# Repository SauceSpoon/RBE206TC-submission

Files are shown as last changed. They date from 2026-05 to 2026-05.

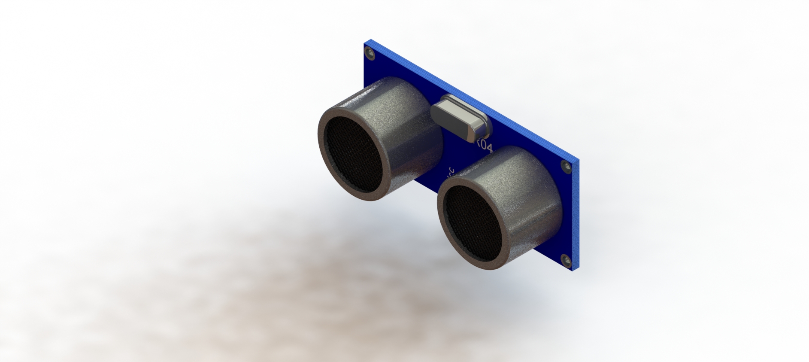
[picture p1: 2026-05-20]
oodk(CAD model)/odk3（Generation 3）/超声波传感器 HC-SR04/Untitled.JPG

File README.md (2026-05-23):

RBE206TC-submission

Some Statement: Due to file path issues, some ESP32 code files may not be decompressed directly, but all CAD and report documents can be opened normally. In order to avoid unnecessary misunderstandings, the code part is stored separately in another compressed package in the mailbox. Even so, most of the functional implementations are still relatively complete.

Project Overview

This repository serves as the final submission for the RBE206TC course. It encompasses the complete project lifecycle, including the firmware source code for ESP32 wireless communication, the mechanical CAD models for the OODK, and the comprehensive final report and presentation slides.

Team Members
Member Name: [Yanyang.Nan, JiaRui.Li, Jian.Wang, Xinhang.Li]

Directory Structure
This repository is organized into the following directories and files:

ESP32-source

Content: Firmware source code for the ESP32 microcontroller.
Functionality: Implements wireless connectivity, flashing procedures, and control logic.

oodk(CAD model)

Content: 3D CAD models of the OODK.
Formats: Includes source files (e.g., SolidWorks/STEP) and renderings.
Purpose: Demonstrates the mechanical structure design and assembly details.

Report and powerpoint

Content: Project documentation.
Includes:
Project Report (PDF/Word)
Presentation Slides (PPT)

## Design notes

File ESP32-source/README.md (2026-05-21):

#ESP32 Robot Graphical Web Control and Burning Station

The first version of the project implemented according to the first phase goals of `esp_32_robot_web_flasher_control_plan.md` contains four parts:

- `apps/web`: React + Vite graphical console
- `apps/server`: Node.js + Express local control service
- `firmware/esp32_robot_controller`: ESP32 Arduino/PlatformIO example firmware
- `firmware/esp32_cam_streamer`: Standalone ESP32-CAM streaming firmware

## Current capabilities

- Enter the IP on the web page and connect to the robot
- The web page independently connects to ESP32-CAM and displays real-time video streams and snapshot previews
- Forward browser control commands to ESP32 through local services
- A new local script chat window has been added to the control page, and Chinese scripts can be used to directly drive the servo.
- Natural language can be planned into a whitelist script through local Ollama / Gemma, and then handed over to the local service for execution
- Supports action buttons, emergency stop, attitude return, and 7-way servo slider
- Upload `.bin` firmware and push to ESP32 via OTA
- The camera module also supports remote upgrade via Wi-Fi OTA
- Reserve USB burning entrance as first time burning/brick rescue mode
- Automatically scan and display available serial devices, and the page will automatically refresh after plugging and unplugging.
- Camera images can be forwarded through the local service proxy, and the stream can also be viewed when the console is opened remotely
- Status, log, delay, battery, motor angle and other information are displayed in real time on the page

## PCA9685 Wiring

- The current firmware outputs servo PWM through PCA9685 and no longer directly uses ESP32 GPIO to control the servo.
- Default I2C wiring: ESP32 `GPIO 21 -> SDA`, `GPIO 22 -> SCL`
- Default servo channel mapping: servo `1/2/3` on the web page corresponds to PCA9685 channel `0/1/2`
- PCA9685 logic power supply `VCC` is recommended to be connected to ESP32 `3.3V`
- Servo power supply `V+` continues to be connected to the output of your buck module
- `ESP32 GND`, `PCA9685 GND`, and the battery negative pole must be grounded together

## Directory structure

```text
ESP32/
├─ apps/
│ ├─ server/ # Local control service
│ └─ web/ # Web console
├─ firmware/
│ ├─ esp32_robot_controller/
│ ├─ include/
│ ├─ src/
│ └─ platformio.ini
│ └─ esp32_cam_streamer/
│ ├─ include/
│ ├─ src/
│ └─ platformio.ini
├─docs/
│ └─ flash-version-workflow.md
├─ .github/workflows/
│ └─ ci.yml
└─ README.md
```

## GitHub warehouse and version management

This directory should be maintained as a single repository for "all robot programming-related codes" to avoid future occurrences:

- Only the board code was changed, but the Web/Server protocol changes were not saved simultaneously.
- Directly overwrites the last stable function, causing a certain ability to be removed.
- The burning was successful, but I can’t find which version of the code it corresponded to when I looked back.

Recommended execution method:

1. Submit the code before each preparation.
2. Add Git tag after each verification is stable.
3. New features are always developed in branches and do not directly cover the stable version.
4. After pushing to GitHub, treat GitHub as the only remote backup.

For the complete process, see [docs/flash-version-workflow.md](/Users/yanyangnan/Desktop/ESP32/docs/flash-version-workflow.md).

## Quick start

### 1. Install dependencies

Execute in the project root directory:

```bash
npm install
```

### 2. Start local service

```bash
npm run dev:server
```

Listens to `http://localhost:3001` by default.

If you need to customize the configuration, copy [apps/server/.env.example](/Users/yanyangnan/Desktop/ESP32/apps/server/.env.example) to `.env` and modify it.

If you want to connect to local Ollama / Gemma, first make sure Ollama is started and the model name can be seen in `ollama list`, and then configure it in [apps/server/.env](/Users/yanyangnan/Desktop/ESP32/apps/server/.env):

```bash
OLLAMA_BASE_URL=http://127.0.0.1:11434
OLLAMA_MODEL=gemma4:26b
OLLAMA_TIMEOUT_MS=30000
```

The model name must use the name displayed in your local `ollama list`; if it is actually called `gemma3:4b`, `gemma3n` or other names, change `OLLAMA_MODEL` to the corresponding value.

### 3. Start the web console

```bash
npm run dev:web
```

The default development address is `http://localhost:5173`.

If you need to modify the API address, copy [apps/web/.env.example](/Users/yanyangnan/Desktop/ESP32/apps/web/.env.example) to `.env`.

### 4. Burn in ESP32 base firmware

Enter [firmware/esp32_robot_controller](/Users/yanyangnan/Desktop/ESP32/firmware/esp32_robot_controller):

```bash
pio run -t upload
```

Before using it for the first time, please copy [include/secrets.example.h](/Users/yanyangnan/Desktop/ESP32/firmware/esp32_robot_controller/include/secrets.example.h) to `secrets.h`, and then modify the Wi‑Fi information in it.

### 5. Burn standalone ESP32-CAM firmware

Enter [firmware/esp32_cam_streamer](/Users/yanyangnan/Desktop/ESP32/firmware/esp32_cam_streamer):

```bash
pio run -t upload
```

Copy [include/secrets.example.h](/Users/yanyangnan/Desktop/ESP32/firmware/esp32_cam_streamer/include/secrets.example.h) to `secrets.h`, fill in Wi‑Fi, and then burn. By default it will provide:

- `/stream`: MJPEG real-time video stream
- `/capture`: single frame capture
- `/status`: camera parameters and online status
- `/health`: health check
- `/update`: camera firmware OTA update entrance

### 6. Unified verification

Before preparing to burn or push to GitHub, it is recommended to execute:

```bash
npm run check
```

This checks in order:

- Is the web front end buildable?
- Whether the syntax of the local server-side JS file passes
- Whether the robot main control firmware can be compiled
- Is the camera firmware compilable?

## Run process

1. Use USB to burn the basic firmware with OTA into ESP32
2. Open the Web console, enter the robot IP and connect
3. Send control commands through action buttons and sliders
4. Select the `.bin` firmware and upload it to the local service
5. Select the burning target (robot master/camera module) and OTA/USB mode
6. Click "Upload and Upgrade", the local service will push the firmware to `/update` of the corresponding device
7. Camera preview uses local service proxies `/api/camera/stream` and `/api/camera/snapshot` by default

## Local Service API

- `POST /api/connect`
- `POST /api/disconnect`
- `POST /api/camera/connect`
- `POST /api/camera/disconnect`
- `GET /api/status`
- `GET /api/camera/status`
- `GET /api/camera/stream`
- `GET /api/camera/snapshot`
- `POST /api/firmware/upload`
- `POST /api/firmware/flash`
- `POST /api/script/run`
- `POST /api/script/stop`
- `POST /api/brain/run`
- `POST /api/control`
- `GET /api/serial/ports`
- `GET /api/health`
- `WS /ws`: Push status and logs to the web frontend

## USB burning instructions

`POST /api/firmware/flash` supports:

- `target: "robot" | "camera"`
- `mode: "ota" | "usb"`

Among them `mode: "usb"` is called by default:

```bash
python3 -m esptool --chip esp32 --port <port> --baud <baudRate> write_flash 0x10000 <file>
```

This is a simplified writing method for OTA application partitions, suitable for devices that already have a basic partition table. If you need to completely burn the bootloader / partitions / app for the first time, please adjust the offset and command strategy in [apps/server/.env.example](/Users/yanyangnan/Desktop/ESP32/apps/server/.env.example).

## ESP32 firmware dependencies

It is recommended to use PlatformIO, which has been declared in [platformio.ini](/Users/yanyangnan/Desktop/ESP32/firmware/esp32_robot_controller/platformio.ini):

- `ESP Async WebServer`
- `AsyncTCP`
- `ArduinoJson`
- `ESP32Servo`

## Suggestions for subsequent expansion

- Automatically scan LAN devices
- Action recording/playback
-Multi-robot switching
- IMU visualization
- Camera streaming
- More complete USB first-time burning process

# ESP32 机器人图形化 Web 控制与烧录台

按 `esp_32_robot_web_flasher_control_plan.md` 的第一阶段目标实现的初版项目，包含四部分：

- `apps/web`：React + Vite 图形化控制台
- `apps/server`：Node.js + Express 本地控制服务
- `firmware/esp32_robot_controller`：ESP32 Arduino / PlatformIO 示例固件
- `firmware/esp32_cam_streamer`：独立 ESP32-CAM 串流固件

## 当前能力

- Web 页面输入 IP 并连接机器人
- Web 页面独立连接 ESP32-CAM，并显示实时视频流与抓拍预览
- 通过本地服务把浏览器控制指令转发到 ESP32
- 控制页新增本地脚本聊天窗口，可用中文脚本直接驱动舵机
- 可通过本地 Ollama / Gemma 把自然语言规划成白名单脚本，再交给本地服务执行
- 支持动作按钮、急停、姿态回中、7 路舵机滑块
- 上传 `.bin` 固件并通过 OTA 推送到 ESP32
- 相机模块同样支持通过 Wi-Fi OTA 远程升级
- 保留 USB 烧录入口，作为首次烧录/救砖模式
- 自动扫描并显示可用串口设备，插拔后页面自动刷新
- 相机画面可通过本地服务代理转发，远程打开控制台时也能看流
- 状态、日志、延迟、电池、电机角度等信息在页面里实时显示

## PCA9685 接线

- 当前固件通过 PCA9685 输出舵机 PWM，不再直接使用 ESP32 GPIO 控舵机
- 默认 I2C 接线：ESP32 `GPIO 21 -> SDA`，`GPIO 22 -> SCL`
- 默认舵机通道映射：网页的舵机 `1/2/3` 对应 PCA9685 通道 `0/1/2`
- PCA9685 逻辑电源 `VCC` 建议接 ESP32 `3.3V`
- 舵机电源 `V+` 继续接你的降压模块输出
- `ESP32 GND`、`PCA9685 GND`、电池负极必须共地

## 目录结构

```text
ESP32/
├─ apps/
│  ├─ server/   # 本地控制服务
│  └─ web/      # Web 控制台
├─ firmware/
│  ├─ esp32_robot_controller/
│     ├─ include/
│     ├─ src/
│     └─ platformio.ini
│  └─ esp32_cam_streamer/
│     ├─ include/
│     ├─ src/
│     └─ platformio.ini
├─ docs/
│  └─ flash-version-workflow.md
├─ .github/workflows/
│  └─ ci.yml
└─ README.md
```

## GitHub 仓库与版本管理

这个目录应作为“机器人所有烧录相关代码”的单一仓库来维护，避免以后出现：

- 只改了板端代码，但没同步保存 Web / Server 协议变更
- 直接覆盖上一次稳定功能，导致某个能力被顶掉
- 烧录成功了，但回头找不到当时对应的是哪一版代码

推荐执行方式：

1. 每次准备烧录前先提交代码。
2. 每次验证稳定后打 Git tag。
3. 新功能一律在分支开发，不直接覆盖稳定版。
4. 推送到 GitHub 后，把 GitHub 当作唯一远程备份。

完整流程见 [docs/flash-version-workflow.md](/Users/yanyangnan/Desktop/ESP32/docs/flash-version-workflow.md)。

## 快速开始

### 1. 安装依赖

在项目根目录执行：

```bash
npm install
```

### 2. 启动本地服务

```bash
npm run dev:server
```

默认监听 `http://localhost:3001`。

如需自定义配置，复制 [apps/server/.env.example](/Users/yanyangnan/Desktop/ESP32/apps/server/.env.example) 为 `.env` 后修改。

如果要接入本地 Ollama / Gemma，先确认 Ollama 已启动并且模型名能在 `ollama list` 里看到，然后在 [apps/server/.env](/Users/yanyangnan/Desktop/ESP32/apps/server/.env) 中配置：

```bash
OLLAMA_BASE_URL=http://127.0.0.1:11434
OLLAMA_MODEL=gemma4:26b
OLLAMA_TIMEOUT_MS=30000
```

模型名必须使用你本机 `ollama list` 显示的名字；如果实际叫 `gemma3:4b`、`gemma3n` 或其他名字，就把 `OLLAMA_MODEL` 改成对应值。

### 3. 启动 Web 控制台

```bash
npm run dev:web
```

默认开发地址为 `http://localhost:5173`。

如需修改 API 地址，复制 [apps/web/.env.example](/Users/yanyangnan/Desktop/ESP32/apps/web/.env.example) 为 `.env`。

### 4. 烧入 ESP32 基础固件

进入 [firmware/esp32_robot_controller](/Users/yanyangnan/Desktop/ESP32/firmware/esp32_robot_controller)：

```bash
pio run -t upload
```

首次使用前请先把 [include/secrets.example.h](/Users/yanyangnan/Desktop/ESP32/firmware/esp32_robot_controller/include/secrets.example.h) 复制为 `secrets.h`，再修改其中的 Wi‑Fi 信息。

### 5. 烧入独立 ESP32-CAM 固件

进入 [firmware/esp32_cam_streamer](/Users/yanyangnan/Desktop/ESP32/firmware/esp32_cam_streamer)：

```bash
pio run -t upload
```

把 [include/secrets.example.h](/Users/yanyangnan/Desktop/ESP32/firmware/esp32_cam_streamer/include/secrets.example.h) 复制为 `secrets.h` 后填好 Wi‑Fi，再烧录。默认会提供：

- `/stream`：MJPEG 实时视频流
- `/capture`：单帧抓拍
- `/status`：相机参数和在线状态
- `/health`：健康检查
- `/update`：相机固件 OTA 更新入口

### 6. 统一校验

在准备烧录或推送到 GitHub 前，建议先执行：

```bash
npm run check
```

这会依次检查：

- Web 前端是否可构建
- 本地服务端 JS 文件是否语法通过
- 机器人主控固件是否可编译
- 相机固件是否可编译

## 运行流程

1. 用 USB 给 ESP32 烧入带 OTA 的基础固件
2. 打开 Web 控制台，输入机器人 IP 并连接
3. 通过动作按钮、滑块发送控制命令
4. 选择 `.bin` 固件，上传到本地服务
5. 选择烧录目标（机器人主控 / 相机模块）和 OTA / USB 模式
6. 点击“上传并升级”，本地服务会把固件推送到对应设备的 `/update`
7. 相机预览默认走本地服务代理 `/api/camera/stream` 和 `/api/camera/snapshot`

## 本地服务 API

- `POST /api/connect`
- `POST /api/disconnect`
- `POST /api/camera/connect`
- `POST /api/camera/disconnect`
- `GET /api/status`
- `GET /api/camera/status`
- `GET /api/camera/stream`
- `GET /api/camera/snapshot`
- `POST /api/firmware/upload`
- `POST /api/firmware/flash`
- `POST /api/script/run`
- `POST /api/script/stop`
- `POST /api/brain/run`
- `POST /api/control`
- `GET /api/serial/ports`
- `GET /api/health`
- `WS /ws`：向 Web 前端推送状态和日志

## USB 烧录说明

`POST /api/firmware/flash` 支持：

- `target: "robot" | "camera"`
- `mode: "ota" | "usb"`

其中 `mode: "usb"` 默认调用：

```bash
python3 -m esptool --chip esp32 --port <port> --baud <baudRate> write_flash 0x10000 <file>
```

这是面向 OTA 应用分区的简化写入方式，适合已具备基本分区表的设备。若你需要首次完整烧录 bootloader / partitions / app，请自行调整 [apps/server/.env.example](/Users/yanyangnan/Desktop/ESP32/apps/server/.env.example) 中的偏移与命令策略。

## ESP32 固件依赖

建议使用 PlatformIO，已在 [platformio.ini](/Users/yanyangnan/Desktop/ESP32/firmware/esp32_robot_controller/platformio.ini) 中声明：

- `ESP Async WebServer`
- `AsyncTCP`
- `ArduinoJson`
- `ESP32Servo`

## 后续扩展建议

- 自动扫描局域网设备
- 动作录制 / 回放
- 多机器人切换
- IMU 可视化
- 摄像头串流
- 更完整的 USB 首次烧录流程

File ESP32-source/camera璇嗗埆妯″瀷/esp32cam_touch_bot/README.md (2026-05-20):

# ESP32-CAM Touch Bot Framework

This is a starter framework for the competition flow:

1. Draw target (color + shape)
2. Camera scans candidates
3. Robot aligns to target
4. Robot approaches and touches target

## Files

- esp32cam_touch_bot.ino: main state machine
- Config.h: pins and thresholds
- VisionPipeline.*: camera + color/shape detection
- ShapeClassifier.*: placeholder shape classifier (replace by model)
- MotorControl.*: simple motor driver wrapper

## How to use

1. Open `esp32cam_touch_bot` folder in Arduino IDE.
2. Select board: `AI Thinker ESP32-CAM`.
3. Install ESP32 board package in Board Manager if needed.
4. Confirm motor pins in Config.h.
5. Set your draw target in Config.h:

```cpp
constexpr TargetSpec TARGET = {ColorId::RED, ShapeId::PYRAMID};
```

6. Upload and open serial monitor at 115200.

## Image collection first

Before model training, complete image collection with the dedicated guide:

- IMAGE_COLLECTION.md

Batch capture script:

- tools/capture_dataset.sh
- tools/collect_12_classes.sh
- tools/audit_dataset.sh
- tools/prepare_photodata.sh
- tools/prepare_shape_model_dataset.sh

Competition classes:

- colors: black, blue, green, red
- shapes: cube, ball, pyramid
- total: 12 labels, e.g. black_cube, blue_ball, red_pyramid

Quick example:

```bash
chmod +x tools/capture_dataset.sh
./tools/capture_dataset.sh -i 192.168.1.88 -l red_cube -n 300 -o dataset/raw -t 0.35
./tools/collect_12_classes.sh -i 192.168.1.88 -n 250 -o dataset/raw -t 0.35
./tools/audit_dataset.sh -d dataset/raw -m 250
./tools/prepare_photodata.sh --clean
./tools/prepare_shape_model_dataset.sh --clean
./tools/prepare_shape_model_dataset.sh --clean -o dataset/shape_model_balanced --max-per-shape 365
```

## Next step: replace shape classifier with Edge Impulse

In `ShapeClassifier.cpp`, replace `classifyShapeHeuristic(...)` with model inference result mapping.

Train the first model from `dataset/shape_model_balanced`:

- input: cropped object image
- outputs: cube, ball, pyramid
- recommended input size: 64x64 or 96x96 RGB
- deployment target: int8 Arduino library

Local PyTorch baseline:

```bash
/Users/yanyangnan/miniforge3/bin/python tools/train_shape_model.py \
  --data-dir dataset/shape_model_balanced \
  --out-dir models/shape_classifier \
  --image-size 96 \
  --epochs 50 \
  --batch-size 32
```

Current baseline result:

- best validation accuracy: 97.26%
- best epoch: 45
- outputs: models/shape_classifier/best.pt, best_torchscript.pt, metrics.json

Robust v2 training for imperfect ROI crops:

```bash
/Users/yanyangnan/miniforge3/bin/python tools/train_shape_model.py \
  --data-dir dataset/shape_model \
  --out-dir models/shape_classifier_v2_full_hard \
  --image-size 96 \
  --epochs 50 \
  --batch-size 32 \
  --aug-profile hard \
  --balanced-sampler \
  --class-weighted-loss
```

Current v2 result:

- best validation accuracy: 92.59%
- best epoch: 44
- outputs: models/shape_classifier_v2_full_hard/best.pt, best_torchscript.pt, metrics.json
- composite test detections: 88, down from 95 with the first model
- practical note: v2 is less overconfident on single-object validation and improves red cube behavior in composite scenes

Composite-scene test:

```bash
/Users/yanyangnan/miniforge3/bin/python tools/test_composite_photos.py \
  --image-dir ../照片/组合 \
  --model models/shape_classifier_v2_full_hard/best.pt \
  --out-dir models/shape_classifier_v2_full_hard/composite_test_strict
```

Live camera test before Arduino deployment:

```bash
# ESP32-CAM CameraWebServer capture endpoint
/Users/yanyangnan/miniforge3/bin/python tools/live_camera_test.py \
  --esp32-ip 192.168.1.88 \
  --target red_cube \
  --frames 0

# USB camera or Mac camera
/Users/yanyangnan/miniforge3/bin/python tools/live_camera_test.py \
  --source 0 \
  --target red_cube \
  --frames 0
```

Hard-example collection from the live ESP32-CAM view:

```bash
/Users/yanyangnan/miniforge3/bin/python tools/live_camera_test.py \
  --esp32-ip 172.20.10.2 \
  --focus-color red \
  --frames 0 \
  --display \
  --collect-dir dataset/live_hard_shape_rois
```

When the displayed ROI is wrong, press the true shape key:

- `c`: choose cube
- `b`: choose ball
- `p`: choose pyramid
- `Enter`: confirm and save the shown ROI
- `Esc`: cancel the pending label
- `q`: quit

Use `--focus-color` to collect one object color at a time. For example, use `--focus-color red` when collecting red cube failure cases, and keep only that target object under the camera.

Task1 marker and boundary calibration images:

```bash
./tools/collect_competition_markers.sh -i 172.20.10.11 -n 150 -o dataset/competition_markers -t 0.35
```

This collects raw images into:

- `yellow_column`: yellow obstacle columns
- `black_column`: the black goal column only
- `black_boundary_line`: boundary line without the goal column
- `background_negative`: floor, shadows, empty scene, and robot body negatives

Use these buckets first for HSV threshold tuning. Train a model only if color rules are not stable enough under competition lighting.

After collecting hard examples, build and train v3:

```bash
./tools/prepare_v3_shape_dataset.sh --clean

/Users/yanyangnan/miniforge3/bin/python tools/train_shape_model.py \
  --data-dir dataset/shape_model_v3_live_hard \
  --out-dir models/shape_classifier_v3_live_hard \
  --image-size 96 \
  --epochs 50 \
  --batch-size 32 \
  --aug-profile hard \
  --balanced-sampler \
  --class-weighted-loss
```

Suggested mapping:

- model output index 0 -> ShapeId::CUBE
- model output index 1 -> ShapeId::BALL
- model output index 2 -> ShapeId::PYRAMID

## Notes

- This version keeps logic light for ESP32-CAM.
- HSV ranges may need tuning for your lighting.
- For better reliability, keep white balance/exposure fixed.

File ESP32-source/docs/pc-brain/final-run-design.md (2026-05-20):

# PC Brain Final Run Design

## Goal

Add a parallel local-computer brain path without deleting or replacing the existing ESP32-side and manual Web control paths.

The PC Brain path is used for the automated teacher-facing flow:

1. Connect the robot controller.
2. Connect the ESP32-CAM.
3. Select the target object.
4. Start PC Brain.
5. The computer reads camera detections, decides the task phase, sends motion commands, and stops automatically.

## Architecture

```text
ESP32-CAM
  -> Python OpenCV detector on the computer
  -> Node PC Brain endpoint
  -> FinalRunManager task state machine
  -> RobotManager / SimulationManager
  -> ESP32 robot controller
```

The original manual control page continues to use `/api/control`. The new PC Brain path uses `/api/pc-brain/*` and only sends robot commands after `/api/pc-brain/start` has been called.

## Responsibilities

- ESP32-CAM: video capture only.
- Python detector: OpenCV frame reading, HSV segmentation, contour extraction, detection JSON posting.
- Node PC Brain: run state, input validation, activity timeout metadata, forwarding detections to FinalRunManager.
- FinalRunManager: competition phase logic and robot motion commands.
- ESP32 robot controller: execute commands, keep OTA/manual control capability, enforce board-side safety timeout.

## Isolation Rules

- Existing code and docs remain in place.
- PC Brain starts stopped by default.
- Vision events posted while PC Brain is stopped are recorded as ignored and do not command the robot.
- Manual Web control remains available when PC Brain is stopped.
- Emergency stop is always allowed.
- If PC Brain is running, ordinary manual movement should be treated as a mode conflict unless the operator stops PC Brain first.

## First Implementation Slice

- Add a `pcBrain` state block to the server snapshot.
- Add a `PcBrainManager` with `start`, `stop`, and `applyVision`.
- Add `/api/pc-brain/start`, `/api/pc-brain/stop`, `/api/pc-brain/vision`, and `/api/pc-brain/status`.
- Add a Python detector client skeleton that reads ESP32-CAM frames and posts detections to the Node service.

## Operator Flow

1. Start the Node server and Web console.
2. Connect the robot controller and ESP32-CAM from the Web console.
3. If the lighting changed, calibrate each color before the run:

```bash
python3 apps/server/tools/pc_brain_opencv.py \
  --camera http://ESP32_CAM_IP/stream \
  --calibrate red
```

Use the HSV sliders until the mask isolates the target color. Press `s` to save the current range to `apps/server/tools/pc_brain_hsv.json`, then press `q` to quit. Repeat for `blue`, `green`, `yellow`, and `black` as needed.

4. Start the Python detector:

```bash
python3 apps/server/tools/pc_brain_opencv.py \
  --camera http://ESP32_CAM_IP/stream \
  --server http://127.0.0.1:3001 \
  --shape-model camera识别模型/esp32cam_touch_bot/models/shape_classifier_v3_live_hard/best.pt \
  --rotate-180 \
  --flip-horizontal \
  --display
```

If the camera is running the Arduino `CameraWebServer` reference sketch, use:

```bash
python3 apps/server/tools/pc_brain_opencv.py \
  --camera http://ESP32_CAM_IP:81/stream \
  --server http://127.0.0.1:3001 \
  --shape-model camera识别模型/esp32cam_touch_bot/models/shape_classifier_v3_live_hard/best.pt \
  --rotate-180 \
  --flip-horizontal \
  --display
```

With `--shape-model`, color is still detected by HSV, but cube/ball/pyramid shape comes from the trained PyTorch model. If the option is omitted, the detector falls back to contour shape heuristics.

5. In the Final Go page, choose the target and click `PC Brain 自动开始`.
6. The detector posts vision frames to `/api/pc-brain/vision`; the server decides and sends movement commands.
7. Click `停止 PC Brain` or the normal emergency stop if the run must be interrupted.

## Rollback

This is additive. To return to the previous workflow, stop PC Brain and keep using the existing Web control page, camera page, and Final Go page.

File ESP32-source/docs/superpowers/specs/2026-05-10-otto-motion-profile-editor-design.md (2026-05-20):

# Otto 动作参数编辑器 Design

**Goal:** 在 Otto 控制页新增一个可持久保存的动作参数编辑器，让用户为每个运动动作单独调节关节幅度，支持恢复当前动作默认值、临时试跑、保存到机器人。

**Architecture:** 机器人端保存每个 Otto 动作的参数档案，Web 端把这些档案渲染成可编辑草稿并通过本地存储记住未保存修改。运动按钮仍然只负责发动作命令；编辑器只负责选中当前动作、调整参数、试跑当前草稿和保存当前草稿。  
试跑通过把草稿作为临时 profile 下发给机器人实现，不写入持久存储；保存则写入 ESP32 `Preferences`，并同步回 Web 状态。

**Tech Stack:** React, Vite, ESP32 Arduino, `Preferences`, `ArduinoJson`, localStorage

---

## Scope

### In scope
- Otto 控制页新增“动作参数编辑器”
- 支持动作档案：`otto_forward`、`otto_backward`、`otto_left`、`otto_right`、`otto_shift_left`、`otto_shift_right`
- 每个动作独立保存一组关节幅度参数
- 支持“恢复当前动作默认值”
- 支持“测试当前动作”
- 支持“保存到机器人”
- Web 重启后保留未保存草稿
- 机器人重启后保留已保存参数

### Out of scope
- 不修改 Otto 的相位/偏移公式，只暴露幅度参数
- 不把“恢复默认值”做成自动写入持久存储
- 不改其他普通舵机零位校准逻辑

## Data Model

### Otto motion profile
Each profile stores four floats:
- `leftLegAmplitudeDeg`
- `rightLegAmplitudeDeg`
- `leftHipAmplitudeDeg`
- `rightHipAmplitudeDeg`

### Profile defaults
Defaults stay aligned with current gait logic:
- `otto_forward` and `otto_backward`
  - left leg 12.0
  - right leg 10.5
  - left hip 18.0
  - right hip 16.5
- `otto_left`
  - left leg 18.0
  - right leg 7.0
  - left hip 12.0
  - right hip 12.0
- `otto_right`
  - left leg 7.0
  - right leg 18.0
  - left hip 12.0
  - right hip 12.0
- `otto_shift_left` and `otto_shift_right`
  - left leg 12.0
  - right leg 12.0
  - left hip 10.0
  - right hip 10.0

### Persistence rules
- Robot-side saved profiles live in `Preferences`
- Web-side drafts live in `localStorage`
- If the user never clicks save, the last draft stays in the browser after refresh/reopen
- If the user clicks save, the robot-side profile becomes the saved value that future button presses use

## UI Behavior

### Movement area
- Buttons still execute the current Otto motion immediately
- Buttons do not save or reset profiles
- Clicking a motion button does not need to auto-switch the editor if that would make the separation feel too tight

### Editor area
- Shows one selected motion profile at a time
- Includes:
  - motion selector buttons for the six Otto motions
  - four sliders for the current motion profile
  - `恢复当前动作默认值`
  - `测试当前动作`
  - `保存到机器人`
- `恢复当前动作默认值` only resets the current draft to the built-in default for that motion
- `测试当前动作` sends the current draft as a temporary override and starts that motion once
- `保存到机器人` writes the current draft into robot storage and keeps it after robot or Web restart

### Slider constraints
- Use a single safe slider range for all four fields
- Clamp on both client and firmware side
- Preferred range: `0.0` to `30.0`, step `0.5`

## Firmware Behavior

### Status payload
Expose:
- saved Otto motion profiles
- built-in Otto motion profile defaults
- current active Otto mode

### Control commands
- `move` may accept an optional `profile` object
  - when present for an Otto motion, it acts as a temporary runtime override
  - it is not persisted
- new save command:
  - `type: "otto_motion_profile_save"`
  - fields: `direction`, `profile`
  - persists the profile to `Preferences`
  - does not have to stop or restart the current gait

### Runtime rules
- Current gait evaluation reads from saved profile by default
- When a temporary profile override is present, the current run uses that override until the motion stops
- Restoring defaults in the UI only changes the draft, not the robot store

## Web Behavior

### Draft management
- Initialize drafts from robot status if saved profiles exist
- Merge with browser-local drafts so unsaved changes survive reload
- Key drafts by robot identity when available, otherwise by a stable fallback key

### API interactions
- `测试当前动作` posts `move` with `profile`
- `保存到机器人` posts `otto_motion_profile_save`
- After save, update the local draft cache to match the saved value

## Testing

- Add firmware tests for:
  - default Otto motion profiles
  - status payload includes saved/default motion profiles
  - `move` with a temporary profile override is wired through
  - save command persists the selected profile
- Add Web tests or snapshot checks for:
  - editor renders six motion selectors
  - `恢复当前动作默认值` only affects the current draft
  - `测试当前动作` and `保存到机器人` call the right payloads
  - local draft persistence is keyed and restored on reload

## Files to Change

- `firmware/esp32_robot_controller/src/main.cpp`
- `firmware/esp32_robot_controller/robot-config.test.mjs`
- `apps/web/src/App.jsx`
- `apps/web/src/pages/ControlPage.jsx`
- `apps/web/src/dashboard-config.jsx`
- `apps/web/src/styles.css`

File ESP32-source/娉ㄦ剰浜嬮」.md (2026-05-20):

# 注意事项

用于记录项目中已经遇到并解决过的问题，方便后续排查时直接复用结论。

## 记录规则

- 每次出现问题并确认解决后，追加一条记录。
- 记录至少包含：日期、现象、原因、解决方案、结果。
- 如果问题和硬件接线、串口、烧录、网络或参数配置有关，尽量写清具体端口、通道号或命令。

## 问题记录

### 2026-05-13 当前运动调试范围

- 现象：Web 中存在 `OTTO 仿真` 和 `3D 工作台` 页面，但当前实体机器人调试阶段暂时不用这两个区域。
- 原因：目前调参重点是实体机器人通过 Web 按钮、后端、ESP32 固件和 PCA9685 舵机驱动形成的真实控制链路；仿真和 3D 工作台结果不作为当前运动效果判断依据。
- 处理约定：后续调整 Otto 运动逻辑、稳定区/激进区参数、舵机通道、PCA9685 状态和 Wi-Fi OTA 时，不主动修改或依赖 `OTTO 仿真`、`3D 工作台` 两个区域。
- 结果：当前应优先检查 `实时控制区(Otto)`、稳定区/激进区按钮 payload、后端 `/api/control`、ESP32 `/status` 和固件 Otto 步态逻辑。

### 2026-04-27 重新烧录 `esp32_robot_controller` 时上传中断

- 现象：首次上传时串口提示 `Could not open /dev/cu.usbserial-0001`，提升权限后再次上传又出现 `The chip stopped responding`。
- 原因：第一次是串口访问权限受限；第二次已经连上板子，但在写入早期阶段板子短暂失去响应，属于烧录过程中的通信不稳定。
- 解决方案：保留已编译固件不变，继续使用 `/dev/cu.usbserial-0001` 重试上传；第二次重试后完整写入 bootloader、分区表和主固件，并通过校验。
- 结果：烧录成功，设备已自动复位，新舵机通道映射已写入固件。

### 2026-04-27 单舵机测试后机器人连接自动断开

- 现象：在舵机调节区测试单个舵机后，机器人 websocket 连接自动断开，需要重新连接。
- 原因：固件里的 `SERVO_INVERTED` 配置与注释不一致，右侧三关节本应反向，但实际把 `左胯qh` 设成了反向、`右胯qh` 没反向，容易导致某一路测试时方向错误、机械顶死或电流突增；同时服务端原先在掉线后不会自动重连。
- 解决方案：将 `SERVO_INVERTED` 修正为右膝、右胯zy、右胯qh 反向；前端手动滑块限制到固件角度范围；服务端新增掉线自动重连逻辑并已重启生效。
- 结果：代码侧修正已完成，服务端已生效；固件部分还需要在主控重新接上 USB 串口后再重烧一次才能完全生效。

### 2026-04-27 Web “一键归中” 与装配时的归中基准不一致

- 现象：点击 Web 里的“一键归中”后，部分舵机会歪；但装配舵机时，曾用独立测试程序把 PCA9685 输出到物理 90 度后再安装舵盘。
- 原因：Web 原来的“一键归中”实际走的是“按已保存零位偏移归中”，不是“回到物理 90 度”；如果之前保存过零位偏移，姿态就会和装配时的基准不一致。
- 解决方案：将按钮语义改清楚。“按零位归中”保留原行为；另一个按钮改为“清零偏移并归中”，执行清空全部零位偏移后再统一回到物理 90 度，这与装配时的归中程序一致。
- 结果：前端逻辑和文案已修正，后续如果要回到装配时的机械中位，应使用“清零偏移并归中”。

### 2026-04-27 回到装配归中后左右腿偏差仍不一致

- 现象：点击“回到装配归中（物理90°）”后，两条腿偏的角度不一样，不是简单的整体一起偏。
- 原因：这是“全局中点基准”和“每个舵机自己的机械零位”叠加后的结果。全局上，当前固件原先的脉宽范围与装配时测试程序不一致；个体上，不同舵机的舵盘齿位、安装角度和左右镜像会带来不同的零位误差。
- 解决方案：把固件脉宽范围改为与装配程序一致的基准（对应 `SERVOMIN=110`、`SERVOMAX=510`）；同时在 Web 中新增“把当前姿态设为零位”，用于在分别调好各舵机后一次性保存新的零位。
- 结果：代码已修正并通过构建；固件改动需要重新刷入主控后生效。

### 2026-04-27 左右胯 qh 单舵机控制前后方向相反

- 现象：在舵机控制区单独调 `左胯qh`、`右胯qh` 时，期望往前却实际往后，两个 `qh` 的前后逻辑都反了。
- 原因：这两路在固件 `SERVO_INVERTED` 中的反向配置与当前机械安装方向不匹配。
- 解决方案：将 `SERVO_INVERTED` 中 `左胯qh`、`右胯qh` 的反向位切回当前机械结构对应的方向配置。
- 结果：固件代码已修正并编译通过，重新刷入主控后生效。

### 2026-04-28 PCA9685 运行中掉线后长期保持未就绪

- 现象：机器人在线，但 Web 显示 `PCA9685 未识别` / `PCA9685 not ready`，且 `servoWriteFailures` 持续暴涨。
- 原因：旧固件只在启动时探测一次 PCA9685；一旦运行中写失败，就把 `servoDriverReady` 置为 `false`，之后不会自动重试恢复。
- 解决方案：新增 PCA9685 自愈逻辑。驱动未就绪时按固定间隔自动重探测；重连成功后自动恢复当前保存的舵机姿态；同时取消“未就绪时每次控制都累加失败计数”的行为。
- 结果：固件代码已修正并编译通过，刷入主控后生效。

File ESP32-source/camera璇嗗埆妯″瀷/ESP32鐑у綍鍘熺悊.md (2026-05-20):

# ESP32-CAM 烧录原理说明

## 1. Flash 的分块结构

ESP32的Flash存储器（通常4MB或更多）被划分为多个"分区"（partition），每个区域有不同的用途：

```
ESP32 Flash 布局（示例，4MB）
┌─────────────────────────────────────┐
│ bootloader      (约 20KB)           │ ← 启动引导程序，决定运行哪个app
├─────────────────────────────────────┤
│ partition_table (约 4KB)            │ ← 分区表，描述flash布局
├─────────────────────────────────────┤
│ app0           (约 1.5MB)           │ ← 你的主程序（CameraWebServer等）
├─────────────────────────────────────┤
│ app1/ota       (约 1.5MB, 可选)     │ ← OTA升级备用分区
├─────────────────────────────────────┤
│ nvs            (约 20KB)            │ ← 非易失性存储（WiFi密码、配置等）
├─────────────────────────────────────┤
│ phy_init       (约 4KB)             │ ← 无线电PHY初始化数据
├─────────────────────────────────────┤
│ spiffs         (剩余空间, 可选)     │ ← 文件系统（可以存图片、网页等）
└─────────────────────────────────────┘
```

## 2. Arduino IDE 烧录时写入的内容

当你点击"上传"时，Arduino IDE会烧录以下部分：

```
烧录的内容：
✓ bootloader.bin      ← 引导程序（除非定制，一般不变）
✓ partition-table.bin ← 分区表（除非定制，一般不变）
✓ 你的程序.bin        ← 这是你的代码编译出来的二进制文件
✗ WiFi配置等数据      ← 不会烧录，每次运行时写入
```

**关键点：**
- 每次烧录都会**完全覆盖** `app0` 分区（你的程序）
- `bootloader` 和 `partition-table` 通常只在必要时更新
- **NVS分区不会被烧录覆盖**（但运行时程序会读写它）

## 3. 哪些东西是"新程序自带的"？

| 项目 | 存储位置 | 烧录时是否覆盖 | 说明 |
|---|---|---|---|
| 你的代码逻辑 | app0 | ✓ 覆盖 | 这是核心 |
| WiFi SSID/密码 | 代码中硬编码 | ✓ 覆盖 | 写死在程序里 |
| 配置参数 | NVS | ✗ 不覆盖 | 需程序清除或手动擦除 |
| 摄像头校准数据 | NVS | ✗ 不覆盖 | 需程序清除或手动擦除 |
| SPIFFS中的文件 | SPIFFS分区 | 看情况 | 取决于是否勾选"擦除Flash" |

## 4. 实际例子：CameraWebServer

**烧录前你在代码里设置的：**
```cpp
// 在 CameraWebServer.ino 中
#define WIFI_SSID "你的WiFi名称"
#define WIFI_PASSWORD "你的WiFi密码"

// 相机模型选择
#define CAMERA_MODEL_AI_THINKER
```

这些会**编译进程序**，烧录后固定在 `app0` 分区。

**运行时动态产生的：**
- 连上WiFi后获得的IP地址（存在运行内存，重启重新获取）
- 用户在网页上的设置（如果程序支持存NVS，会保留）

## 5. 再烧录另一个程序时会发生什么？

**场景：** 你已经烧录了CameraWebServer，现在要烧录自己的识别程序

```
操作步骤：
1. 在Arduino IDE打开你的新程序
2. 点击"上传"

结果：
┌─────────────────────────────────────┐
│ 旧内容          新内容              │
├─────────────────────────────────────┤
│ bootloader  →   bootloader          │ ← 一般不变
│ partition   →   partition           │ ← 一般不变
│ CameraWebServer → 你的识别程序      │ ← 完全替换！
│ nvs数据    →   nvs数据（保留）      │ ← 不擦除！
└─────────────────────────────────────┘
```

**可能遇到的问题：**

如果你旧程序在NVS里存了配置，新程序可能会读出这些"旧配置"并报错。

**解决方法：**
```cpp
// 在你的 setup() 开始时添加
preferences.begin("my-app", false);
preferences.clear();  // 清除旧数据
preferences.end();
```

或者在Arduino IDE上传时：
- 工具 → **Erase All Flash Before Sketch Upload**（擦除全部后再上传）

## 6. 如何查看当前分区表？

在Arduino IDE：
1. 按住Shift键，点击"上传"
2. 观察底部日志，会看到类似：
   ```
   Writing at 0x00001000... (partition table)
   Writing at 0x00008000... (bootloader)
   Writing at 0x00010000... (application)
   ```

或者查看你的分区表定义文件：
- Arduino IDE：工具 → Partition Scheme（可以选择不同的方案）

## 7. 实用建议

**对于你当前的ESP32-CAM项目：**

1. **CameraWebServer采集阶段**：
   - 只用它来抓图
   - 不需要关心配置保留

2. **切换到识别程序时**：
   - 建议先勾选"擦除全部Flash"
   - 避免读取到旧的WiFi配置或校准数据

3. **如果你想在程序间保留数据**：
   - 使用SPIFFS或LittleFS文件系统
   - 或者在代码里明确处理NVS的读取/清除

## 8. 常见疑问

**Q: 我修改了代码，只上传了部分内容？**
A: 不对，每次"上传"都是完整替换 app0 分区

**Q: WiFi密码会保留吗？**
A: 取决于程序。如果新程序代码里写死了WiFi配置，就只用代码里的；如果程序读取NVS，可能会读到旧的

**Q: 如何彻底清空ESP32？**
A: Arduino IDE：工具 → "Erase All Flash Before Sketch Upload" → 上传任意程序

**Q: 我可以保留CameraWebServer同时添加我的识别代码吗？**
A: 可以！把两个代码合并，或者让CameraWebServer的网页调用你的识别功能

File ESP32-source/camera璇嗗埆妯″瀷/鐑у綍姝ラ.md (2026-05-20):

# 烧录步骤与图像采集流程

你现在卡在最关键的一步，我先给你在工程里补一份可直接照做的采集手册和一键抓图脚本，目标是今天就把四种颜色和四种形状的数据采出来。

接下来我会先查看现有工程目录，然后新增采集文档与脚本。

## 已创建的文件

已添加以下文件到你的工程中：

- `tools/capture_dataset.sh` - 批量抓图脚本
- `IMAGE_COLLECTION.md` - 采集文档
- `tools/` - 工具目录
- `README.md` - 已加入采集流程入口

采集文档和抓图脚本已经加好了，你现在可以按流程一步步执行。

## 核心文件

你现在有这两个核心文件：
- **采集手册：** `IMAGE_COLLECTION.md`
- **批量抓图脚本：** `tools/capture_dataset.sh`
- **README** 也已加入口：`README.md`

## 硬件准备（必需）

### ESP32-CAM 连接电脑

ESP32-CAM **没有USB接口**，需要使用**USB转TTL模块**（常见型号：CP2102、CH340、FT232）来连接。

### 接线方式

**USB转TTL模块 ←→ ESP32-CAM**

```
USB转TTL      ESP32-CAM
--------      ----------
5V      →     5V
GND     →     GND
RX      →     TX
TX      →     RX
```

**重要：**
- RX和TX要交叉接（TTL的RX接ESP32的TX，TTL的TX接ESP32的RX）
- **烧录时**：用杜邦线将 **IO0 接 GND**（进入下载模式）
- **烧录完成后**：断开 IO0 和 GND 的连接，按ESP32上的重启按钮

### 你需要的硬件清单

1. ESP32-CAM 开发板
2. USB转TTL模块（CP2102或CH340）
3. 杜邦线若干（至少5根：5V、GND、RX、TX、IO0）
4. 电脑（Mac/Windows/Linux都可以）

## 5步完成初始图像采集

1. **硬件连接**：按上面的接线方式连接ESP32-CAM到电脑
2. **烧录固件**：在 Arduino IDE 烧录示例 CameraWebServer 到 ESP32-CAM
   - 打开 Arduino IDE → 文件 → 示例 → ESP32 → Camera → CameraWebServer
   - 选择开发板：AI Thinker ESP32-CAM
   - 修改代码：选择相机模型为 AI Thinker，填入你的WiFi SSID和密码
   - IO0接GND，点击上传
   - 上传完成后断开IO0，按重启按钮
3. **查看IP地址**：串口监视器 115200 查看设备 IP
4. **测试抓图**：先在浏览器打开 `http://你的IP/capture`，确认单张抓图可用
5. **批量采集**：
   ```bash
   # 进入工程目录
   cd /Users/yanyangnan/Desktop/camera识别模型/esp32cam_touch_bot

   # 给脚本执行权限
   chmod +x tools/capture_dataset.sh

   # 开始采集第一类（示例）
   ./tools/capture_dataset.sh -i 192.168.1.88 -l red_cube -n 300 -o dataset/raw -t 0.35
   ```

## 12类标签建议

然后把 12 个类别都跑一遍，标签建议用：

```
black_cube, black_ball, black_pyramid
blue_cube, blue_ball, blue_pyramid
green_cube, green_ball, green_pyramid
red_cube, red_ball, red_pyramid
```

## 容易卡住的点（你现在最需要盯）

### 上传失败
先把 IO0 接 GND 进下载模式，烧录后再断开并重启

### 抓图失败
确认手机/电脑和 ESP32 在同一局域网

### 图片全糊
把抓图间隔从 0.35 提到 0.5 或 0.7，拍摄时慢慢移动物体

### 数据无效
每类必须覆盖 正放/侧放/斜放、远近变化、不同光照

## 下一步

如果你愿意，我下一步可以直接给你一份"12 类一键连续采集命令清单"，你只要复制粘贴执行，不用手动想每个标签。

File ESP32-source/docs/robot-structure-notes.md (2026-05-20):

# 机器人结构档案

更新时间：2026-04-28

## 当前确认信息

- 机器人类型：双足机器人
- 腿部数量：2 条腿
- 总舵机数：6 个
- 每条腿 3 个舵机
- 每条腿自由度：3 自由度

## 单腿关节分配

每条腿的 3 个舵机分配如下：

- 膝关节：1 个舵机
- 髋关节：2 个舵机

其中髋关节的 2 个自由度为：

- 前后摆动自由度
- 左右摆动自由度

## 当前机械结构理解

基于 `odk2` 原始模型、`机器人样子/odk2.STEP` 和截图，当前对整机结构的理解如下：

- 这是一个双足、6 舵机的人形下肢结构
- 两侧腿根靠近机身的位置为髋关节双舵机结构
- 每条腿中下部有 1 个膝关节舵机
- 脚部为较大的落地支撑结构，目标偏向稳定站立
- 机身上方为电子平台/硬件仓

## 当前已识别的电子与硬件模块

在模型中已识别出以下模块：

- `ESP32`
- `PCA9685`
- `MPU6050`
- `XH-M401 Buck converter (XL4016E1)`
- `28BYJ-48 Step Motor`

## 当前系统架构理解

- 主控板：ESP32
- 舵机驱动：PCA9685
- 姿态传感器：MPU6050
- 电源模块：Buck 降压模块
- 机械主体：双足下肢 + 机身硬件仓

## 模型来源

- 原始 SolidWorks 模型目录：`odk2/`
- 当前导出的整机 STEP：`机器人样子/odk2.STEP`
- 当前截图目录：`机器人样子/`

## 后续约定

后续如无特别说明，控制命名、运动学分析、接线映射和软件接口设计，均基于这份结构理解继续推进。

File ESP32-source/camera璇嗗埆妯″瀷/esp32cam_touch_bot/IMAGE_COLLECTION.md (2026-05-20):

# ESP32-CAM Image Collection Guide

This guide helps you pass the data collection stage reliably before model training.

## 1. Goal

Collect images for your own classes:

- 4 colors x 3 shapes = 12 labels
- Example labels:
  - black_cube, black_ball, black_pyramid
  - blue_cube, blue_ball, blue_pyramid
  - green_cube, green_ball, green_pyramid
  - red_cube, red_ball, red_pyramid

Minimum target:

- 250 to 300 images per class
- total 3000 to 3600 images

## 2. Flash CameraWebServer (for capture endpoint)

In Arduino IDE:

1. Open Examples -> ESP32 -> Camera -> CameraWebServer
2. Set board to AI Thinker ESP32-CAM
3. In code:
   - set camera model to AI Thinker
   - fill Wi-Fi SSID and password
4. Enter download mode (IO0 -> GND), upload firmware, then reboot
5. Open Serial Monitor (115200) and read camera IP

When successful, you should see a URL like:

- http://192.168.x.x

The endpoint used for batch capture is:

- http://192.168.x.x/capture

## 3. Prepare folders

From project root:

- mkdir -p dataset/raw

## 4. Batch capture with script

This repo includes:

- tools/capture_dataset.sh
- tools/collect_12_classes.sh
- tools/audit_dataset.sh
- tools/prepare_photodata.sh
- tools/prepare_shape_model_dataset.sh

Make it executable once:

- chmod +x tools/capture_dataset.sh

Capture one class example:

- ./tools/capture_dataset.sh -i 192.168.1.88 -l red_cube -n 300 -o dataset/raw -t 0.35

Collect all 12 classes interactively:

- ./tools/collect_12_classes.sh -i 192.168.1.88 -n 250 -o dataset/raw -t 0.35

Audit whether all classes reach your target count:

- ./tools/audit_dataset.sh -d dataset/raw -m 250

Normalize the existing manually captured folders:

- ./tools/prepare_photodata.sh --clean

Build the 3-class shape training dataset:

- ./tools/prepare_shape_model_dataset.sh --clean

Build a balanced shape dataset for the first Edge Impulse run:

- ./tools/prepare_shape_model_dataset.sh --clean -o dataset/shape_model_balanced --max-per-shape 365

Meaning:

- -i: ESP32 IP
- -l: class label
- -n: image count
- -o: output root directory
- -t: time gap between frames (seconds)

## 5. Recommended collection protocol

For each class, split your 300 images by condition:

- 80 images: front view, center
- 80 images: rotated and tilted
- 80 images: different distance and position
- 60 images: clutter / partial occlusion / hard light

Do this under at least 2 lighting conditions.

## 6. Quality checklist (must pass)

Before training, quickly inspect each class folder:

1. No blurry burst set (remove obvious blur)
2. No wrong class images
3. Background is diverse (not one desk only)
4. Object scale varies (near and far)
5. Pose varies (upright, side, tilt)

If a class performs badly later, first check dataset quality, not model settings.

## 7. Suggested next step after collection

1. Split train/validation (80/20)
2. Start with shape model (3 classes) using color-filtered ROI
3. Keep color as HSV rule-based on-device

This gives faster and more stable deployment on ESP32-CAM.

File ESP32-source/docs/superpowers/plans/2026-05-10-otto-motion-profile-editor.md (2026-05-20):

# Otto 动作参数编辑器 Implementation Plan

> **For agentic workers:** REQUIRED SUB-SKILL: Use superpowers:subagent-driven-development (recommended) or superpowers:executing-plans to implement this plan task-by-task. Steps use checkbox (`- [ ]`) syntax for tracking.

**Goal:** 给 Otto 控制页增加可持久保存的动作参数编辑器，支持每个动作独立调参、临时试跑、恢复当前动作默认值，以及保存到机器人后长期生效。

**Architecture:** 机器人端保存一份“已保存动作档案”，Web 端维护一份“当前草稿档案”。运动按钮只触发动作；编辑器只编辑当前动作档案。试跑通过 `move` 请求携带临时 profile 覆盖值实现，不写入持久存储；保存通过独立命令写入 `Preferences`，并让 `/status` 公开当前已保存档案，方便 Web 载入和回显。  
为了防止刷新丢失，Web 再加一层 `localStorage`，只缓存未保存的草稿。

**Tech Stack:** ESP32 Arduino, `Preferences`, `ArduinoJson`, React, Vite, browser `localStorage`

---

### Task 1: Define Otto profile data and firmware commands

**Files:**
- Modify: `firmware/esp32_robot_controller/src/main.cpp`
- Modify: `firmware/esp32_robot_controller/robot-config.test.mjs`

- [ ] **Step 1: Write the failing test**

```js
test('Otto motion profiles are exposed in status and include defaults', () => {
  assert.match(firmware, /ottoMotionProfiles/);
  assert.match(firmware, /otto_motion_profile_save/);
  assert.match(firmware, /move.*profile/);
});
```

- [ ] **Step 2: Run test to verify it fails**

Run: `node --test firmware/esp32_robot_controller/robot-config.test.mjs`
Expected: FAIL because Otto profile fields and save command are not yet present.

- [ ] **Step 3: Write minimal implementation**

```cpp
struct OttoMotionProfile {
  float leftLegAmplitudeDeg;
  float rightLegAmplitudeDeg;
  float leftHipAmplitudeDeg;
  float rightHipAmplitudeDeg;
};
```

- [ ] **Step 4: Run test to verify it passes**

Run: `node --test firmware/esp32_robot_controller/robot-config.test.mjs`
Expected: PASS.

- [ ] **Step 5: Commit**

```bash
git add firmware/esp32_robot_controller/src/main.cpp firmware/esp32_robot_controller/robot-config.test.mjs
git commit -m "feat: add otto motion profile persistence"
```

### Task 2: Add Otto profile editor state and UI

**Files:**
- Modify: `apps/web/src/App.jsx`
- Modify: `apps/web/src/pages/ControlPage.jsx`
- Modify: `apps/web/src/dashboard-config.jsx`
- Modify: `apps/web/src/styles.css`

- [ ] **Step 1: Write the failing test**

```js
// In a web test or smoke check:
assert.match(dashboardConfig, /otto_motion_profile/);
assert.match(controlPageSource, /恢复当前动作默认值/);
assert.match(controlPageSource, /测试当前动作/);
assert.match(controlPageSource, /保存到机器人/);
```

- [ ] **Step 2: Run test to verify it fails**

Run: `npm --workspace @esp32-robot/web run build`
Expected: FAIL because the new editor props and handlers are missing.

- [ ] **Step 3: Write minimal implementation**

```jsx
const [ottoMotionDrafts, setOttoMotionDrafts] = useState(() => loadDraftsFromStorage());
const [selectedOttoMotion, setSelectedOttoMotion] = useState('otto_forward');
```

- [ ] **Step 4: Run test to verify it passes**

Run: `npm --workspace @esp32-robot/web run build`
Expected: PASS.

- [ ] **Step 5: Commit**

```bash
git add apps/web/src/App.jsx apps/web/src/pages/ControlPage.jsx apps/web/src/dashboard-config.jsx apps/web/src/styles.css
git commit -m "feat: add otto motion profile editor ui"
```

### Task 3: Persist drafts in browser storage

**Files:**
- Modify: `apps/web/src/App.jsx`

- [ ] **Step 1: Write the failing test**

```js
assert.match(appSource, /localStorage/);
assert.match(appSource, /ottoMotionDrafts/);
```

- [ ] **Step 2: Run test to verify it fails**

Run: `npm --workspace @esp32-robot/web run build`
Expected: FAIL because draft hydration/persistence is not wired yet.

- [ ] **Step 3: Write minimal implementation**

```jsx
useEffect(() => {
  window.localStorage.setItem('ottoMotionDrafts', JSON.stringify(ottoMotionDrafts));
}, [ottoMotionDrafts]);
```

- [ ] **Step 4: Run test to verify it passes**

Run: `npm --workspace @esp32-robot/web run build`
Expected: PASS.

- [ ] **Step 5: Commit**

```bash
git add apps/web/src/App.jsx
git commit -m "feat: persist otto motion drafts"
```

### Task 4: Verify end-to-end behavior and tighten tests

**Files:**
- Modify: `firmware/esp32_robot_controller/robot-config.test.mjs`
- Modify: `apps/web/src/simulation-3d.integration.test.mjs` or add a focused web smoke test if needed

- [ ] **Step 1: Write the failing test**

```js
test('saved profile survives status reload and temporary test profile does not overwrite storage', () => {
  assert.ok(true);
});
```

- [ ] **Step 2: Run test to verify it fails**

Run: `node --test firmware/esp32_robot_controller/robot-config.test.mjs`
Expected: FAIL until the profile save/load flow is fully wired.

- [ ] **Step 3: Write minimal implementation**

Keep the test focused on concrete behavior:
- saved profile comes back from `/status`
- test-run payload uses inline profile override
- restore-default only changes the selected draft

- [ ] **Step 4: Run test to verify it passes**

Run:
`node --test firmware/esp32_robot_controller/robot-config.test.mjs`
`npm --workspace @esp32-robot/web run build`
Expected: PASS.

- [ ] **Step 5: Commit**

```bash
git add firmware/esp32_robot_controller/robot-config.test.mjs apps/web/src/simulation-3d.integration.test.mjs
git commit -m "test: cover otto motion profile editor flow"
```

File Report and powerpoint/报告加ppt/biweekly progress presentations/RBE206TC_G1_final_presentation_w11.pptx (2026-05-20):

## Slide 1

Otto Robot

PROJECT FINAL PRESENTATION

Group1： Yangnan.yan 2363610
Jiarui.li 2360655
xinhang.li 2363444
Jian.wang 2362488

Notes: 大家好，欢迎来到我们的Otto机器人项目最终展示。今天，我们将向大家汇报一款集智能感知与自主行走于一体的四足机器人。这个项目不仅是一次技术实践，更是我们探索机器人自主行为与智能控制的起点。接下来，我们将详细介绍项目的背景、核心功能、技术突破以及最终成果。

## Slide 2

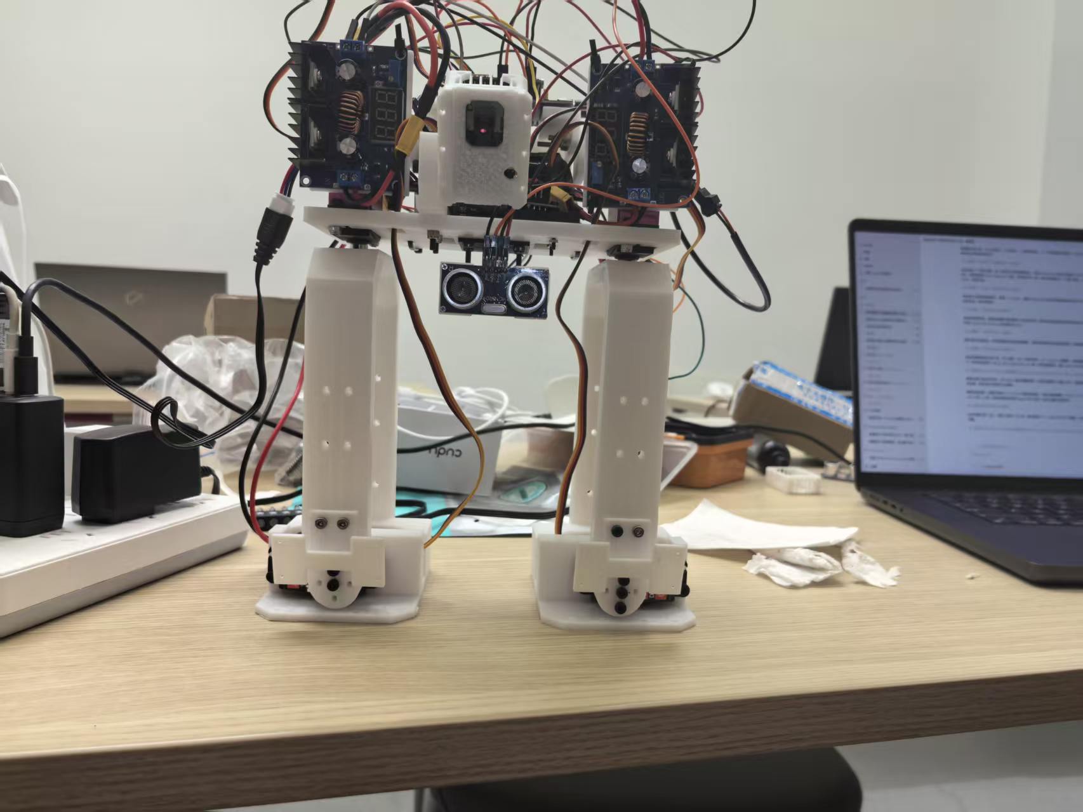
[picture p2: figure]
be2546149b08a110830f88db6aa4f05b

System overview

This project uses ESP32 with a camera and lightweight YOLOv11-Nano model to identify blocks. The robot performs corresponding movements to realize vision-based autonomous operation.

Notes: 首先，让我们了解一下项目的背景和目标。我们的Otto机器人项目，旨在探索小型机器人的智能感知与自主行走能力。我们的核心目标非常明确：实现稳定的自主行走，集成摄像头和超声波传感器以感知环境，让机器人能根据视觉信息做出反应，并提供可靠的远程遥控作为安全保障。

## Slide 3

Process：
1. The ultrasonic module conducts detection, avoiding large cylindrical obstacles.
2. At the same time, using the esp32 camera, the target object is identified and the robot moves towards the target object.

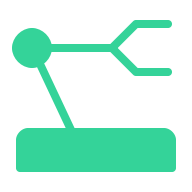
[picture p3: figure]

System overview

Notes: 首先，让我们了解一下项目的背景和目标。我们的Otto机器人项目，旨在探索小型机器人的智能感知与自主行走能力。我们的核心目标非常明确：实现稳定的自主行走，集成摄像头和超声波传感器以感知环境，让机器人能根据视觉信息做出反应，并提供可靠的远程遥控作为安全保障。

## Robot structure design

- 01

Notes: 1.7.2013

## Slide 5

Project Challenges & Solutions

First-Generation Design Failure
The long-leg and high-DOF design resulted in an oversized structure. Medium servos lacked sufficient torque to drive the robot, forcing a project redesign.
Mismatched Servo Torque & Load
The initial leg torque requirements exceeded the servo performance limits, causing instability, weak movements, and an inability to walk normally.So we changed the structure.

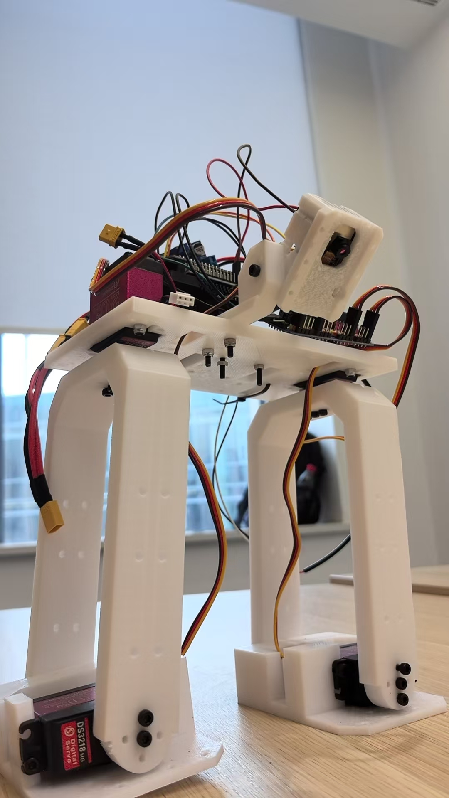
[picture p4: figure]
e4dd892dd40c0f6aed126bcd849d62b0

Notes: 第二个技术突破在于视觉模型的训练。我们深知高质量数据的重要性，因此采集了超过1800张图片，并通过数据增强技术扩充了数据集。我们选择了轻量级的MobileNet-SSD模型，并经过反复训练，最终实现了超过98%的识别准确率，成功地将“火眼金睛”赋予了机器人。

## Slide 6

Project Challenges & Solutions

Generation 1
Concept: Long legs + high degrees of freedom
Problem: Medium servos cannot provide enough torque
R
esult: Too large structure, unable to walk, suspended

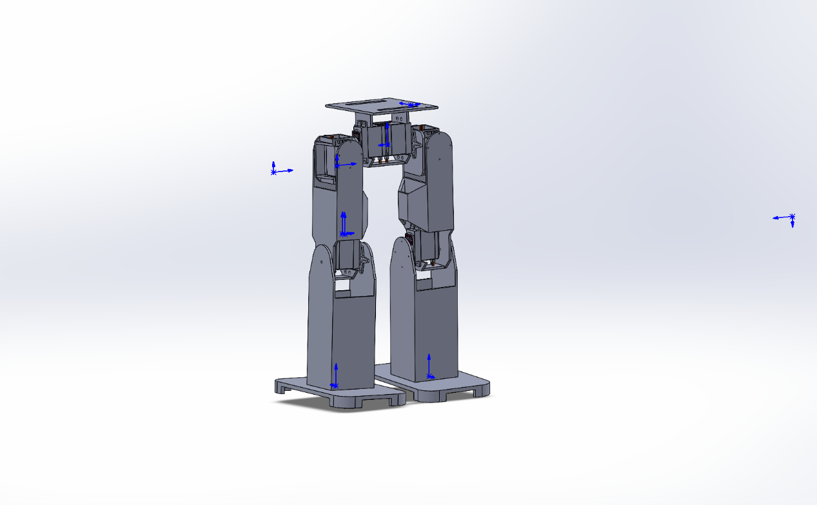
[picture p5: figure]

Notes: 我们的系统架构分为硬件和软件两层，两者紧密协同，缺一不可。
首先，左侧的硬件层构成了机器人的物理基础。我们以 Arduino 作为“大脑”，负责数据处理和逻辑运算。执行端，4个伺服电机精准驱动腿部，确保了步态的稳定。在感知方面，摄像头和超声波传感器分别提供了视觉和听觉能力，配合稳定的电源模块，为机器人的运转提供了坚实基础。
右侧的软件层赋予了机器人“灵魂”。感知算法基于 TensorFlow Lite 实现视觉识别，同时处理超声波数据以规避障碍物。控制算法中的步态生成器计算出精确的动作序列，双模控制器则保证了自动与手动模式的灵活切换。最上层的应用层通过手机App实现人机交互，让我们能便捷地操控机器人。
正是这种软硬件深度融合的架构，确保了机器人高效、稳定且灵活地运行。

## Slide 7

Project Challenges & Solutions

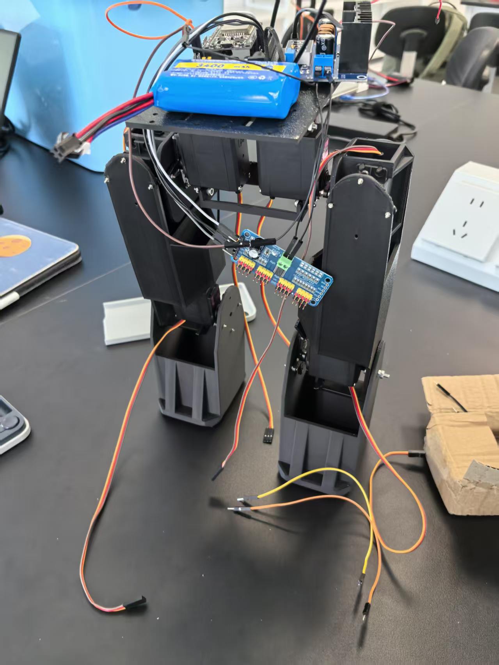
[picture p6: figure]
550ea7f35a3e91ffbf6504a6604df3ca
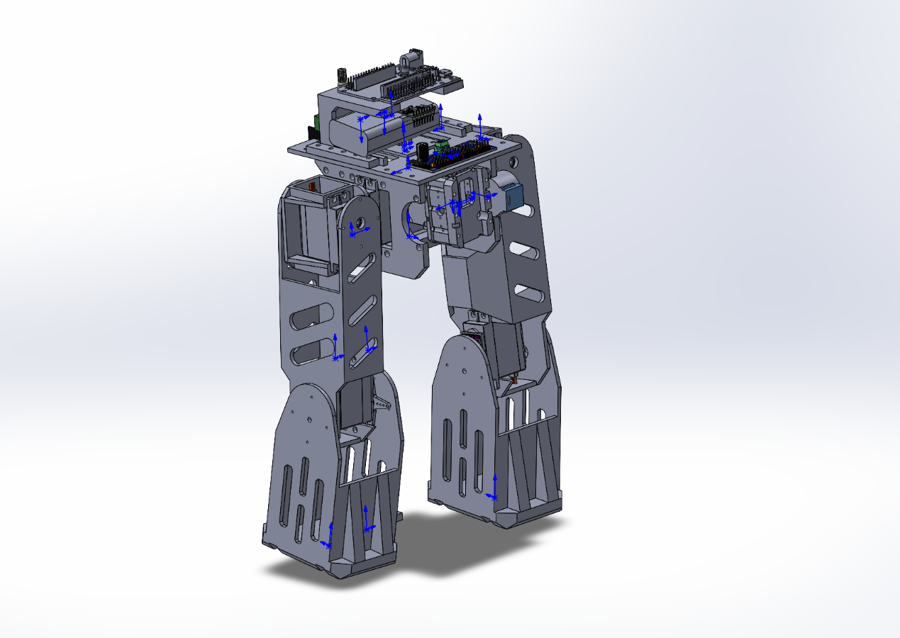
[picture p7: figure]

Generation 2
Tried another foot structure, hardware installation completed

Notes: 我们的系统架构分为硬件和软件两层，两者紧密协同，缺一不可。
首先，左侧的硬件层构成了机器人的物理基础。我们以 Arduino 作为“大脑”，负责数据处理和逻辑运算。执行端，4个伺服电机精准驱动腿部，确保了步态的稳定。在感知方面，摄像头和超声波传感器分别提供了视觉和听觉能力，配合稳定的电源模块，为机器人的运转提供了坚实基础。
右侧的软件层赋予了机器人“灵魂”。感知算法基于 TensorFlow Lite 实现视觉识别，同时处理超声波数据以规避障碍物。控制算法中的步态生成器计算出精确的动作序列，双模控制器则保证了自动与手动模式的灵活切换。最上层的应用层通过手机App实现人机交互，让我们能便捷地操控机器人。
正是这种软硬件深度融合的架构，确保了机器人高效、稳定且灵活地运行。

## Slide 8

Project Challenges & Solutions

Generation 3
The leg structure has been greatly modified, inspired by Qmini，however, it was found that the pitch motor is extremely prone to under-damped vibration when returning to alignment.

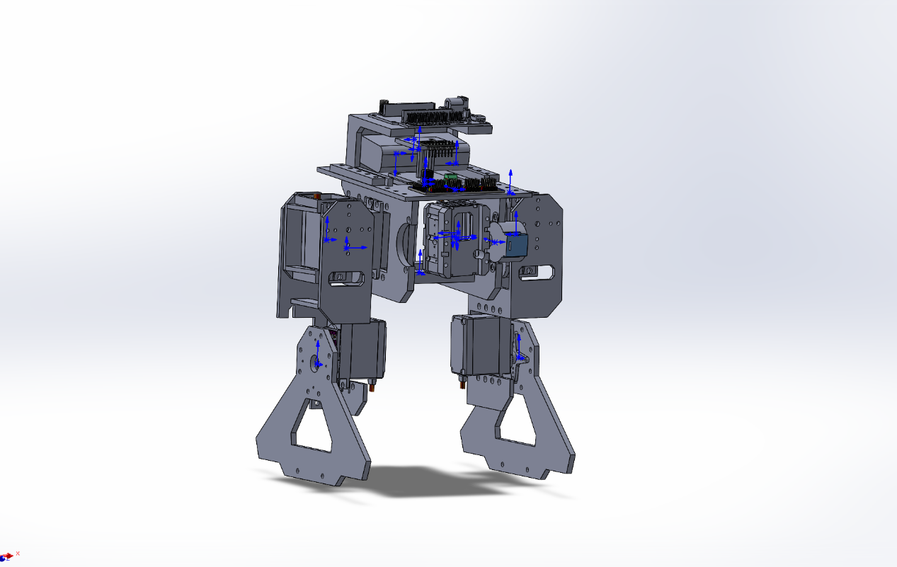
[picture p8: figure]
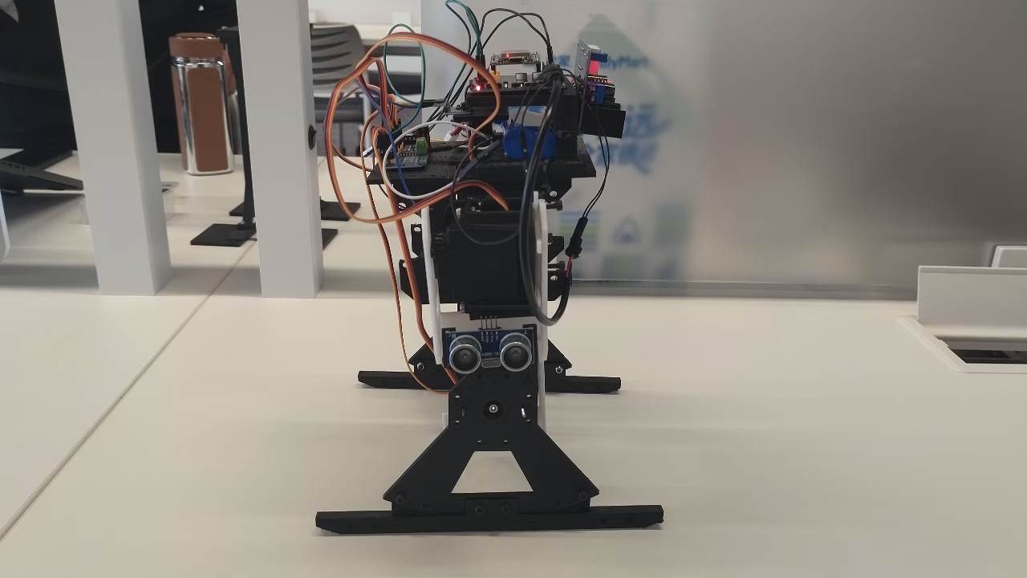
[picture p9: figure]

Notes: 我们的系统架构分为硬件和软件两层，两者紧密协同，缺一不可。
首先，左侧的硬件层构成了机器人的物理基础。我们以 Arduino 作为“大脑”，负责数据处理和逻辑运算。执行端，4个伺服电机精准驱动腿部，确保了步态的稳定。在感知方面，摄像头和超声波传感器分别提供了视觉和听觉能力，配合稳定的电源模块，为机器人的运转提供了坚实基础。
右侧的软件层赋予了机器人“灵魂”。感知算法基于 TensorFlow Lite 实现视觉识别，同时处理超声波数据以规避障碍物。控制算法中的步态生成器计算出精确的动作序列，双模控制器则保证了自动与手动模式的灵活切换。最上层的应用层通过手机App实现人机交互，让我们能便捷地操控机器人。
正是这种软硬件深度融合的架构，确保了机器人高效、稳定且灵活地运行。

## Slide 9

Project Challenges & Solutions

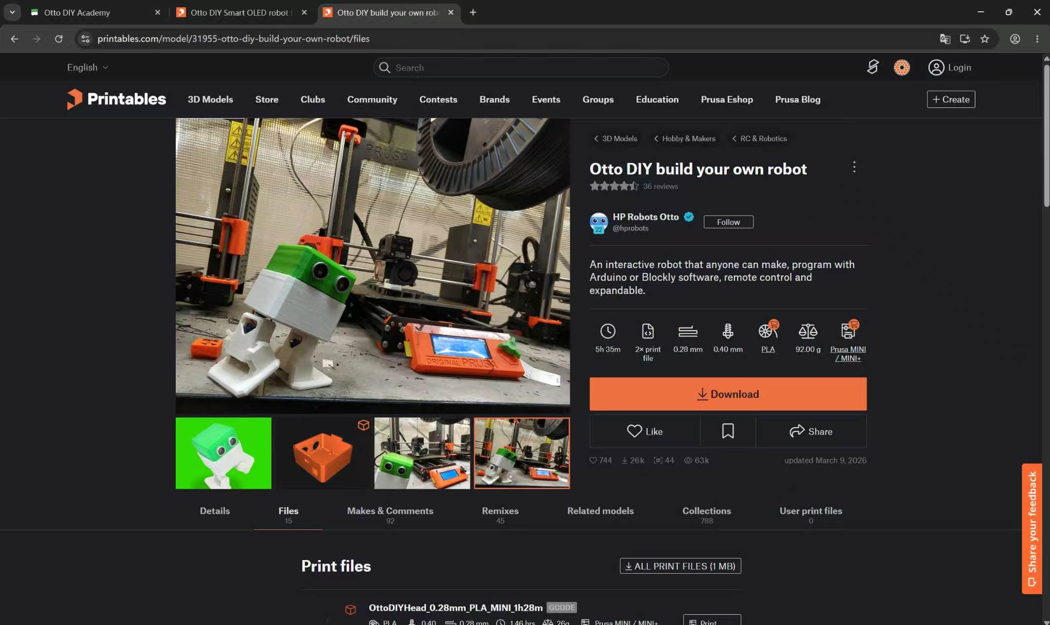
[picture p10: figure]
0144348c3e695e9d772e17d9d5cf1733

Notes: 第二个技术突破在于视觉模型的训练。我们深知高质量数据的重要性，因此采集了超过1800张图片，并通过数据增强技术扩充了数据集。我们选择了轻量级的MobileNet-SSD模型，并经过反复训练，最终实现了超过98%的识别准确率，成功地将“火眼金睛”赋予了机器人。

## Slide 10

Project Challenges & Solutions

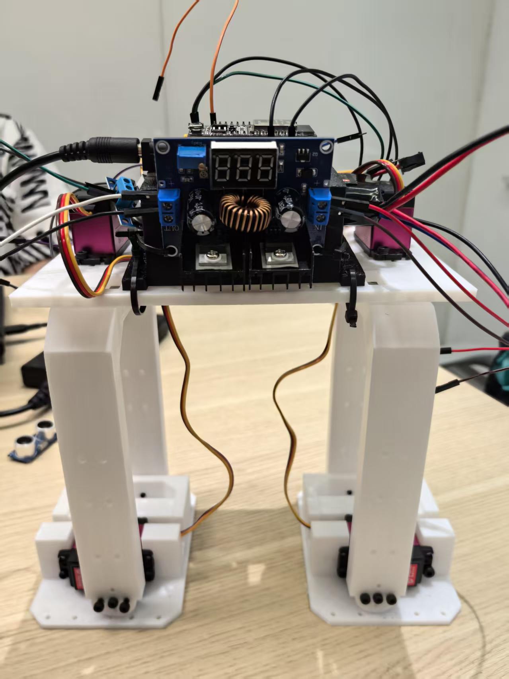
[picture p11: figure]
b879d2f0859811f674e905281e9e8c00
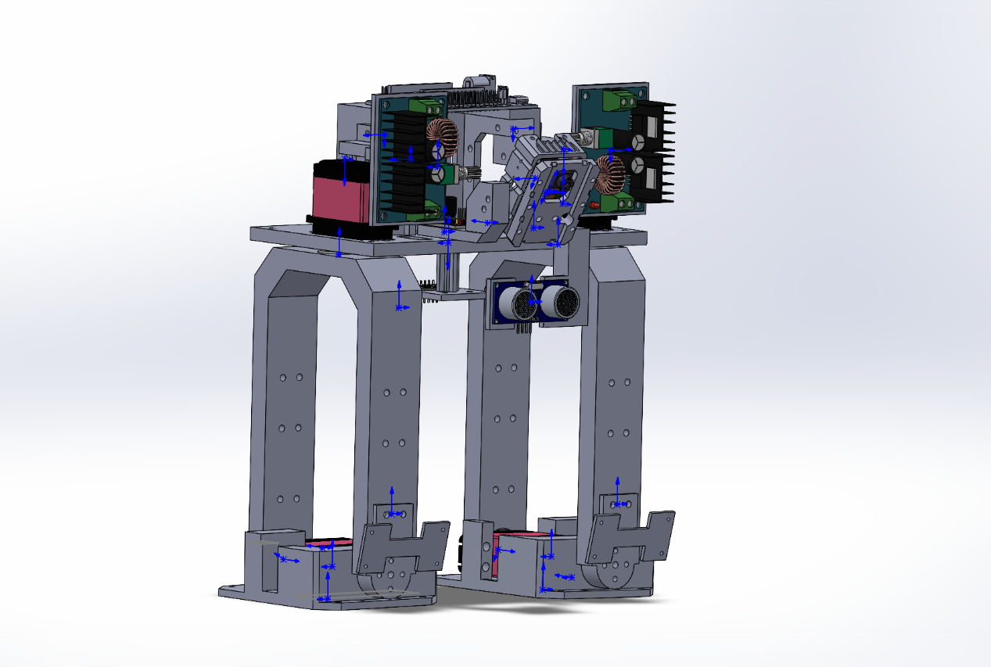
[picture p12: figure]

Generation 4
The legs abandon the humanoid structure and are simplified to four degrees of freedom. The platform can still inherit the hardware installation structure.

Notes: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

## Web Remote Control System

- 02

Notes: 1.7.2013

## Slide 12

Autonomous Walking & Obstacle Avoidance

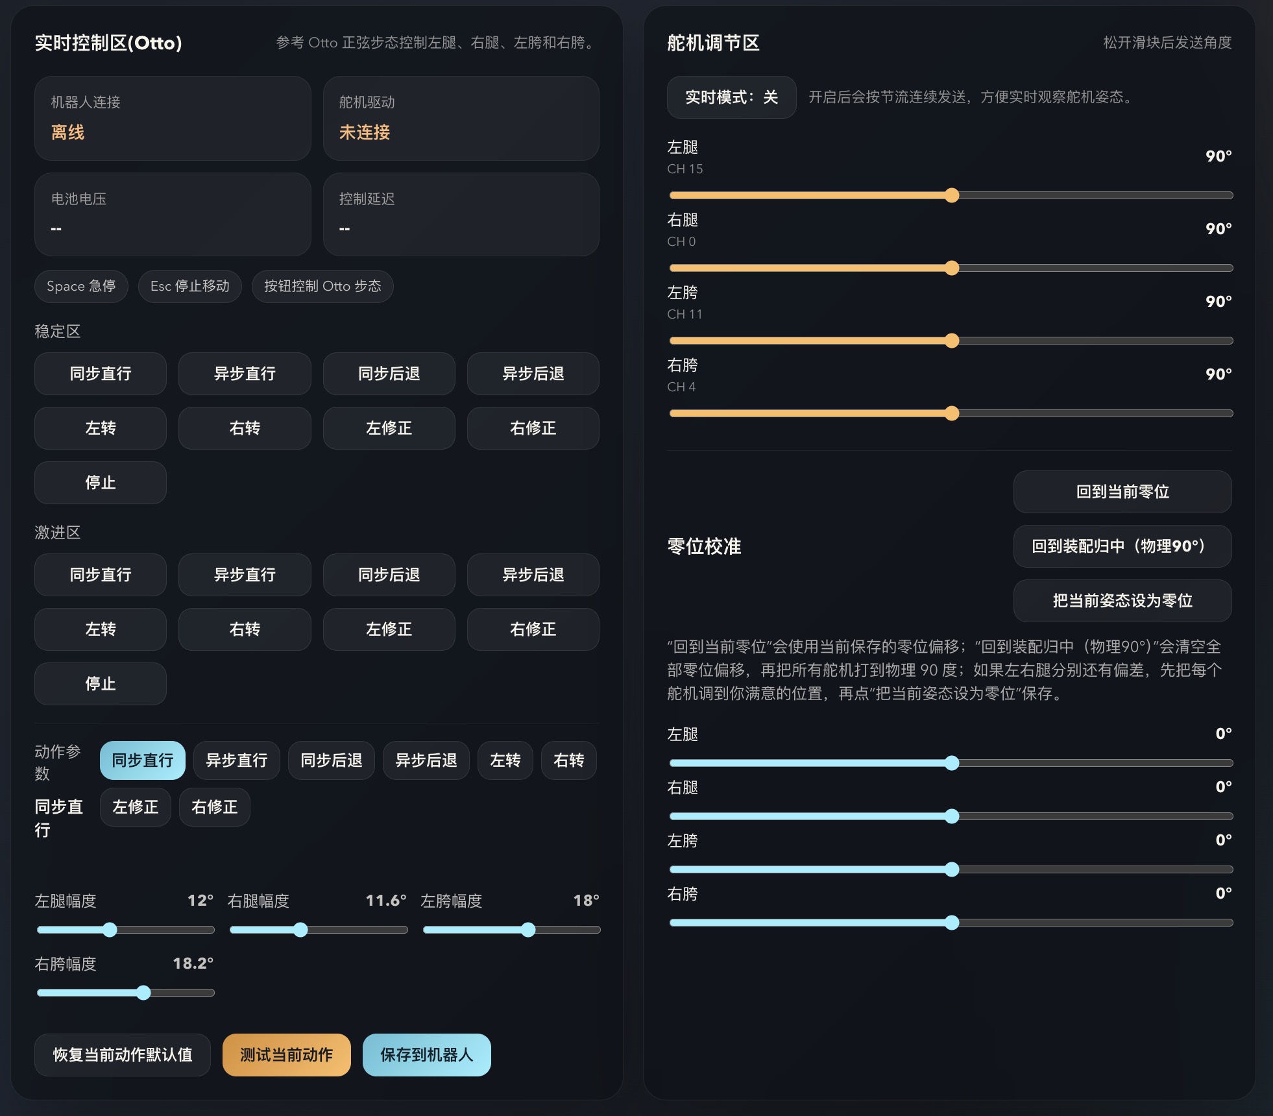
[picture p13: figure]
698fbc288970659a949edf903b6e7a56

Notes: 第二个核心功能是双模控制。机器人既可以自主运行，也可以在遇到困难时由用户通过手机远程接管。这种设计极大地提升了系统的可靠性和灵活性，不仅能避免意外，还方便了我们在开发过程中的调试工作。

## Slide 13

Autonomous Walking & Obstacle Avoidance

use website to control the robot

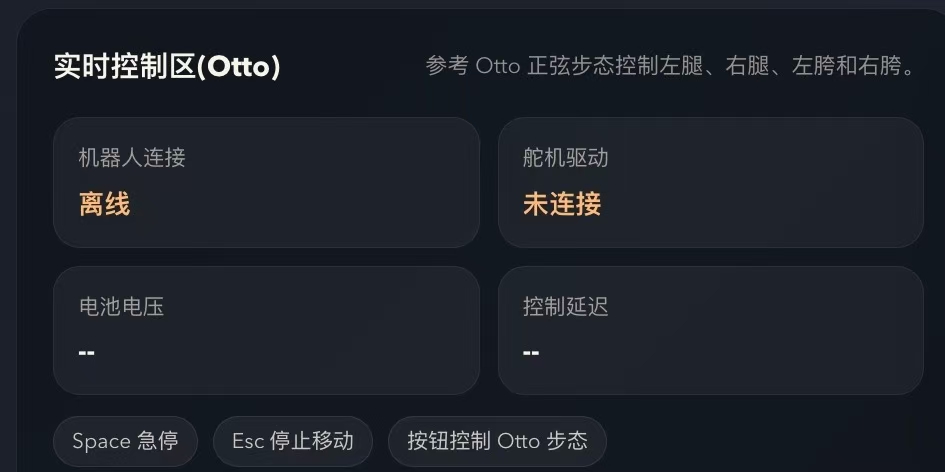
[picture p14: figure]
8b53f327e6af04effd5a21ea2546ab39

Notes: 第二个核心功能是双模控制。机器人既可以自主运行，也可以在遇到困难时由用户通过手机远程接管。这种设计极大地提升了系统的可靠性和灵活性，不仅能避免意外，还方便了我们在开发过程中的调试工作。

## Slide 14

Autonomous Walking & Obstacle Avoidance

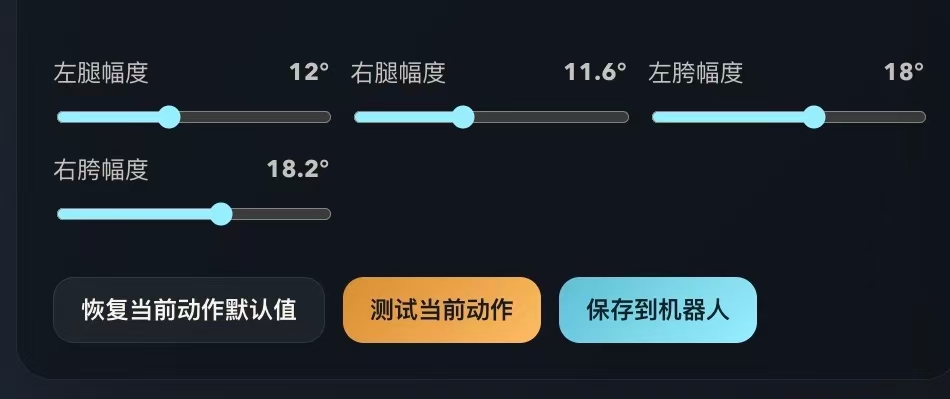
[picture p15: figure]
a09b00c4ca344847cb4b4bd66eb5b297

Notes: 第二个核心功能是双模控制。机器人既可以自主运行，也可以在遇到困难时由用户通过手机远程接管。这种设计极大地提升了系统的可靠性和灵活性，不仅能避免意外，还方便了我们在开发过程中的调试工作。

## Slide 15

Autonomous Walking & Obstacle Avoidance

Tur n

Go straight ahead

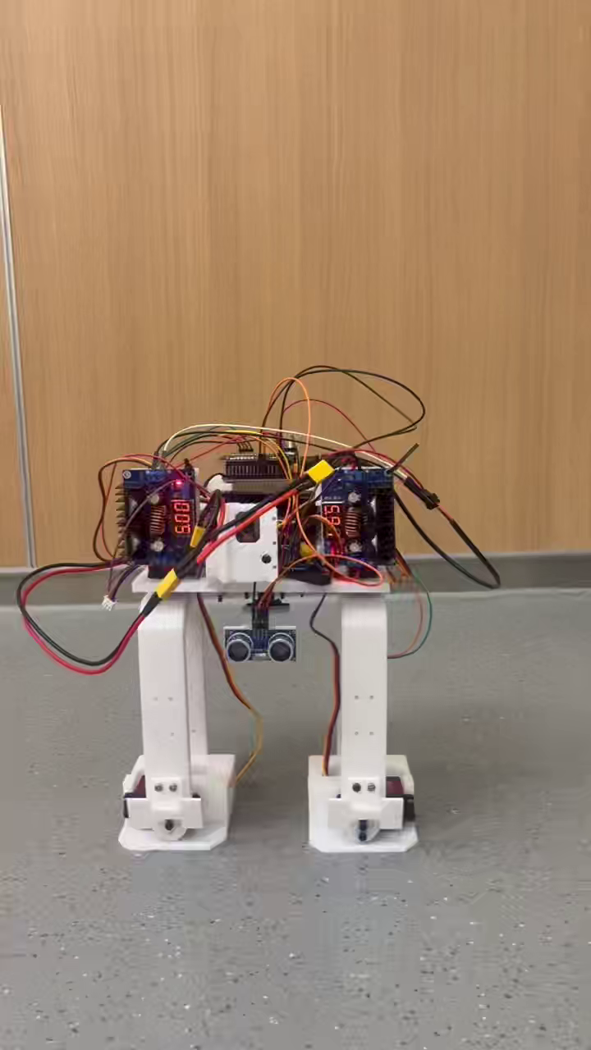
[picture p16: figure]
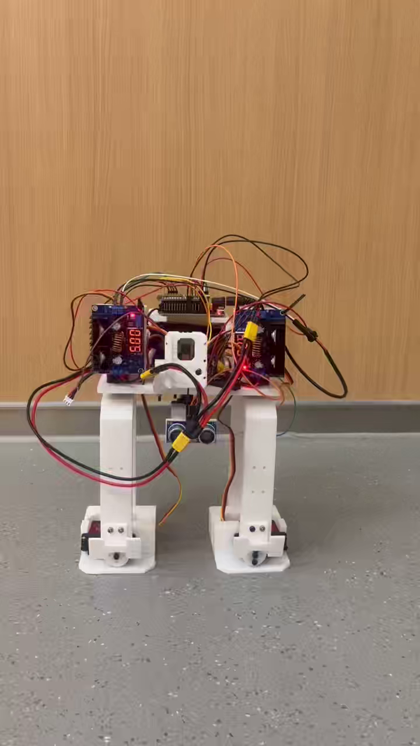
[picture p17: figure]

Control movement by using buttons

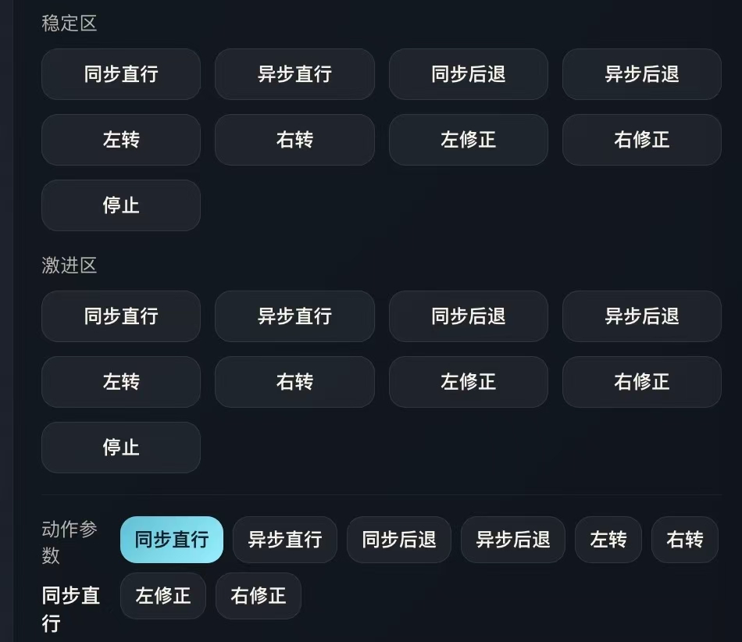
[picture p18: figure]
7cdccf4979a564fff70f15920493f0c2

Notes: 第二个核心功能是双模控制。机器人既可以自主运行，也可以在遇到困难时由用户通过手机远程接管。这种设计极大地提升了系统的可靠性和灵活性，不仅能避免意外，还方便了我们在开发过程中的调试工作。

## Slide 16

Autonomous Walking & Obstacle Avoidance

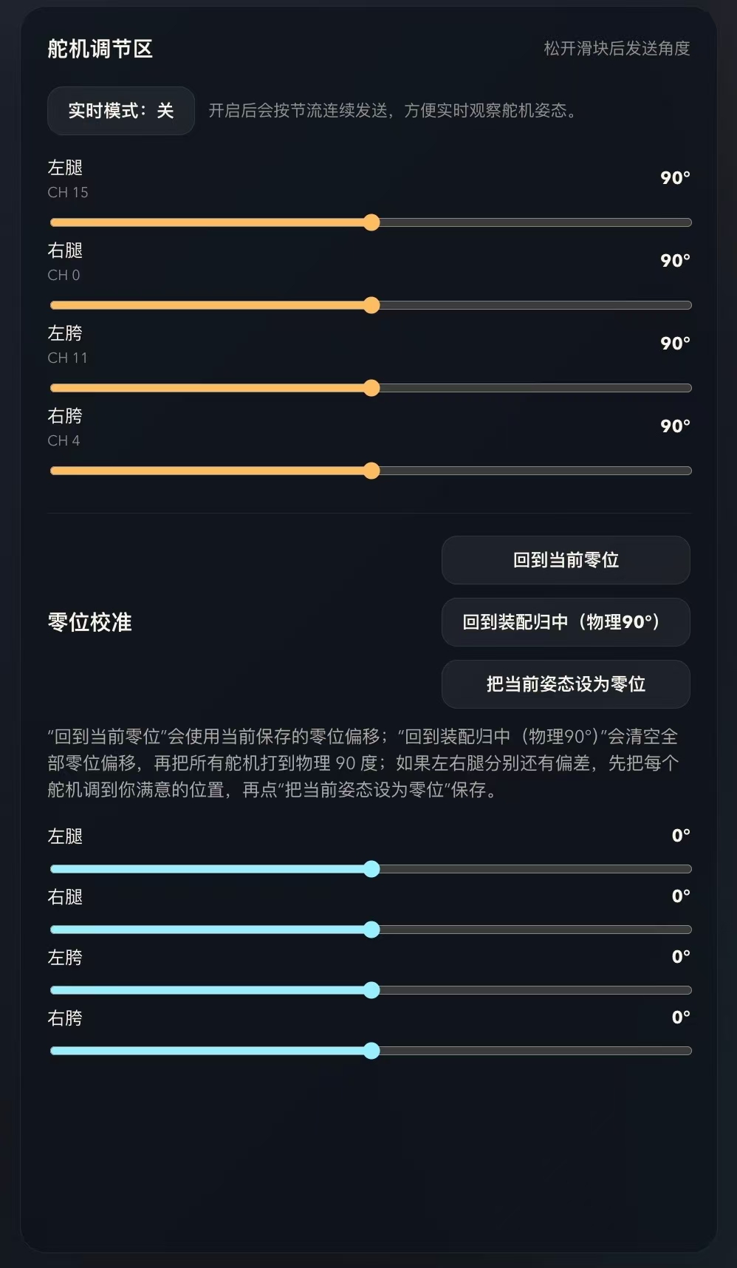
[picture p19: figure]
78983d82a73fa085f3e059a50fb53e65

use website to control the robot

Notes: 第二个核心功能是双模控制。机器人既可以自主运行，也可以在遇到困难时由用户通过手机远程接管。这种设计极大地提升了系统的可靠性和灵活性，不仅能避免意外，还方便了我们在开发过程中的调试工作。

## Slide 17

Project Challenges & Solutions

Unstable ESP32-CAM Connection
Insufficient power, network fluctuations, and excessive request frequency caused frequent camera feed freezes, timeouts, and disconnections.
So we used a portable router to enhance the signal strength.

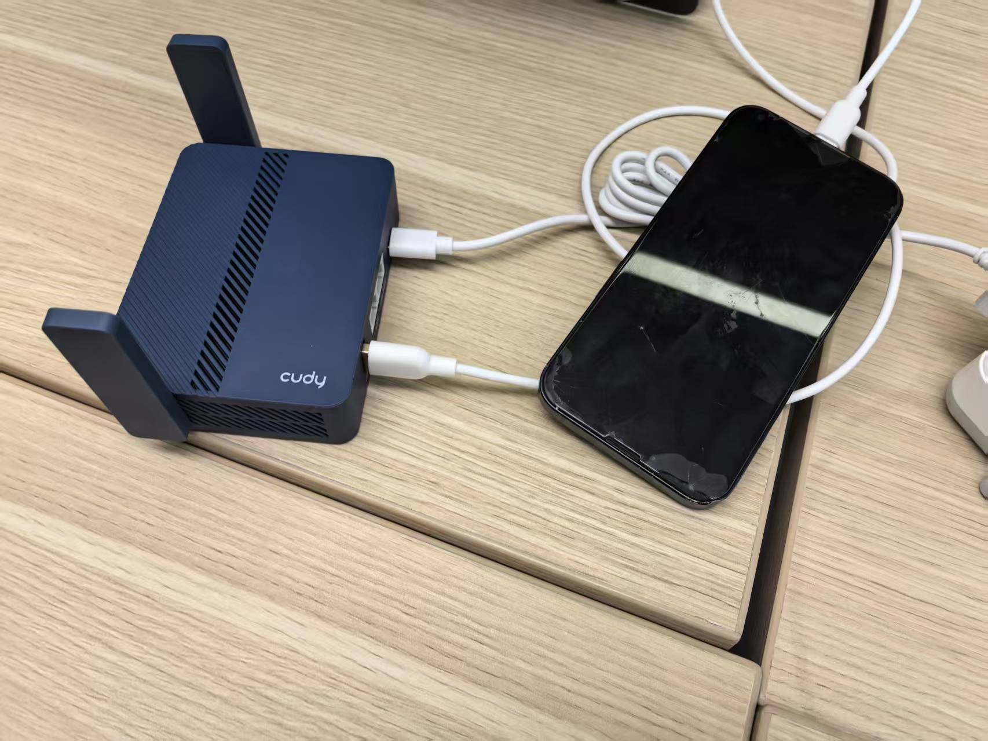
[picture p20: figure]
7a5bab4ee302b74c1fcac1da014a99fd

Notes: 第二个技术突破在于视觉模型的训练。我们深知高质量数据的重要性，因此采集了超过1800张图片，并通过数据增强技术扩充了数据集。我们选择了轻量级的MobileNet-SSD模型，并经过反复训练，最终实现了超过98%的识别准确率，成功地将“火眼金睛”赋予了机器人。

## Visual Recognition

- 03

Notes: 1.7.2013

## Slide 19

Project Challenges & Solutions

Camera: ESP32 CAM
Dataset: 1800 images (multi‑angle, sufficient samples)
Training: Improved model accuracy and stability
Function: Identify objects and trigger corresponding robot actions
Feature: High success rate, stable real‑time performance

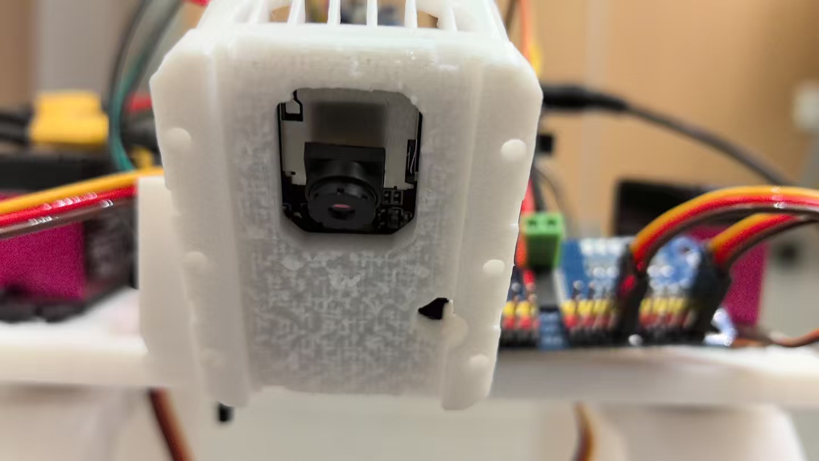
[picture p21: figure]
c0df649283a23668fb2e035edb896d8d

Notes: 我们的第一个核心功能是智能视觉识别。通过摄像头，机器人能够“看懂”世界。它可以识别特定的物块，并根据识别结果做出相应的动作。这个过程包括图像采集、目标检测和决策执行三个步骤。这项技术在工业分拣、家庭服务和教育等领域都有广泛的应用前景。

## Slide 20

Project Challenges & Solutions

Insufficient Visual Recognition Accuracy
Early training with a small dataset and limited angles led to model confusion with similar objects and a low recognition success rate.
Later, we used more photos for training.

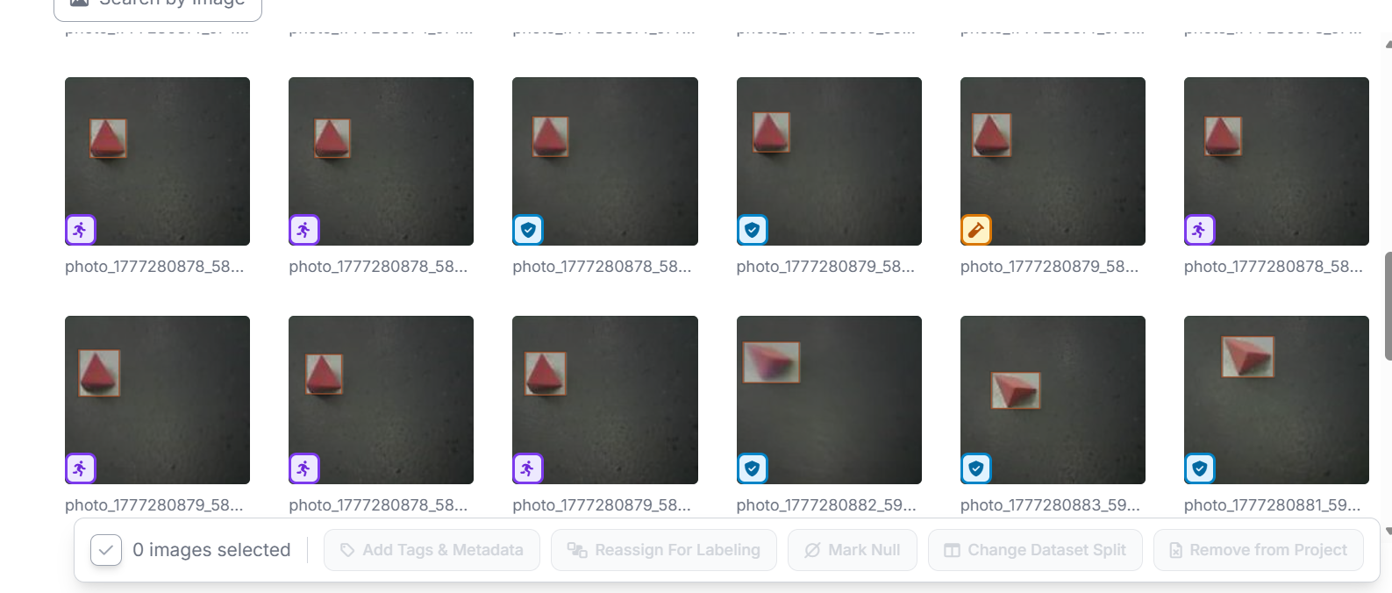
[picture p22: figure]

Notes: 第二个技术突破在于视觉模型的训练。我们深知高质量数据的重要性，因此采集了超过1800张图片，并通过数据增强技术扩充了数据集。我们选择了轻量级的MobileNet-SSD模型，并经过反复训练，最终实现了超过98%的识别准确率，成功地将“火眼金睛”赋予了机器人。

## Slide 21

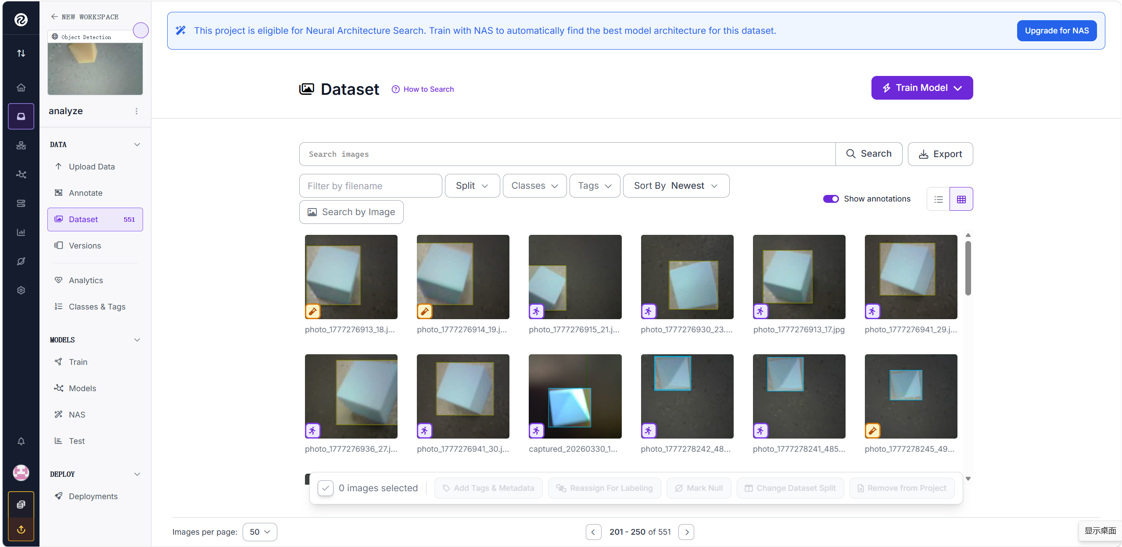
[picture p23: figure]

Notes: 第二个技术突破在于视觉模型的训练。我们深知高质量数据的重要性，因此采集了超过1800张图片，并通过数据增强技术扩充了数据集。我们选择了轻量级的MobileNet-SSD模型，并经过反复训练，最终实现了超过98%的识别准确率，成功地将“火眼金睛”赋予了机器人。

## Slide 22

What We Learned from Building the Biped Robot

Design must match hardware limitations
The first-gen long-leg, high-DOF design failed due to insufficient torque of medium servos. We learned to design for hardware limits and adopted the simple Otto structure for stable motion.
Mechanical optimization directly affects stability
Shortening legs, reducing DOF and optimizing feet greatly improved stability. We realized reasonable simplification beats unnecessary complexity.
Debugging skills and systematic problem-solving
Solving servo jitter, camera disconnection and falling issues, we mastered troubleshooting, modular testing and iteration, enhancing practical skills.

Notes: 第三个技术突破是精准的步态控制。我们通过逆运动学求解和PID闭环控制，为机器人规划了优雅而稳健的步伐。无论是前进还是转弯，我们都精确计算了每个电机的角度，确保了动作的准确性和行走的稳定性。这让我们的Otto机器人能够像真正的生物一样，平稳地移动。

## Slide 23

Thank You

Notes: 我的汇报到此结束，感谢各位的聆听。现在是问答环节，欢迎大家提问。

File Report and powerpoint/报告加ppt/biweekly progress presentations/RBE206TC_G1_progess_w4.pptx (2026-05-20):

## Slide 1

Biped Robot Project - Weekly Progress Report

Team Update - Week 3

Presented

Date: March 2026

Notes: Hello everyone, welcome to our weekly progress report for the Biped Robot project. Today, I'll walk you through what we accomplished this week, the challenges we faced, and our plan for next steps.

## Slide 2

CONTENTS

1.What We Got Done This Week

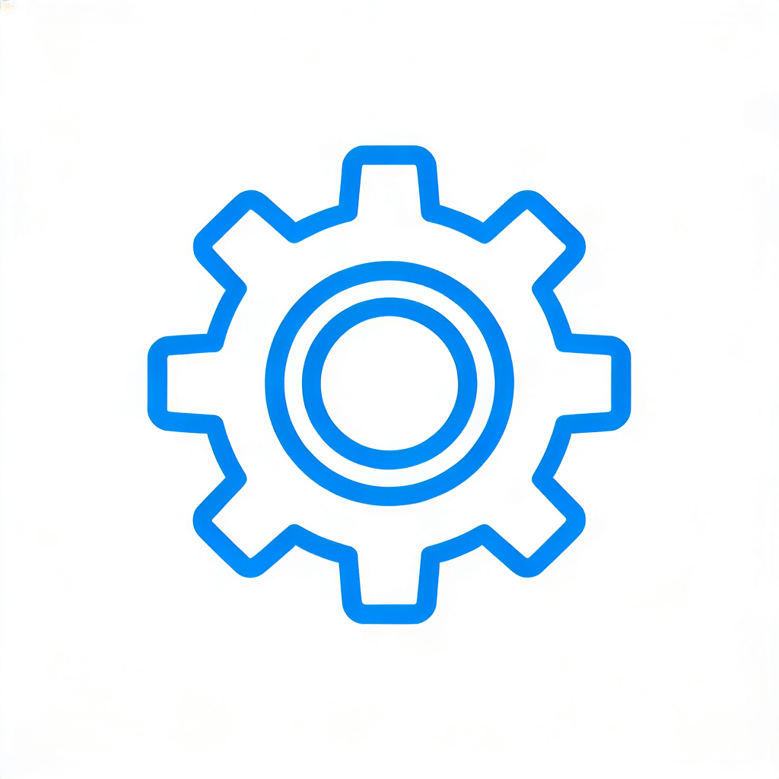
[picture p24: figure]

2.Challenges We Hit

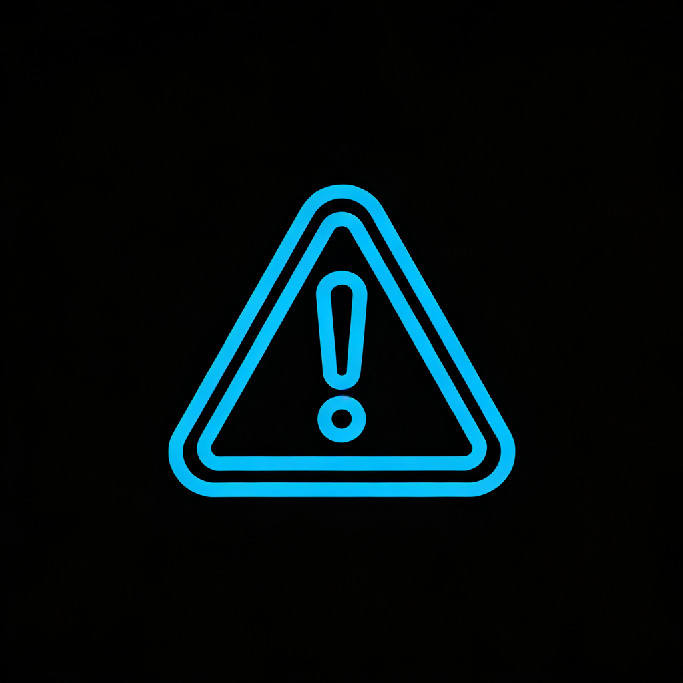
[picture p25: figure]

3.Our Plan for Next Week


4.Q&A / Open Discussion


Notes: Here's a quick overview of what we'll cover today: first, what we managed to accomplish this week, then the challenges we ran into, followed by our plan for next week, and finally, we'll open it up for questions.

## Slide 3

What We Got Done This Week

Got all the motors wired up and working!

We successfully connected all the robot's motors and checked that they power up correctly.

c32a773cd9204afed7b7b8ad66ef5f8e

Figured out all the pin connections

We mapped out and secured all the control and power pins, which is crucial for writing the control code later.

Next plan: Based on the confirmed pin definitions, start the development and integration testing of the underlying driver.

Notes: This week, we focused on the electrical side of things. We got all the motors connected and confirmed they work. We also finalized where all the wires and pins need to go, which sets us up nicely for programming the robot's movements.

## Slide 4

。

Challenges We Hit


3D printed parts didn't fit the motors

When we tried to fit the motors into the 3D printed parts, we realized the holes were too small—we didn't account for the motor's size tolerance in the design.

Had to pause assembly

This meant we had to stop putting the robot together. We need to redesign and reprint those parts.

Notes: On the mechanical side, we hit a snag. The 3D printed parts we made didn't fit the motors properly because we didn't leave enough space in the design. So, we had to stop assembling the robot and go back to the drawing board for those parts.

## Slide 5

Redesign the 3D printed parts to fit the motors:Modify the design to add more tolerance for the motors, ensuring they fit smoothly.

Print the new parts:Print the mechanical parts according to the revised design.

Put the robot back together with the new parts:Once the new parts are printed, immediately install the motors and reassemble the structure.

Start testing the motors and try out some basic movements:After assembly, test the motor drivers and attempt simple gait debugging.

Our Plan for Next Week

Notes: So, here's our plan to fix this: first, we'll redesign the 3D parts to make sure the motors fit. Then we'll print the new parts, put the robot together again, and start testing the motors to get it moving.

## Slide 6

Project Update Summary

Electrical system is good to go!

The electrical part is all set—motors are wired, pins are mapped.

008f22c9e985ccdd9738359d22340350

Mechanical assembly is on hold

We're stuck on the mechanical assembly because of the 3D print issue, but we know how to fix it.

Overall, we're on track

We hit a small roadblock, but the project is still on schedule. We're confident we can fix this and keep moving forward next week.

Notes: To sum up: the electrical system is done and working well. The only hold-up is the mechanical part, which we know how to fix. Overall, we're still on track, and we're looking forward to getting the robot assembled and moving next week.

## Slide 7

Thank You

Thanks for listening!

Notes: Thanks again for your time and attention!

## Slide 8

Q & A

Q&A / Open Discussion

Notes: That's my update for this week. I'll now open it up for any questions you might have.

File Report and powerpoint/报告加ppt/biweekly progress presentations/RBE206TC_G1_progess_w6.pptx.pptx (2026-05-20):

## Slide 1


Bipedal Robot Project Progress Report

Team: Group 1

INTELLIGENT ROBOTICS LAB

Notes: Hello everyone, welcome to the progress report of our Biped Robot project. I am the representative of Group 1, and today I will present our latest progress, design updates, challenges encountered, and the next steps for the project.

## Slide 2


Project Overview

Current Progress

Design Update

Problem Analysis

Solutions & Next Steps

Agenda

01

02

03

04

05

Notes: This presentation will be divided into five parts: first, the project overview; second, our current progress; third, the recent design updates; fourth, problem analysis; and finally, our solutions and next steps.

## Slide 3

Project Overview

The goal of this project is to develop a bipedal robot capable of stable walking and autonomous control. By integrating mechanical structure, electronic control systems, and visual recognition modules, we aim to create a practical robot prototype.


Mechanical

Electronic

Vision

Integrating Mechanics, Electronics, and Software for Next-Gen Robotics

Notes: The core goal of our project is to develop a biped robot that can walk stably like a human and possess a certain degree of autonomous control. This requires in-depth research and integration in mechanical design, electronic control, and software algorithms.

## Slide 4

Current Progress - Hardware Assembly

We have successfully completed the overall mechanical assembly of the robot, including the legs, torso, and head.
The robot structure is now fully assembled and ready for further testing.


Basically
Assembled
Robot

Status: Mechanical Structure Complete | Next Step: System Integration & Testing

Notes: Regarding our current progress, we have successfully completed the mechanical assembly of the robot. As you can see from the picture, the entire structure, including the legs, torso, and head, is fully assembled and ready for the next phase of testing.

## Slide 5

Current Progress - Servo Driving

We have successfully established communication and driven all the servos. Basic movement commands are being executed as expected.

Servos reset immediately after rotation. They perform the action but fail to maintain the target angle, reverting to initial positions.

Next Step:Investigate power supply stability and motor driver configuration to resolve the position holding failure.

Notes: We have also successfully connected and driven all the servos. However, we encountered a critical issue during testing: when we send a command for the servo to rotate to a certain angle, it immediately returns to the initial position after completing the action, which prevents the robot from maintaining a stable posture.

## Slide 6

Design Update - Upper Body Remodeling

The robot's upper body has been fully remodeled with optimized structural design, focusing on enhancing integration efficiency and physical balance.

Dedicated ESP32 Mounting- Optimized position for the main control board ensuring secure connections.


Camera Integration- Fixed bracket for precise visual perception alignment.

Battery Compartment- Reinforced design improves weight distribution and balance.

Engineering Design Phase | v2.0

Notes: In terms of design updates, we have remodeled the upper body of the robot. The new design, as shown in the CAD model, includes dedicated and optimized mounting positions for the ESP32 board, camera, and battery. This will not only improve the robot's balance but also make the integration of electronic components more efficient.

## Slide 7


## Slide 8


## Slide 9


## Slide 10

Servo Reset Analysis

Core Problem
Servos reset to initial position after executing a command, failing to maintain the target angle.

Software Logic
Logical errors in the control code leading to unexpected resets.

Hardware Connection
Potential loose wiring or faulty connections causing signal loss.

Power Supply
Unstable voltage causing insufficient torque to hold position.

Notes: We are currently analyzing the servo reset issue. The core problem is that the servos cannot maintain their target angle after moving.
We suspect the causes might be related to logical errors in the control code, potential hardware connection issues, or an unstable power supply that fails to provide sufficient torque for the servos to hold position.

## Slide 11

Solutions & Next Steps

Solutions

- Debug the control code to ensure angle maintenance.
- Inspect and secure all hardware connections.
- Test and optimize the power supply.

Next Steps

- Complete the troubleshooting of the servo reset issue this week.
- Print and assemble the newly designed upper body parts.
- Conduct walking tests after assembly.

Focus on resolving current issues and advancing to physical testing phase.

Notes: To address the servo reset problem, we plan to debug the control code, inspect all hardware connections, and optimize the power supply this week. Additionally, the newly designed upper body parts are currently being printed and will be assembled this week. After assembly, we will conduct walking tests to verify the robot's functionality.

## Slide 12

Thank you

Q&A

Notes: To address the servo reset problem, we plan to debug the control code, inspect all hardware connections, and optimize the power supply this week. Additionally, the newly designed upper body parts are currently being printed and will be assembled this week. After assembly, we will conduct walking tests to verify the robot's functionality.

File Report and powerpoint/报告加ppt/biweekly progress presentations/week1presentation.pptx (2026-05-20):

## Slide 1

Progress Report on the Bipedal Robot Project

Material organization and future plans

Presenter

date：2026/3

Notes: 大家好，欢迎参加本次双足机器人项目的进展报告会。今天，我将向大家汇报我们项目目前的材料整理情况，并详细介绍我们下一阶段的未来工作计划。虽然项目刚刚起步，我们还没有实物成果，但我们已经在理论研究和方案规划上做了充分的准备。

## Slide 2


CONTENTS

01.Project Background and Objectives

02. Review of Preliminary Work

03. Material organization and analysis

04. Future plan

05. Summary and Outlook

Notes: 本次报告将分为五个部分。首先，我会介绍项目的背景和我们设定的核心目标。接着，回顾我们在项目初期已经完成的一些关键工作。然后，重点展示我们目前在机械、电子和软件方面所做的材料整理与分析。之后，将详细阐述我们为未来制定的分阶段工作计划。最后，对整个项目进行总结并展望未来的发展方向。

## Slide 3

Project Background and Objectives - Core Objective

short target：Fundation and walking

Complete the mechanical structure design and hardware setup of a 6-degree-of-freedom biped robot, achieving stable straight-line walking posture, and laying the physical foundation for the project.

long-term aim

Based on the basic platform, conduct in-depth exploration of more complex gait planning algorithms and environmental perception capabilities, achieving obstacle avoidance functions and the ability to identify specific objects.

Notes: 基于此背景，我们设定了清晰的项目目标。短期来看，我们的首要任务是完成一个6自由度双足机器人的设计与制作，并让它能够实现最基本的稳定行走。而从长远来看，我们希望在这个基础平台上，不断探索和优化控制算法，最终实现更智能、更灵活的运动能力。

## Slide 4

Review of Preliminary Work - Scheme Determination

6-degree-of-freedom bipedal structure design

Degree of Freedom Allocation Scheme

Each leg consists of 3 core degrees of freedom: the forward-backward and left-right swinging of the hip joint, as well as the bending of the knee joint. In total, there are 6 degrees of freedom.

Adopting a classic minimalist architecture, while ensuring the basic movement capabilities, significantly reduces the complexity of mechanical design and control algorithms. It is an ideal platform for beginners' research.

advantages

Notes: 在项目的前期，我们完成了关键的方案确定工作。如图所示，我们选择了一个经典的6自由度设计，每条腿有3个关节，分别控制前后、左右和屈膝动作。这个方案是经过充分考虑的，它在功能和复杂度之间取得了很好的平衡，是我们项目起步的理想选择。

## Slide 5

eddff03efb53feefd1fcd4c73b02d89f

plan


design graph

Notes: 在项目的前期，我们完成了关键的方案确定工作。如图所示，我们选择了一个经典的6自由度设计，每条腿有3个关节，分别控制前后、左右和屈膝动作。这个方案是经过充分考虑的，它在功能和复杂度之间取得了很好的平衡，是我们项目起步的理想选择。

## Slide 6

Review of Preliminary Work - Selection of Key Components

Control and Vision Categories
- heart:ESP32 开发板 (ESP32 DevKit V1)
- modue:ESP32-CAM (with OV2640 camera)
Sensor and Drive Components
- Posture balance sensor:GY-521 MPU6050 model
- Multi-channel Servo Driver Board:PCA9685 (16path 12-bit)

Power joints (muscles)
- Medium-sized main steering gear (6 units):MG996R (180)，size：wide 20mm x long 40.5mm
- Miniature auxiliary servo motors (4 units):MG90S (180)，size：long 32mm * wide 23mm * tall 12.1mm
Energy and Power Supply Category
- High-power voltage reduction module:LM2596S (with number screen)，size：39 * 66mm
- Main power supply lithium battery pack:LB218B (7.4V)，size：long 69mm * wide 37mm * tall 18.8mm

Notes: 另一个重要的前期工作是核心部件的选型。我们深入对比了舵机和步进电机的优缺点，最终选择了舵机。原因很简单：舵机自带角度反馈和闭环控制，我们只需要发送一个信号，它就能精确地转到指定角度，这对于控制机器人关节来说是完美的选择。我们初步选定了MG90S这款舵机，它体积小、扭矩适中，完全能满足我们的需求。

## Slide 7

Future Work Plan - Phase 1: Mechanical Modeling

step aim

Complete the 3D model design and engineering drawing output of the robot, ensuring the rationality of the structure.

Specific task breakdown

use SolidWorks

Create 3D models of each component of the robot (such as the lower legs)

Carry out virtual assembly, check the interference between components and optimize the design.

Output engineering drawings (2D views) for processing purposes

time

plan：2weeks (Week 1 - Week 2)


3D model


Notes: 基于目前的准备工作，我们制定了详细的未来计划。第一阶段，我们将集中精力进行机械建模。在接下来的两周内，我们的目标是完成整个机器人的3D设计，并输出可以用于实际加工的工程图纸。

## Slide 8

Future Work Plan - Phase 1: Task Decomposition

1 week

Software Foundation Learning
Be familiar with the interface and core operation logic of the modeling software, and master the basic commands.

Component 3D modeling
Based on the design drawings, independently complete the 3D model drawing of all key components.

2 week

Virtual assembly and interference check
Assemble the components, check for spatial interference, and ensure the structural rationality.

Model modification and optimization
Iterate the design based on the inspection results to enhance the model's accuracy and performance.


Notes: 这是第一阶段任务的详细分解和时间线。我们将用一周时间学习软件并完成建模，第二周进行装配、检查和图纸输出。通过这样的规划，我们希望能高效、有序地完成第一阶段的目标。

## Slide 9

Future Work Plan - Phase Two: Hardware Setup

aim

Complete the hardware assembly of the robot, ensuring that the structure is stable and the circuit connections are normal.


task

- Process the mechanical components required according to the engineering drawings
- Assemble the mechanical structure of the robot, install the servo motors and conduct initial debugging
- Carry out hardware integration testing to ensure correct connections and normal communication of all components

time plan

consume：2weeks

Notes: 完成3D建模后，我们将进入第二阶段——硬件搭建。这个阶段，我们会把设计图变成实物，包括采购零件、组装机械结构、焊接电路等。预计两周时间，我们就能看到机器人的雏形了。

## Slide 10

Future Work Plan : Task Decomposition and Timeline

1-3week: fundation

Drive development
Write the servo drive and basic control code, and establish the hardware communication interface.

Prototype of the algorithm
Design and implement the initial gait algorithm to verify its theoretical feasibility.

4-8week：test

Software and hardware integration testing
Resolve the issue of control accuracy and ensure real-time system response.

Functional testing
Test the walking function, record abnormal data, and use it as a basis for optimization.

9-10week：Optimization

Parameter optimization
Optimize the control algorithm based on test data to enhance gait stability.

Stage acceptance
Achieve stable walking and complete the set goals of the third stage.


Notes: 第三阶段的工作将分为三步：首先编写基础的控制代码，然后实现步态算法，最后进行长时间的联调和优化。我们相信，通过这三周的努力，一定能让机器人迈出稳健的第一步。

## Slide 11

Summary and Outlook

Project Summary: Strengthening the Foundation

- Scheme Design: Completed the overall architecture design of the biped robot and selected the key components.
- Theoretical Foundation: Conducted comprehensive data collection and analysis on mechanical structure, electronic control, and software algorithms.
- Current Status: Currently in the preparatory stage, laying a solid foundation for subsequent implementation.

Future Outlook: Intelligent Upgrade

- Perception Enhancement: Integrating ultrasonic and infrared sensors to achieve autonomous obstacle avoidance functionality.
- Motion Optimization: Iterative gait algorithm to pursue a more natural and efficient bipedal walking experience.
- Human-Machine Interaction: Incorporating a visual recognition module to explore the possibilities of human-machine interaction.


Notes: 最后，对本次报告进行总结。目前我们的项目正处于一个良好的开端，完成了充分的前期准备。展望未来，这个基础的双足机器人平台还有很大的扩展空间，我们可以为它增加避障、视觉等功能，让它变得更加智能。我们对项目的未来充满信心。

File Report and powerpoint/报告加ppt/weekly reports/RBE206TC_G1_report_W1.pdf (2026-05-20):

### RBE206TC

Project-based Practice
in Intelligent Robotics
- 1 -

## Technical Progress Report

Project name: | Biped robot
Group member: | Yangnan.yan 2363610 Jiarui.li 2360655 xinhang.li 2363444 Jian.wang 2362488 | Group number: | 4
Start date: | 2026-03-01 | End date: | 2026-03-06
Project manager: | Dr. Ki-Young Song

### 1. Executive Summary

This report provides an update on the technical progress made in the past week for the Biped Robot project. Key developments include the completion of the overall structural scheme design of the biped robot, the determination of key component selection, the establishment of the project implementation timeline, and the preparation work for the subsequent mechanical modeling and hardware setup stages. The project is currently in the foundational preparatory phase, laying a solid physical and theoretical foundation for the realization of stable walking and subsequent intelligent upgrade of the biped robot.

### 2. Objectives & Scope

- Complete the mechanical structure design and hardware setup of a 6-degree-of-freedom biped robot, and achieve a stable straight-line walking posture to lay the physical foundation for the project.
- Based on the basic biped robot platform, conduct in-depth research on complex gait planning algorithms and environmental perception capabilities, and realize obstacle avoidance and specific object recognition functions.
- Establish a complete development and testing process for the biped robot, and optimize the control algorithm and mechanical structure to improve the stability and naturalness of the robot's walking.

### 3. Technical Work Completed

### 3.1 Overall Scheme Design

- Determined the 6-degree-of-freedom bipedal structure design for the robot, with 3 core degrees of freedom for each leg (hip joint forward-backward swing, hip joint left-right swing, knee joint bending), forming a minimalist and practical mechanical architecture.
- Analyzed the advantages of the selected structural scheme: while ensuring basic movement capabilities, it significantly reduces the complexity of mechanical design and control algorithms, which is suitable for the project's research and development orientation.

### 3.2 Key Component Selection & Confirmation

- Completed the screening and determination of all core components of the biped robot, covering control & vision, sensor & drive, power joint, and energy & power supply categories, with clear models and specifications for each component:

- 2 -
- Control and Vision: ESP32 DevKit V1 development board (core control), ESP32-CAM (with OV2640 camera, visual module)
- Sensor and Drive: GY-521 MPU6050 posture balance sensor, PCA9685 16-path 12-bit multi-channel servo driver board
- Power Joints: 6 MG996R medium-sized main steering gears, 4 MG90S miniature auxiliary servo motors
- Energy and Power Supply: LM2596S high-power voltage reduction module (with digital display), LB218B 7.4V lithium battery pack (main power supply)
- Verified the matching degree between each component, ensuring the rationality of component collocation for subsequent hardware assembly and functional realization.

### 3.3 Project Planning & Task Decomposition

- Established a phased implementation plan for the project, dividing the follow-up work into Mechanical Modeling, Hardware Setup, Algorithm Development, Integration Testing, and Optimization Acceptance stages, and clarified the core objectives of each stage.
- Completed the detailed task breakdown and time planning for the key early stages (Mechanical Modeling and Hardware Setup), and formulated a 2-week overall development timeline with clear division of core work for each time period.
- Carried out comprehensive data collection and analysis on the biped robot's mechanical structure, electronic control system, and software algorithms, laying a complete theoretical foundation for subsequent practical development.

### 4. Observations & Findings

### 4.1 Scheme Advantages & Feasibility

- The selected 6-degree-of-freedom minimalist structure has high practicality for the project's initial goal of "stable straight-line walking", and the low design complexity can effectively reduce the difficulty of subsequent mechanical modeling and control algorithm development, with strong implementability.
- The selected key components have the characteristics of high cost performance, mature technology, and easy matching. The specifications of each component (size, power, interface) are compatible, which can ensure the smooth progress of hardware assembly and system debugging.

### 4.2 Project Progress & Preparatory Status

- The project has completed all foundational preparatory work in the first week, including scheme design, component selection, and timeline formulation, and the progress is consistent with the expected plan.
- The theoretical research on mechanical structure and control algorithms has been completed, and the technical route for subsequent mechanical modeling (based on SolidWorks) and hardware development is clear, with no obvious technical conflicts or matching problems found in the early stage.

### 4.3 Stage Goal Clarity

- The phased task decomposition makes the project goals at each stage clear and measurable: the short-term goal of "foundation and walking" and the long-term goal of "intelligent upgrade" are closely

- 3 -

connected, and the work of each stage serves the overall project objectives, forming a complete development logic.

### 5. Challenges & Roadblocks

- Lack of practical experience in 3D mechanical modeling and virtual assembly of biped robots; it is necessary to master the operation of SolidWorks software in a short time to ensure the rationality of component modeling and avoid spatial interference during assembly.
- The initial gait planning algorithm is only in the theoretical design stage; the transformation from theoretical algorithm to actual code and the adaptation with hardware have unknown difficulties, and the real-time response and control accuracy of the system need to be verified.
- The subsequent integration of environmental perception modules (ultrasonic, infrared, visual recognition) with the basic walking platform has potential technical difficulties.
- The coordination between perception and motion control needs to be further explored.

### 6. Next Steps & Recommendations

- Conduct SolidWorks software foundation learning, master the core operation logic and basic commands of the modeling software to meet the needs of robot component modeling.
- Complete the 3D model design of all key components of the robot (such as lower legs, hip joints) based on the determined structural scheme, and carry out virtual assembly of components to check and optimize spatial interference problems.

### 7. Conclusion

- In the first week of the project, significant foundational progress has been made in the biped robot research and development, including the completion of the 6-degree-of-freedom structural scheme design, the determination of all key core components, the formulation of a detailed phased implementation plan and 2-week development timeline, and the completion of comprehensive theoretical research on mechanical structure and control algorithms.
- The project is currently in a good preparatory state, and all early work has laid a solid physical and theoretical foundation for the subsequent mechanical modeling, hardware setup and stable walking realization of the biped robot.

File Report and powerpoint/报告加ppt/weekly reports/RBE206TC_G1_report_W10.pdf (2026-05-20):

## RBE206TC

Project-based Practice
in Intelligent Robotics
- 1 -

## Technical Progress Report

Project name: | Biped robot
Group member: | Yangnan.yan 2363610 Jiarui.li 2360655 xinhang.li 2363444 Jian.wang 2362488 | Group number: | 1
Start date: | 2026-05-04 | End date: | 2026-05-08
Project manager: | Dr. Ki-Young Song

### 1. Executive Summary

This report documents the technical progress of the biped robot project in the current week. The team has completed structural simplification, stability optimization, foot structure improvement, hardware compartment protection enhancement, large-scale vision dataset collection, and model training. The original robot structure required excessive motor torque that could not be met by the existing medium-size motors. To solve this issue, the team reduced the degrees of freedom to two per leg, shortened the leg length, lowered mechanical load, and significantly improved standing and moving stability. In addition, the foot structure was optimized to enhance ground contact and balance capability. The vision dataset was expanded to 1800 images, which greatly improved recognition accuracy and robustness. Initial tests show that the robot achieves much better stability, controllability, and motion feasibility. Remaining issues include minor joint jitter and occasional misidentification at extreme angles. The team will continue targeted optimization to realize stable, continuous, and visually guided walking in the next stage.

2.Objectives & Scope

- Reduce the degrees of freedom to two to lower control complexity and motor load, and improve overall stability.
- Shorten leg length to match the driving capacity of existing medium-size motors.
- Optimize the foot structure to improve ground adaptability, friction, and standing balance.
- Expand the vision dataset to 1800 images and retrain the model for higher recognition success rate.
- Verify motion stability, balance performance, and vision recognition accuracy under the updated structure.
- Identify remaining issues in rigidity, smoothness, and robustness for subsequent improvement.
- Lay a solid foundation for stable walking and integrated vision-motion control.

### 3. Technical Work Completed 3.1 Structural Simplification and Stability Enhancement

- 2 -

The original structure required excessive motor power that exceeded the limit of medium-size motors. The team reduced the degrees of freedom to two, shortened leg length, simplified the actuation mechanism, reduced moment load, and significantly improved mechanical stability and motion feasibility. The adjusted structure was reassembled and verified.

### 3.2 Foot Structure Optimization

Redesigned and optimized the foot structure to increase contact area, improve friction and ground adaptability, enhance support stability, and reduce tipping risk during standing and stepping.

### 3.3 Hardware Protection and Component Reinforcement

Further improved the hardware compartment to reduce exposure of the ESP32, camera, battery, and wires. Key joints and transmission parts were reinforced to improve rigidity and anti-vibration performance.

### 3.4 Large-Scale Dataset Collection and Model Training

Collected and sorted a high-quality vision dataset of 1800 images with rich angles, distances, and lighting conditions. The model was retrained and deployed, which significantly improved recognition success rate and generalization ability.

### 3.5 System Integration and Preliminary Motion Test

Conducted power-on tests and basic walking attempts with the updated structure. Verified stability, balance performance, actuation smoothness, and real-time vision recognition under actual working conditions.

### 4. Observations & Findings

- Reducing degrees of freedom to two effectively lowered motor load, simplified control, and greatly improved standing and moving stability.
- The optimized foot structure significantly improved support balance and ground adaptability.
- Shortened leg length made the actuation system fully compatible with medium-size motors.
- With 1800 training images, the vision system achieved much higher recognition accuracy and robustness.
- Minor jitter exists in individual joints due to residual structural clearance.
- Occasional misidentification still occurs at extreme viewing angles but with much lower frequency.

5.Challenges & Roadblocks
- Although stability is greatly improved, residual joint clearance still causes minor jitter during movement.
- Extreme angles still lead to occasional recognition errors.
- Gait coordination and actuation timing require further fine-tuning for smoother walking.
- The trade-off between low degrees of freedom, motion flexibility, and stability needs continued optimization.

### 6. Next Steps & Recommendations

- Further eliminate joint clearance and strengthen fasteners to reduce jitter and improve rigidity.
- Fine-tune gait parameters and actuation timing to achieve smoother and more coordinated stepping.
- Supplement a small number of extreme-angle samples and fine-tune the model to further reduce errors.
- Fully enclose the hardware compartment for all-round protection.
- Conduct integrated tests of stable walking and real-time vision feedback to verify overall system performance.

### 7. Conclusion

In the current week, the team solved the core problem of excessive motor demand by reducing the degrees of freedom to two and shortening leg length, which significantly improved stability and made motion feasible with existing medium-size motors. The optimized foot structure further enhanced support balance and anti-tipping performance. Meanwhile, the vision model trained with 1800 images achieved greatly improved recognition success rate and stability. The updated mechanical structure and vision system have passed initial verification, and the overall performance has been significantly improved. Remaining issues include minor joint jitter and occasional

- 3 -

misidentification at extreme angles. In the next stage, the team will focus on joint optimization, gait refinement, model fine-tuning, and full protection design, so as to realize stable continuous walking and high-precision visual recognition for the biped robot.

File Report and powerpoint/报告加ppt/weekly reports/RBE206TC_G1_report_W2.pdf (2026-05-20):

### RBE206TC

Project-based Practice
in Intelligent Robotics
- 1 -

## Technical Progress Report

Project name: | Biped robot
Group member: | Yangnan.yan 2363610 Jiarui.li 2360655 xinhang.li 2363444 Jian.wang 2362488 | Group number: | 4
Start date: | 2026-03-07 | End date: | 2026-03-13
Project manager: | Dr. Ki-Young Song

### 1. Executive Summary

This report updates the second-week progress of the Biped Robot project. Based on week 1's preparatory work, key achievements include confirming the motor layout of the 6-DOF biped robot, formulating the differential speed turning method, and finishing preliminary 3D modeling of mechanical components. The project encountered design and 3D printing modeling problems, and is now in the mechanical design and modeling optimization phase, laying a structural foundation for subsequent part printing and assembly.

### 2. Objectives & Scope

- Confirm the rational motor layout of the 6-DOF biped robot, matching motor functions with straight walking and steering requirements.
- Formulate a feasible differential speed turning method, and complete preliminary 3D modeling combined with motor layout.
- Sort out problems in design and modeling, and put forward preliminary solutions to lay a foundation for part printing and assembly.

### 3. Technical Work Completed

### 3.1 Motor Layout Confirmation

- Determined the 6-DOF robot's motor layout: 2 motors for steering control, 4 for straight walking control, the latter arranged at the thigh and knee joints of both legs.
- Optimized motor installation positions, verified compatibility with selected MG996R/MG90S servos, and ensured no structural interference between motor layout and mechanical structure.

### 3.2 Formulation of Turning Method

- Confirmed differential speed turning as the core method, realizing turning by controlling the step length difference of left and right legs.
- Clarified the motor control division during turning, completed theoretical verification of the method, and confirmed its feasibility for the 6-DOF structure.

### 3.3 Preliminary 3D Modeling

- 2 -
- Completed preliminary 3D modeling of key mechanical components (thigh frame, motor fixing bracket, etc.) via SolidWorks based on motor layout and turning method.
- Carried out preliminary virtual assembly, and marked key size parameters of components in the model for subsequent optimization.

### 3.4 Problem Sorting

- Collected and sorted out project problems, divided them into design problems and 3D printing modeling problems, and put forward preliminary solution ideas and optimization directions.

### 4. Observations & Findings

- The motor layout (2 for steering, 4 for straight walking) is highly matched with the 6-DOF structure, with clear functional division and reasonable space layout. The differential speed turning method is simple and feasible, and highly compatible with the current mechanical structure.
- The project progress is consistent with the 2-week timeline, the preliminary 3D model basically matches the movement requirements, and key parameters are clear.
- The encountered problems have clear types and targeted solution ideas, which can be solved through local optimization of the design scheme and model adjustment.

### 5. Challenges & Roadblocks

- Design problems: Unreasonable structural design at the motor-mechanical connection part may reduce installation stability; imperfect leg joint design may affect the coordination of straight walking and turning.
- 3D printing modeling problems: Imprecise partial size parameters of the model may cause part mismatch with motors; the model does not fully consider printing process requirements, which may lead to printing defects.
- The transformation of differential speed turning control logic into actual motor drive code has unknown difficulties and needs further verification.

### 6. Next Steps & Recommendations

- Optimize the 3D model according to existing problems, adjust inaccurate size parameters, and modify unreasonable structural designs to meet printing and installation requirements.
- Confirm the final model and output formal 3D printing files with clear parameters.
- Carry out 3D printing of all mechanical parts and check the quality and dimensional accuracy of printed parts.
- Conduct the overall assembly of the biped robot, including motor installation, mechanical component connection, and preliminary debugging of part positions.
- Prepare assembly tools and materials in advance, and sort out the assembly sequence to improve efficiency and accuracy.

- 3 -

### 7. Conclusion

- In the second week, the project made important structural design progress on the basis of week 1's work: confirmed the motor layout of the 6-DOF robot, formulated the differential speed turning method, and completed preliminary 3D modeling of key components. The team also sorted out design and modeling problems and put forward feasible preliminary solutions.

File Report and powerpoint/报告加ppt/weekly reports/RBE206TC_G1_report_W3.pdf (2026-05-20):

## RBE206TC

Project-based Practice
in Intelligent Robotics
- 1 -

## Technical Progress Report

Project name: | Biped robot
Group member: | Yangnan.yan 2363610 Jiarui.li 2360655 xinhang.li 2363444 Jian.wang 2362488 | Group number: | 1
Start date: | 2026-03-14 | End date: | 2026-03-20
Project manager: | Dr. Ki-Young Song

### 1. Executive Summary

This report summarizes the technical progress of the biped robot project in the past week. The team successfully completed the motor connection and confirmed the correct pin positions. However, the 3D-printed structural parts failed to fit the motors properly due to insufficient tolerance design, so assembly is suspended until revised parts are printed next week.

### 2. Objectives & Scope

Complete motor wiring and confirm pin definitions for the biped robot. Assemble mechanical structures and install motors into 3D-printed parts. Test basic motor operation and prepare for subsequent motion control.

### 3. Technical Work Completed

3.1 Electrical Connection & Pin Definition
- Successfully connected all motors of the biped robot.
- Confirmed and fixed the pin positions for control and power supply.
- Verified basic power conduction and circuit connectivity.

3.2 Mechanical Structure Inspection
- Inspected the size and assembly fit of 3D-printed structural parts.
- Checked the matching between motor appearance and installation slots.

3.3 Hardware Preparation
- Prepared motor drivers, main controller, and power supply modules.
- Completed pre-debugging of the electrical system.

### 4. Observations & Findings

- Motor wiring and pin definition are accurate and reliable.
- The 3D-printed parts lack sufficient tolerance for motor installation.
- Motors cannot be fixed into the preset positions correctly.
- Mechanical assembly cannot be carried out until parts are re-printed.

## RBE206TC

Project-based Practice
in Intelligent Robotics
- 2 -

### 5. Challenges & Roadblocks

- 3D printing design did not consider motor size tolerance, leading to installation mismatch.
- Structural assembly is blocked, delaying the overall integration progress.
- No effective temporary adjustment for the ill-fitting printed parts.

### 6. Next Steps & Recommendations

- Redesign 3D-printed structural parts with proper installation tolerance and clearance.
- Re-print the modified mechanical parts as soon as possible.
- Complete motor installation and structural assembly next week.
- Conduct motor drive tests and preliminary motion debugging after assembly.

### 7. Conclusion

This week, the electrical system of the biped robot made smooth progress, with successful motor connection and pin confirmation. Mechanical assembly was suspended due to insufficient tolerance in 3D-printed parts. The overall progress is under control, and assembly and debugging will be finished next week after re-printing.

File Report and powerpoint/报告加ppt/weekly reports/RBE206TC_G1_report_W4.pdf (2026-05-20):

## RBE206TC

Project-based Practice
in Intelligent Robotics
- 1 -

## Technical Progress Report

Project name: | Biped robot
Group member: | Yangnan.yan 2363610 Jiarui.li 2360655 xinhang.li 2363444 Jian.wang 2362488 | Group number: | 1
Start date: | 2026-03-21 | End date: | 2026-03-27
Project manager: | Dr. Ki-Young Song

### 1. Executive Summary

This report summarizes the technical progress of the biped robot project this week. The core team has completed the setup and debugging of the visual recognition module (camera), achieving basic color recognition functionality, but the accuracy of shape recognition is insufficient, and black objects on a black desktop are prone to error recognition, which is a core optimization issue at this stage; after optimization, attempts were made to produce and assemble 3D printed structural components, but it was found that the motor could not be driven normally. Currently, fault 排查 work is underway and it is expected to be resolved next

week; at the same time， the wiring of the motor / servo， pin definitions， and the initial development of an

external virtual website to control the servo were completed， enabling basic remote control. In the future，

the core will be the optimization of the camera recognition algorithm and the fault 排查 of the motor drive，

while simultaneously advancing the mechanical assembly and iterative development of the virtual website functions.

### 2. Objectives & Scope

Complete the hardware setup and software debugging of the visual recognition module (camera) for the biped robot, achieving the recognition of the color and shape of the target object; complete the wiring and pin definitions of the robot's motors / steering gears, prepare the core hardware and complete the pre-test of the electrical system; complete the mechanical assembly of the optimized 3D printed structural components, test the basic drive and operation functions of the motors; develop an external virtual control website to realize the basic remote control of the robot's steering gears; lay the hardware and software foundation for subsequent motion control, system integration and algorithm optimization.

- 2 -

### 3. Technical Work Completed

3.1 Visual Recognition Module (Camera) Setup and Debugging

Complete the hardware deployment of the ESP32-CAM camera module, achieve circuit connection with the

main controller, power matching, and communication pin definition, and complete module initialization and

normal startup; Write and debug the image acquisition and preprocessing program, realize real-time image

acquisition, transmission, and display, optimize camera exposure and brightness parameters, solve the problem

of white screen and overexposure, and improve color reproduction; Build an identification model based on the

HSV color space, collect multi-color sample sets for training, achieve effective identification of pure colors and

regular mixed-color objects, and control the response delay of identification; Build a shape recognition

framework based on contour detection, complete the collection and training of basic shape samples, realize

basic recognition in a simple non-interfering background; Build a multi-condition testing environment, test the

identification function and record results, errors, and failure scenarios, providing data support for algorithm optimization.

3.2 Electrical Connection & Hardware Preparation

Complete the wiring deployment of all motors / servo motors, without any loose or incorrect connections,

confirm and fix the positions of control and power supply pins, and standardize pin definitions; Prepare core

hardware such as motor / servo motor drivers, main controllers, power supply modules, etc., conduct on-off tests and pre-debugging of the electrical system, verify power conduction, circuit reliability, and basic hardware linkage.

3.3 Mechanical Structure Assembly & Motor Test

Complete the production of optimized 3D printed structural components, successfully complete the assembly

of motors / servo motors and structural components; Conduct basic motor drive tests, discover that the motor

cannot be driven normally, immediately start the fault troubleshooting work, and preliminarily complete the basic detection of hardware circuits, power supply modules.

3.4 Research on External Virtual Control Website

Complete the preliminary framework setup of the external virtual control website, determine the wireless

communication protocol with the main controller, achieve stable communication connection between the two;

Develop the basic control interface of the website, realize remote adjustment of single servo motor angles and simple combined action control, complete the stability test of signal transmission in the laboratory environment.

### 4. Observations & Findings

- 3 -

4.1 Core Findings of the Visual Recognition Module (Camera)

The color recognition function is overall effective. In environments with sufficient light and a single

background, the accuracy of recognizing conventional colors such as red, yellow, blue, and green is relatively

high, and the color threshold division is reasonable; The shape recognition is the core weakness. When there is

slight occlusion, blurred contours, or background interference, it is very prone to misjudgment. It can only

achieve basic recognition in a very simple background; The recognition of black objects on a black desktop is

highly likely to fail. The low contrast between the two makes the target contour unable to stand out, and the

algorithm cannot accurately extract features, resulting in missed recognition and misrecognition; Changes in

light have a significant impact on the recognition effect. In low-light environments, the accuracy of color recognition decreases, the difficulty of extracting the contour of shapes increases, and the light adaptation

ability of the camera and the algorithm is insufficient; The basic image preprocessing algorithm cannot

effectively filter noise and enhance contours, which indirectly affects the accuracy of shape recognition.

4.2 Findings of the Mechanical and Electrical Modules

After optimization, the tolerance design of the 3D printed structural components is reasonable, and they can

be precisely adapted to the motor / actuator. The mechanical assembly work was successfully completed; The

motor drive test found that the motor could not operate normally. The initial investigation did not find any

issues such as loose wiring or power supply interruption. The cause of the fault has not been located yet; The

wiring and pin definitions of the motor / actuator are accurate, and the electrical system is conducting normally. The pre-verification response of each hardware module was normal, and the basic wiring faults were excluded.

4.3 Findings of the External Virtual Control Website

The virtual website can realize the basic remote control of the servo motor. In the laboratory environment, the

signal transmission is stable and there is no obvious delay. The communication link is reliable; The operation

interface of the website is not convenient. It only supports simple single-action control, and the control logic for complex combined movements has not been developed.

### 4. Challenges & Roadblocks

- 5.1 Core Challenges of the Visual Recognition Module (Camera)
- The shape recognition algorithm lacks robustness. The simple contour detection logic cannot handle actual scenarios such as background interference and slight occlusion, and lacks the ability to adapt to complex situations; There is no effective recognition method for scenes with similar colors and low contrast. The existing algorithm relies on the differentiation of color and contour, but cannot solve the problem of identifying black objects on a black desktop; The camera's environmental adaptability is poor. Manual parameter adjustment has limited effect. The algorithm lacks a light adaptation compensation mechanism, and the recognition effect significantly decreases in non-ideal lighting conditions;The image preprocessing process is

- 4 -

not complete. The basic algorithm cannot optimize the picture quality, and noise and blurriness problems directly affect the accuracy of shape recognition.
•
- 5.2 Core Challenges of the Mechanical and Electrical Module
- After the motor assembly is completed, it cannot drive normally. The cause of the failure has not been located yet. A deep investigation needs to be conducted from multiple aspects such as the driver, control signals, and the motor itself;The motor drive failure has prevented the subsequent motion control tests and system integration work from progressing, becoming the main obstacle in the current project advancement.
•
- 5.3 Other Module Challenges
- The external virtual control website lacks the combined motion control logic for the external devices. Function development needs to combine the motor drive and mechanical motion parameters. Further progress is temporarily impossible;The system integration of the visual recognition and motion control modules cannot be carried out. The motor drive failure has prevented the recognition signal from the camera from being transmitted to the actuating component, and the overall system integration work has been hindered.

### 6. Next Steps & Recommendations

Optimize the shape recognition algorithm by introducing contour feature point extraction and matching

technology, and adding core feature recognition such as corner points and edge length ratios, to enhance the recognition ability in complex scenarios and reduce the error rate

### 7. Conclusion

This week, the core of the biped robot project completed the setup and debugging of the visual recognition module (camera), achieving basic color recognition. However, the accuracy of shape recognition is insufficient, and the problem of frequent errors when recognizing black objects on a black surface still lies at the core of the optimization direction. After optimization, the 3D printing of structural components and their assembly were completed, but it was discovered that the motor could not be driven normally. Currently, fault investigation is underway and is expected to be resolved next week. At the same time, the wiring of the motor / steering gear, pin definitions, and pre-testing of the electrical system were successfully completed. An external virtual control website was implemented to achieve basic remote control of the steering gear. The motor drive failure has become the main obstacle in the progress of the project at present, preventing the conduct of motion control tests, system integration, and other related work. The overall progress of the project is controllable. Next week, the focus will be on optimizing the camera recognition algorithm, troubleshooting and repairing the motor drive failure, and immediately advancing the motor motion debugging, iterative improvement of the virtual website functions, and the linkage debugging of the visual recognition and motion control modules, gradually resolving the core technical difficulties at present and ensuring the project progresses as planned.

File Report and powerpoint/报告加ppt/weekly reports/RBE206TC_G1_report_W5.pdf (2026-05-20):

## RBE206TC

Project-based Practice
in Intelligent Robotics
- 1 -

## Technical Progress Report

Project name: | Biped robot
Group member: | Yangnan.yan 2363610 Jiarui.li 2360655 xinhang.li 2363444 Jian.wang 2362488 | Group number: | 1
Start date: | 2026-03-30 | End date: | 2026-04-4
Project manager: | Dr. Ki-Young Song

### 1. Executive Summary

This report summarizes the technical progress of the biped robot project in this week. The team has fully completed the mechanical assembly and electrical connection of the biped robot, and verified the normal operation of the camera vision module and the external virtual control website. During the initial walking test, it was found that a single foot cannot support the weight of the whole robot, resulting in unstable standing and failure to complete continuous walking. In addition, the heavy battery brings extra load and the battery fixing scheme is not confirmed yet. The team plans to redesign the foot structure into an I-shape to improve support area and stability, and develop a reliable battery fixing method to ensure stable standing and smooth walking in the next stage.

2.Objectives & Scope
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

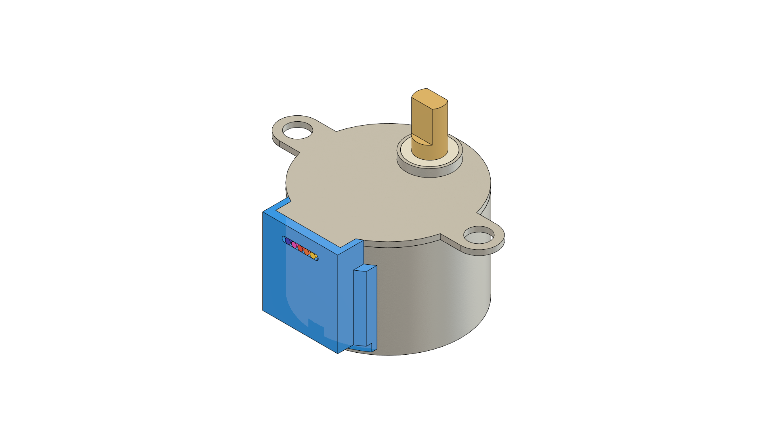
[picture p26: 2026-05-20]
oodk(CAD model)/odk2（Generation 2）/28BYJ-48步进电机和ULN2003步进电机驱动板/28BYJ-48_5VDC_ISO2.png

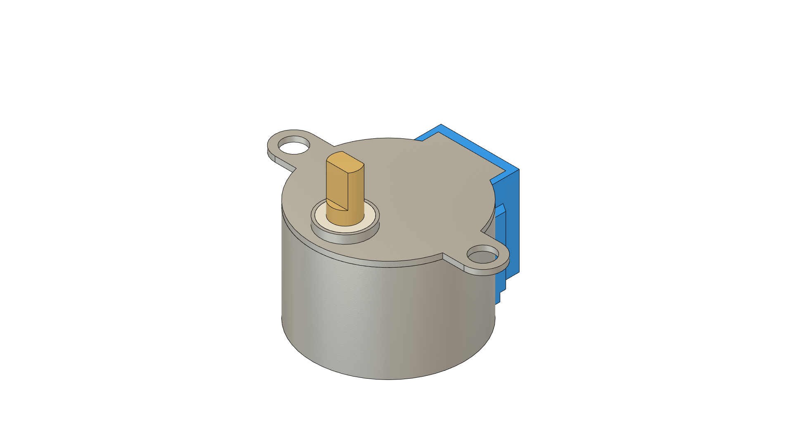
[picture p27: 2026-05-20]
oodk(CAD model)/odk2（Generation 2）/28BYJ-48步进电机和ULN2003步进电机驱动板/28BYJ-48_5VDC_ISO.png

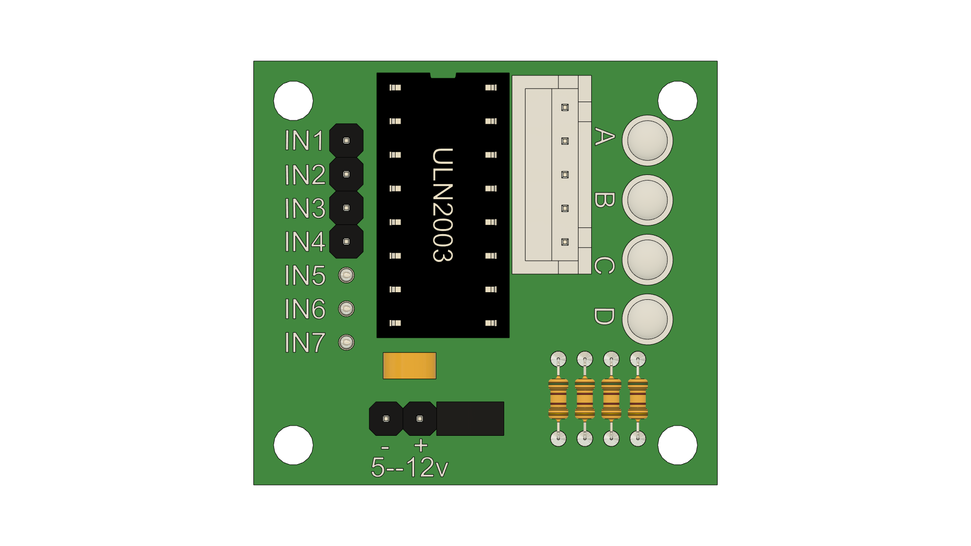
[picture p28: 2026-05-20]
oodk(CAD model)/odk2（Generation 2）/28BYJ-48步进电机和ULN2003步进电机驱动板/ULN2003_Stepper_Motor_Driver_Board_TOP.png

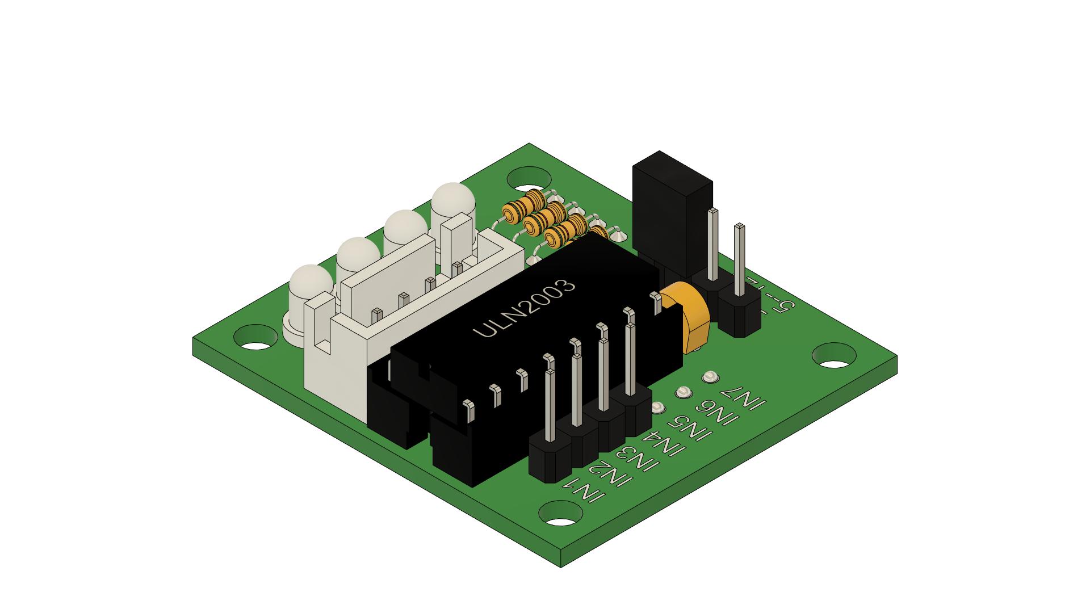
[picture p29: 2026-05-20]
oodk(CAD model)/odk2（Generation 2）/28BYJ-48步进电机和ULN2003步进电机驱动板/ULN2003_Stepper_Motor_Driver_Board_ISO.jpg

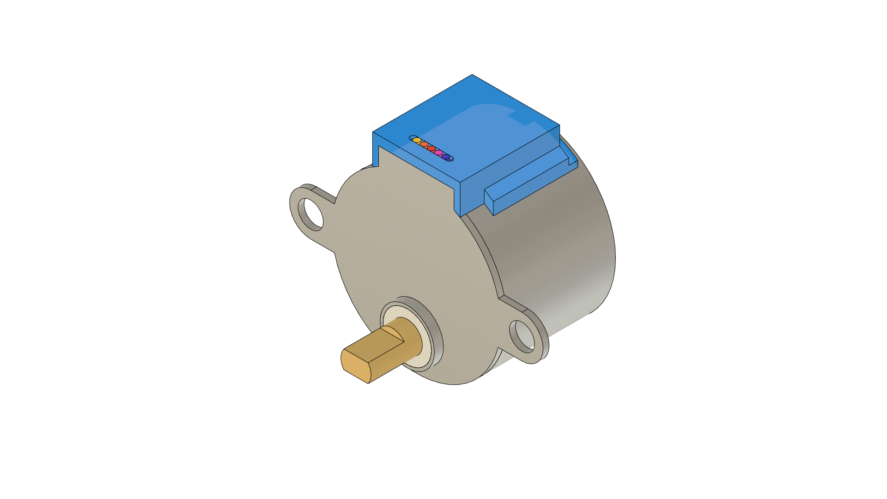
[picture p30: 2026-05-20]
oodk(CAD model)/odk2（Generation 2）/28BYJ-48步进电机和ULN2003步进电机驱动板/28BYJ-48_5VDC_ISO1.png

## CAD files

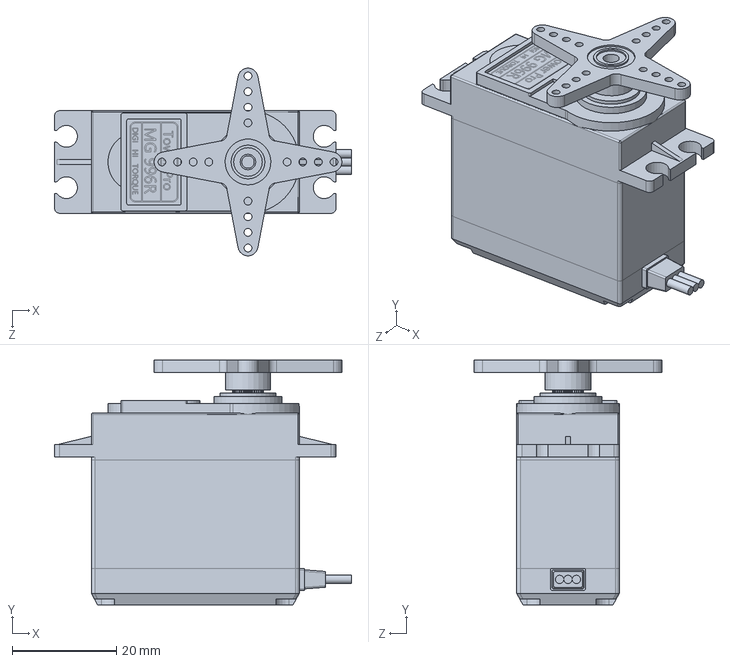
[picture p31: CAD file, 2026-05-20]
oodk(CAD model)/odk1（Generation 1）/十字舵机.SLDPRT
57.0 x 46.9 x 36.0 mm

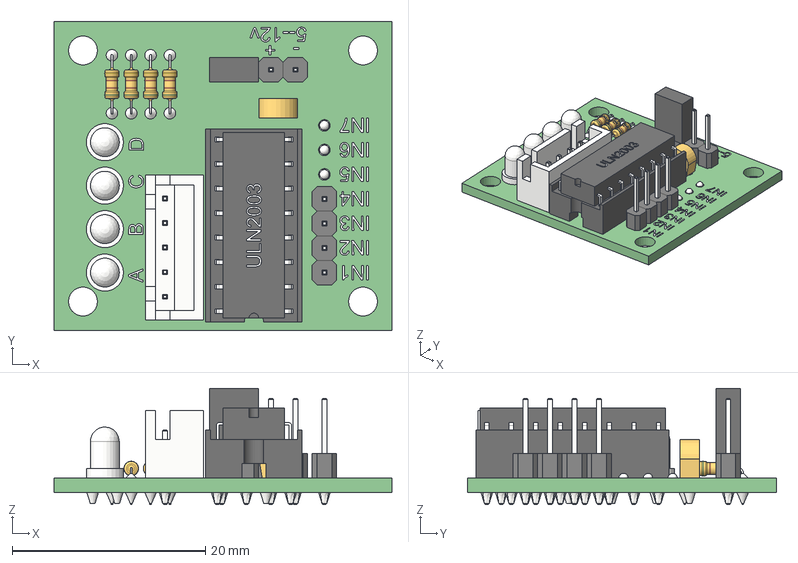
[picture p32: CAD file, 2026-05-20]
oodk(CAD model)/odk2（Generation 2）/28BYJ-48步进电机和ULN2003步进电机驱动板/ULN2003_Stepper_Motor_Driver_Board.step
35.0 x 32.0 x 12.0 mm
board
5.2Kohm x 4
LED_Small x 4
DIP_16_Socket
ULN2003_DIP-16L
Pin_Header x 8
ceramic_capacitor_104
plug_uln2003
solder x 29
solder2 x 10
solder1 x 8
solder_dot_round x 3
cap

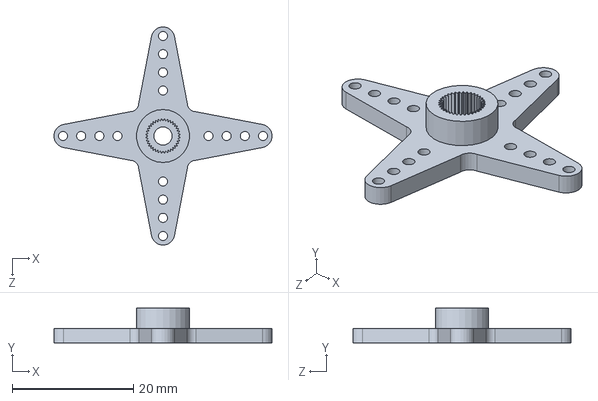
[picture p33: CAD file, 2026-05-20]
oodk(CAD model)/odk2（Generation 2）/MG996R_4叶.SLDPRT
36.0 x 5.75 x 36.0 mm

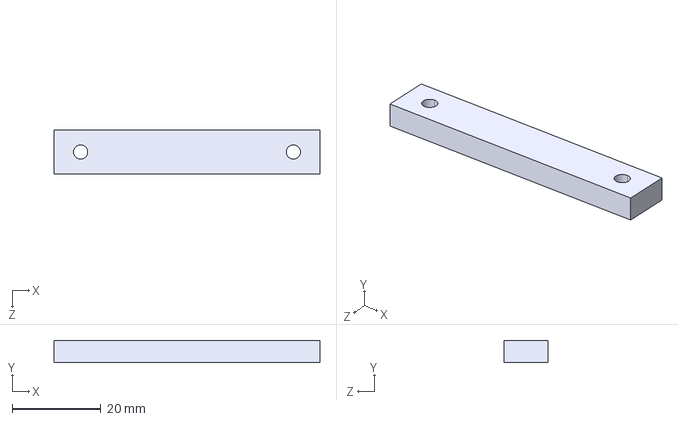
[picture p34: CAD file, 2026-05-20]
oodk(CAD model)/odk2（Generation 2）/print/22.STEP
60.0 x 5.00 x 10.0 mm

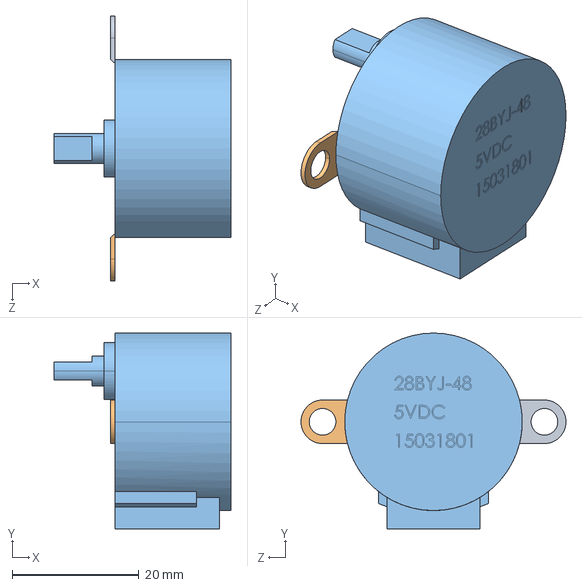
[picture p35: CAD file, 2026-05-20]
oodk(CAD model)/odk2（Generation 2）/步进电机 28BYJ-48/Step Motor 28BYJ-48.STEP
27.9 x 30.9 x 41.8 mm

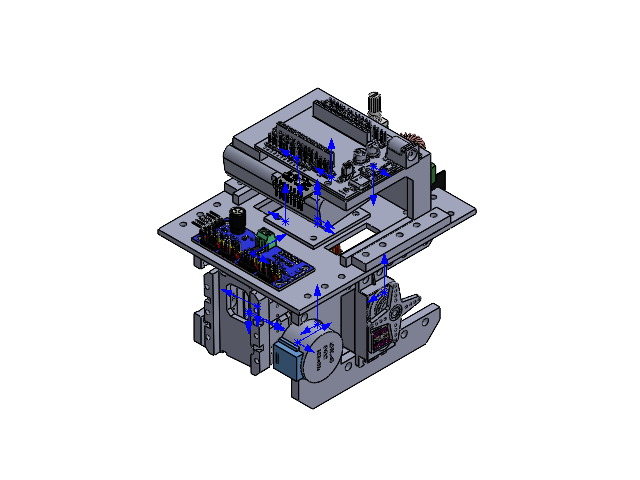
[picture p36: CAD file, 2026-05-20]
oodk(CAD model)/odk3（Generation 3）/胯部以及硬件仓.SLDASM
新plat
十字舵机 x 2
MPU6050
ESP32拓展板26
PCA9685
XH-M401 Buck converter (XL4016E1)
esp32_dc
LB218B
Step Motor 28BYJ-48
摄像机壳3
摄像机壳1
摄像机壳2
横_
MPU

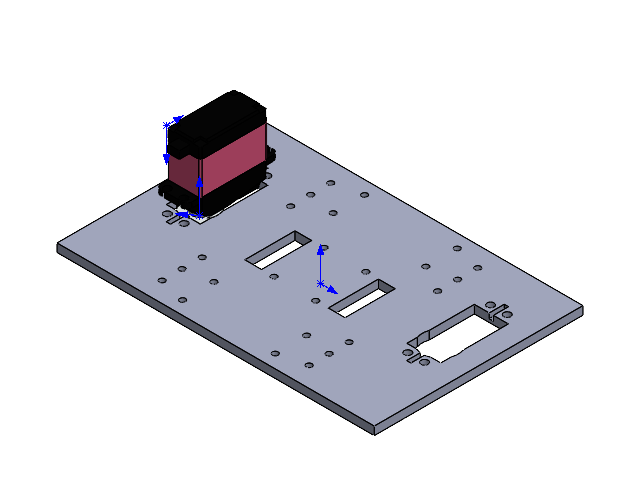
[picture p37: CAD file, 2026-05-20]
oodk(CAD model)/odk4（Generation 4）/plat_.SLDASM
新plat
DS3218MG
Servo disc

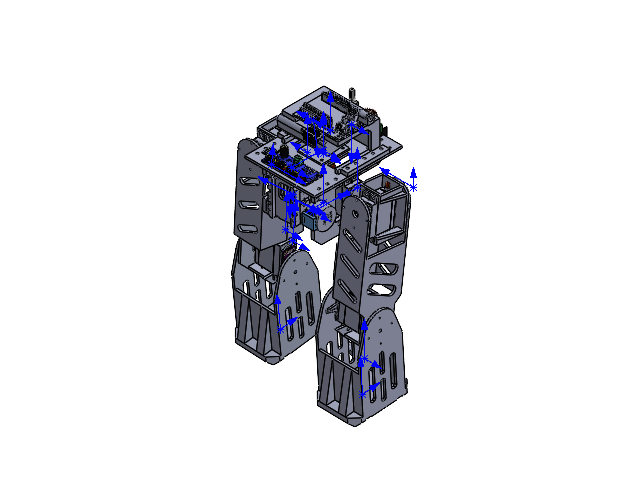
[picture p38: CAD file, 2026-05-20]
oodk(CAD model)/odk2（Generation 2）/odk2.SLDASM
新plat
十字舵机 x 6
MPU6050
ESP32拓展板26
PCA9685
XH-M401 Buck converter (XL4016E1)
esp32_dc
LB218B
Step Motor 28BYJ-48
摄像机壳3
摄像机壳1
摄像机壳2
横_
MPU
髋部连接件-右
髋部连接件-左
大腿-右
大腿-左
小腿 x 2

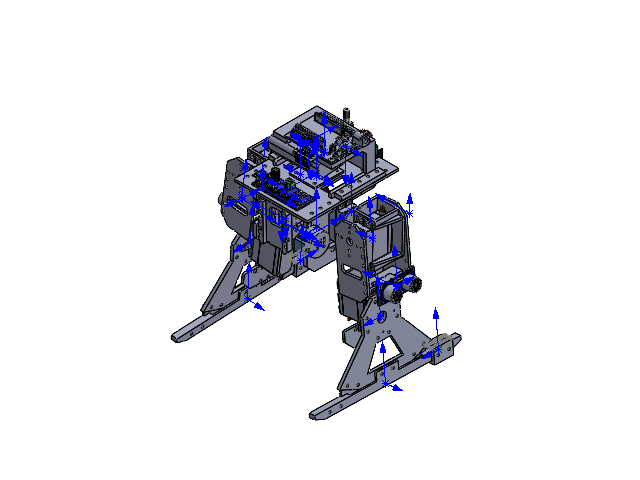
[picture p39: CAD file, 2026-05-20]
oodk(CAD model)/odk3（Generation 3）/odk3.SLDASM
新plat
十字舵机 x 6
MPU6050
ESP32拓展板26
PCA9685
XH-M401 Buck converter (XL4016E1)
esp32_dc
LB218B
Step Motor 28BYJ-48
摄像机壳3
摄像机壳1
摄像机壳2
横_
MPU
髋部连接件-右
髋部连接件-左
thigh
Sensor Ultrasonic x 2
HC_loa x 2
板1 x 2
Mirrorthigh

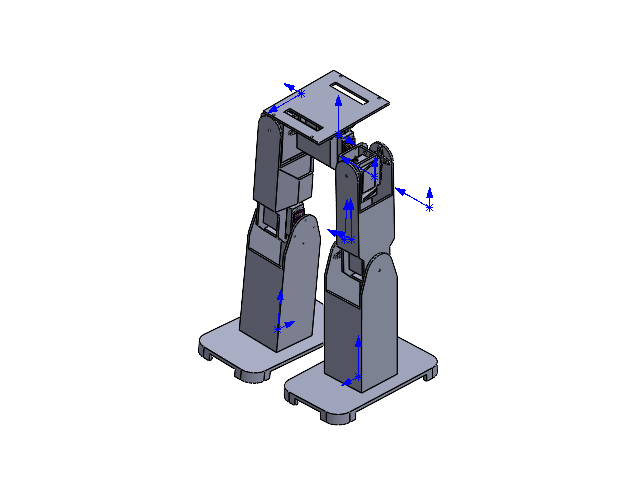
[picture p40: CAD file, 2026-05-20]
oodk(CAD model)/odk1（Generation 1）/机器人2.0.SLDASM
髋部
十字舵机 x 6
髋部连接件-左
大腿-左
小腿 x 2
髋部连接件-右
大腿-右

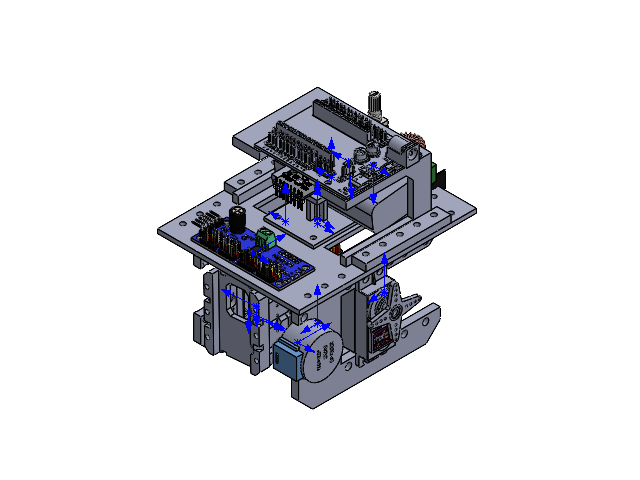
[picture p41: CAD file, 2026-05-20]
oodk(CAD model)/odk2（Generation 2）/胯部以及硬件仓.SLDASM
新plat
十字舵机 x 2
MPU6050
ESP32拓展板26
PCA9685
XH-M401 Buck converter (XL4016E1)
esp32_dc
LB218B
Step Motor 28BYJ-48
摄像机壳3
摄像机壳1
摄像机壳2
横_
MPU

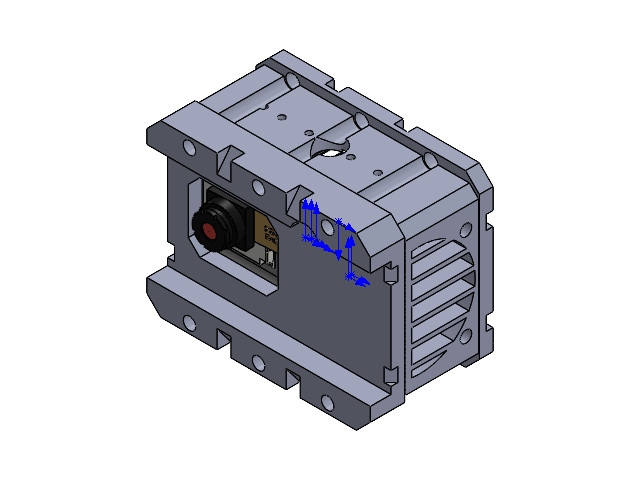
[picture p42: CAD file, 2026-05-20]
oodk(CAD model)/odk3（Generation 3）/摄像机壳.SLDASM
摄像机壳3
摄像机壳1
摄像机壳2

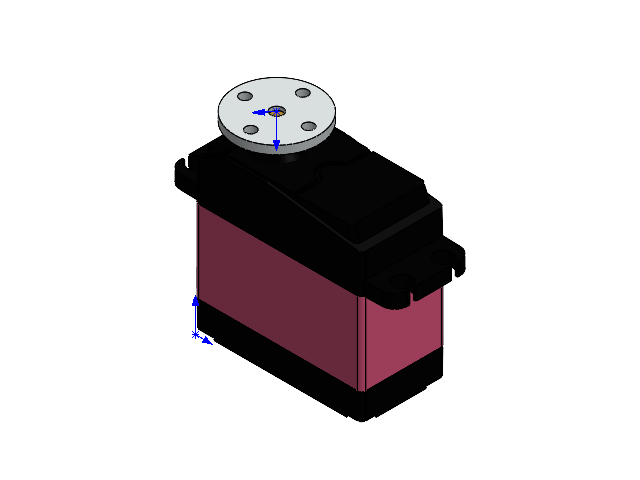
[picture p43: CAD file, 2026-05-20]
oodk(CAD model)/odk4（Generation 4）/ds3218_伺服盘.SLDASM
DS3218MG
Servo disc

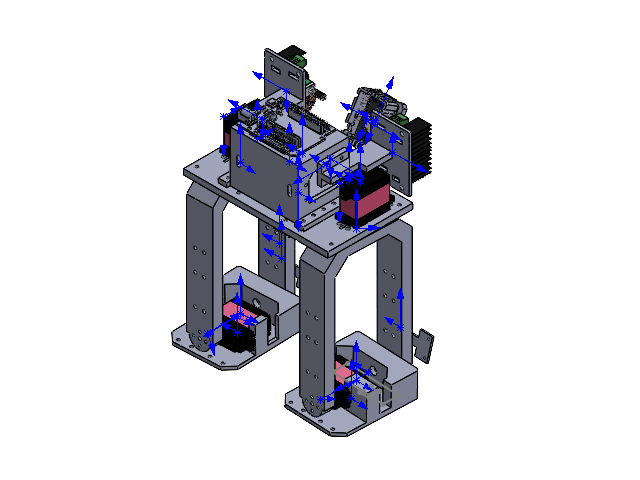
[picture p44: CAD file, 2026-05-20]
oodk(CAD model)/odk4（Generation 4）/otto_odk.SLDASM
feet1
leg2 x 2
新plat
DS3218MG x 4
Servo disc x 4
ESP32拓展板26
esp32_dc
PCA9685
XH-M401 Buck converter (XL4016E1) x 2
MPU
ESP32-S
摄像机壳1
摄像机壳2
Mirrorfeet1
ul x 2
c_pl_
cd
Mirrorcd
Sensor Ultrasonic
MPU6050

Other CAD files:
oodk(CAD model)/odk4（Generation 4）/cam_mera.SLDASM
oodk(CAD model)/odk2（Generation 2）/odk3.SLDASM
oodk(CAD model)/odk2（Generation 2）/摄像机壳.SLDASM
oodk(CAD model)/odk2（Generation 2）/髋.SLDASM
oodk(CAD model)/odk1（Generation 1）/大腿-右.SLDPRT
oodk(CAD model)/odk1（Generation 1）/大腿-左.SLDPRT
oodk(CAD model)/odk1（Generation 1）/大腿.SLDPRT
oodk(CAD model)/odk1（Generation 1）/小腿.SLDPRT
oodk(CAD model)/odk1（Generation 1）/髋部.SLDPRT
oodk(CAD model)/odk1（Generation 1）/髋部连接件-右.SLDPRT
oodk(CAD model)/odk1（Generation 1）/髋部连接件-左.SLDPRT
oodk(CAD model)/odk1（Generation 1）/髋部连接件.SLDPRT
oodk(CAD model)/odk2（Generation 2）/22.SLDPRT
oodk(CAD model)/odk2（Generation 2）/28BYJ-48步进电机和ULN2003步进电机驱动板/28BYJ-48_5VDC.f3d
oodk(CAD model)/odk2（Generation 2）/28BYJ-48步进电机和ULN2003步进电机驱动板/28BYJ-48_5VDC.step
oodk(CAD model)/odk2（Generation 2）/28BYJ-48步进电机和ULN2003步进电机驱动板/ULN2003_Stepper_Motor_Driver_Board.f3d
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

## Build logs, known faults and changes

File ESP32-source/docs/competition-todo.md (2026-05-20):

# Competition Todo

## Current 5-Step Plan

1. Add 2 or 4 black-line boundary sensors.
   - Minimum: 2 sensors at front-left and front-right.
   - Better: 4 sensors at front-left, front-right, rear-left, and rear-right.
   - Goal: detect the black boundary line before the robot leaves the allowed area.

2. Implement `boundary_guard` in the ESP32 robot firmware.
   - Boundary detection must have the highest priority.
   - If the left sensor detects the line: stop, back up, then turn right.
   - If the right sensor detects the line: stop, back up, then turn left.
   - If both sensors detect the line: stop, back up longer, then rotate away.

3. Turn the `Final go!` page from a placeholder into the real run entry point.
   - `Go!` should start the actual competition state machine.
   - `Stop` should send a real stop/emergency-stop command.
   - `Resume` should continue from a known safe state.

4. Complete Task 1 first.
   - Search for and approach the black column.
   - Avoid the 4 yellow obstacles.
   - Stay inside the black boundary.
   - Confirm touch or arrival at the black column.

5. Complete Task 2 after Task 1 is stable.
   - Use the selected random target color and shape.
   - Detect one of the 12 target labels.
   - Search, align, approach, and touch the selected object.
   - Keep boundary protection active during the whole process.

## Priority

The immediate next work should be:

1. Hardware: add black-line sensors.
2. Firmware: add `boundary_guard`.
3. Software: connect `Final go!` to the real autonomous flow.

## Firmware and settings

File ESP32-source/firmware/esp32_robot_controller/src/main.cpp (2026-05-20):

#include <Arduino.h>
#include <AsyncTCP.h>
#include <ESPAsyncWebServer.h>
#include <ArduinoJson.h>
#include <Update.h>
#include <WiFi.h>
#include <Wire.h>
#include <Preferences.h>
#include "robot_config.h"
#include "secrets.h"

AsyncWebServer server(80);
AsyncWebSocket socketServer("/ws");
Preferences preferences;
Preferences ottoPreferences;

namespace {
constexpr uint8_t PCA9685_MODE1_REGISTER = 0x00;
constexpr uint8_t PCA9685_MODE2_REGISTER = 0x01;
constexpr uint8_t PCA9685_PRESCALE_REGISTER = 0xFE;
constexpr uint8_t PCA9685_LED0_ON_L_REGISTER = 0x06;
constexpr uint8_t MPU6050_WHO_AM_I_REGISTER = 0x75;
constexpr uint8_t MPU6050_PWR_MGMT_1_REGISTER = 0x6B;
constexpr uint8_t MPU6050_SMPLRT_DIV_REGISTER = 0x19;
constexpr uint8_t MPU6050_CONFIG_REGISTER = 0x1A;
constexpr uint8_t MPU6050_GYRO_CONFIG_REGISTER = 0x1B;
constexpr uint8_t MPU6050_ACCEL_CONFIG_REGISTER = 0x1C;
constexpr uint8_t MPU6050_ACCEL_XOUT_H_REGISTER = 0x3B;
constexpr float MPU6050_ACCEL_SCALE = 16384.0f;
constexpr float MPU6050_GYRO_SCALE = 131.0f;
constexpr float K_RADIANS_TO_DEGREES = 57.2957795f;
constexpr float K_DEGREES_TO_RADIANS = 0.0174532925f;
constexpr float PENGUIN_SHIFT_LEAN_FACTOR = 0.45f;
constexpr float PENGUIN_SWING_LEAN_FACTOR = 0.72f;
constexpr uint8_t SERVO_LEFT_KNEE = 0;
constexpr uint8_t SERVO_RIGHT_KNEE = 1;
constexpr uint8_t SERVO_LEFT_HIP_ROLL = 2;
constexpr uint8_t SERVO_RIGHT_HIP_ROLL = 3;
constexpr uint8_t SERVO_LEFT_HIP_PITCH = 4;
constexpr uint8_t SERVO_RIGHT_HIP_PITCH = 5;
constexpr uint8_t SERVO_NECK = 6;
constexpr uint8_t SERVO_OTTO_LEFT_LEG = 0;
constexpr uint8_t SERVO_OTTO_RIGHT_LEG = 1;
constexpr uint8_t SERVO_OTTO_RIGHT_HIP = 7;
constexpr uint8_t SERVO_OTTO_LEFT_HIP = 8;
constexpr unsigned long LATERAL_STEP_PHASE_MS = 450;
constexpr unsigned long FORWARD_STEP_PHASE_MS = 650;
constexpr unsigned long FORWARD_WEIGHT_SHIFT_MS = 650;
constexpr float LEFT_LEAN_OFFSET = -4.0f;
constexpr float RIGHT_LEAN_OFFSET = 4.0f;
constexpr unsigned long OTTO_GAIT_PERIOD_MS = 1200;
constexpr unsigned long OTTO_GAIT_SAMPLE_MS = 30;
constexpr float OTTO_LEG_AMPLITUDE_DEG = 18.0f;
constexpr float OTTO_TURN_INNER_LEG_AMPLITUDE_DEG = 7.0f;
constexpr float OTTO_HIP_AMPLITUDE_DEG = 12.0f;
constexpr float OTTO_STRAIGHT_LEFT_LEG_AMPLITUDE_DEG = 12.0f;
constexpr float OTTO_STRAIGHT_RIGHT_LEG_AMPLITUDE_DEG = 10.5f;
constexpr float OTTO_STRAIGHT_LEFT_HIP_AMPLITUDE_DEG = 18.0f;
constexpr float OTTO_STRAIGHT_RIGHT_HIP_AMPLITUDE_DEG = 16.5f;
constexpr float OTTO_LEFT_LEG_OFFSET_DEG = 2.0f;
constexpr float OTTO_RIGHT_LEG_OFFSET_DEG = -2.0f;
constexpr float OTTO_LEFT_HIP_OFFSET_DEG = 2.0f;
constexpr float OTTO_RIGHT_HIP_OFFSET_DEG = -2.0f;
constexpr float OTTO_LEFT_TURN_INNER_LEG_SCALE = 0.45f;
constexpr float OTTO_LEFT_TURN_OUTER_LEG_SCALE = 0.85f;
constexpr float OTTO_LEFT_TURN_INNER_HIP_SCALE = 0.12f;
constexpr float OTTO_LEFT_TURN_OUTER_HIP_SCALE = 0.95f;
constexpr float OTTO_TURN_INNER_SIDE_SCALE = 0.20f;
constexpr float OTTO_TURN_OUTER_SIDE_SCALE = 1.35f;
constexpr float OTTO_SHIFT_LEG_DRAG_SCALE = 0.65f;
constexpr float OTTO_SHIFT_HIP_OFFSET_DEG = 10.0f;
constexpr uint32_t OTTO_MOTION_PROFILE_STORAGE_VERSION = 3;
constexpr size_t OTTO_MOTION_PROFILE_COUNT = 8;
constexpr const char* const OTTO_MOTION_PROFILE_NAMES[OTTO_MOTION_PROFILE_COUNT] = {
  "otto_forward",
  "otto_async_forward",
  "otto_backward",
  "otto_async_backward",
  "otto_left",
  "otto_right",
  "otto_shift_left",
  "otto_shift_right"
};
constexpr float K_TWO_PI = 6.2831853f;
constexpr float K_PI = 3.1415926f;
constexpr float K_HALF_PI = 1.5707963f;
constexpr float K_ONE_THIRD_PI = 1.0471976f;
}

struct GaitParams {
  float leanAngleDeg = 8.0f;
  float hipSwingDeg = 12.0f;
  float kneeLiftDeg = 14.0f;
  float stanceKneeDeg = 104.0f;
  unsigned long doubleSupportMs = 240;
  unsigned long swingPhaseMs = 460;
  float torsoLeadDeg = 1.0f;
  float neckTrimDeg = 1.5f;
};

enum class GaitPhase : uint8_t {
  Idle,
  ShiftLeft,
  SwingRight,
  ShiftRight,
  SwingLeft
};

struct GaitState {
  bool active = false;
  bool telemetryAvailable = false;
  bool manualControl = false;
  uint32_t trialId = 0;
  unsigned long startedAt = 0;
  unsigned long phaseStartedAt = 0;
  unsigned long durationMs = 0;
  uint32_t stepCount = 0;
  float estimatedForwardProgress = 0.0f;
  float baselineYaw = 0.0f;
  float baselineRoll = 0.0f;
  float stabilityScore = 0.0f;
  float lateralDriftMeters = 0.0f;
  float yawDriftDeg = 0.0f;
  GaitPhase phase = GaitPhase::Idle;
  GaitParams params;
};

enum class LateralStepPhase : uint8_t {
  Idle,
  PreloadRight,
  ShiftLeft,
  ShiftRight
};

struct LateralStepState {
  bool active = false;
  unsigned long phaseStartedAt = 0;
  uint32_t cycleCount = 0;
  LateralStepPhase phase = LateralStepPhase::Idle;
};

enum class ForwardStepPhase : uint8_t {
  Idle,
  ShiftToRightForLeft,
  LeftLift,
  LeftSwing,
  LeftLand,
  ShiftToLeftForSupport,
  LeftFollow,
  RightLift,
  RightSwing,
  RightLand,
  ShiftToRightForSupport,
  RightFollow
};

struct ForwardStepState {
  bool active = false;
  bool flatFootVariant = false;
  unsigned long phaseStartedAt = 0;
  uint32_t cycleCount = 0;
  ForwardStepPhase phase = ForwardStepPhase::Idle;
};

enum class OttoMoveMode : uint8_t {
  Idle,
  StraightForward,
  AsyncForward,
  StraightBackward,
  AsyncBackward,
  Forward,
  Backward,
  TurnLeft,
  TurnLeftFast,
  TurnRight,
  ShiftLeft,
  ShiftRight
};

enum class Task1AutopilotPhase : uint8_t {
  Idle,
  StartForward,
  FirstBypassTurnRight,
  FirstBypassForward,
  FirstBypassTurnLeft,
  GateForward,
  ApproachBlack,
  Completed
};

enum class Task1FrontPoleBypassPhase : uint8_t {
  Idle,
  Approach,
  CenterBeforeTurnRightOut,
  TurnRightOut,
  CenterBeforeForwardSideEntry,
  ForwardSideEntry,
  CenterBeforeTurnLeftAlongside,
  TurnLeftAlongside,
  CenterBeforeForwardPassSide,
  ForwardPassSide,
  CenterBeforeTurnLeftReturn,
  TurnLeftReturn,
  CenterBeforeForwardReturnCenter,
  ForwardReturnCenter,
  CenterBeforeTurnRightRecover,
  TurnRightRecover,
  CenterAfterRecover,
  Completed
};

struct VisionAutopilotState {
  bool enabled = VISION_UART_AUTOPILOT_ENABLED;
  String task = "idle";
  bool hasTarget = false;
  unsigned long lastSeenAt = 0;
  unsigned long lastCommandAt = 0;
  OttoMoveMode activeMode = OttoMoveMode::Idle;
  Task1AutopilotPhase task1Phase = Task1AutopilotPhase::Idle;
  unsigned long task1PhaseStartedAt = 0;
  int task1TargetCx = -1;
  int task1TargetFrameWidth = 0;
  float task1TargetConfidence = 0.0f;
};

struct Task1FrontPoleBypassState {
  bool active = false;
  Task1FrontPoleBypassPhase phase = Task1FrontPoleBypassPhase::Idle;
  unsigned long phaseStartedAt = 0;
};

struct BoundaryGuardState {
  bool configured = false;
  bool active = false;
  bool leftFront = false;
  bool rightFront = false;
  bool leftRear = false;
  bool rightRear = false;
  unsigned long lastTriggeredAt = 0;
  String lastTrigger = "";
};

struct UltrasonicState {
  bool enabled = ULTRASONIC_ENABLED;
  bool centerValid = false;
  float centerCm = 0.0f;
  unsigned long lastReadAt = 0;
};

struct OttoMotionProfile {
  float leftLegAmplitudeDeg;
  float rightLegAmplitudeDeg;
  float leftHipAmplitudeDeg;
  float rightHipAmplitudeDeg;
  unsigned long periodMs;

  constexpr OttoMotionProfile()
    : leftLegAmplitudeDeg(0.0f),
      rightLegAmplitudeDeg(0.0f),
      leftHipAmplitudeDeg(0.0f),
      rightHipAmplitudeDeg(0.0f),
      periodMs(OTTO_GAIT_PERIOD_MS) {}

  constexpr OttoMotionProfile(
    float leftLegAmplitude,
    float rightLegAmplitude,
    float leftHipAmplitude,
    float rightHipAmplitude,
    unsigned long period = OTTO_GAIT_PERIOD_MS)
    : leftLegAmplitudeDeg(leftLegAmplitude),
      rightLegAmplitudeDeg(rightLegAmplitude),
      leftHipAmplitudeDeg(leftHipAmplitude),
      rightHipAmplitudeDeg(rightHipAmplitude),
      periodMs(period) {}
};

constexpr OttoMotionProfile OTTO_DEFAULT_MOTION_PROFILES[OTTO_MOTION_PROFILE_COUNT] = {
  {12.0f, 11.6f, 18.0f, 18.2f},
  {10.2f, 7.6f, 15.3f, 11.9f},
  {12.0f, 10.5f, 18.0f, 16.5f},
  {12.0f, 10.5f, 18.0f, 16.5f},
  {12.0f, 12.0f, 18.0f, 18.0f},
  {12.0f, 12.0f, 18.0f, 18.0f},
  {8.0f, 8.0f, 16.0f, 16.0f},
  {8.0f, 8.0f, 16.0f, 16.0f}
};

struct OttoGaitState {
  bool active = false;
  OttoMoveMode mode = OttoMoveMode::Idle;
  unsigned long startedAt = 0;
  unsigned long lastSampleAt = 0;
  float straightAssistBaselineYaw = 0.0f;
  bool straightAssistActive = false;
  bool straightDiagnosticAvailable = false;
  bool straightDiagnosticRunning = false;
  unsigned long straightDiagnosticStartedAt = 0;
  unsigned long straightDiagnosticElapsedMs = 0;
  float straightDiagnosticBaselineYaw = 0.0f;
  float straightDiagnosticCurrentYaw = 0.0f;
  float straightDiagnosticYawError = 0.0f;
  float straightDiagnosticMaxAbsYawError = 0.0f;
  OttoMotionProfile motionProfile;
};

enum class BowlingTacticPhase : uint8_t {
  Idle,
  Straight,
  RecoverLeft,
  RecoverRight
};

struct BowlingTacticState {
  bool active = false;
  float targetYaw = 0.0f;
  BowlingTacticPhase phase = BowlingTacticPhase::Idle;
  OttoMotionProfile forwardProfile;
  OttoMotionProfile turnLeftProfile;
  OttoMotionProfile turnRightProfile;
};

struct RobotState {
  bool connected = false;
  bool otaInProgress = false;
  bool servoDriverReady = false;
  String mode = "idle";
  String firmwareVersion = FIRMWARE_VERSION;
  String lastDriverError = "";
  float battery = 7.4f;
  int signalStrength = -100;
  unsigned long lastCommandAt = 0;
  unsigned long nextServoWriteRetryAt = 0;
  uint32_t servoWriteFailures = 0;
  uint8_t consecutiveServoWriteFailures = 0;
  bool imuAvailable = false;
  bool imuCalibrated = false;
  bool imuPoseInitialized = false;
  bool imuFallen = false;
  uint8_t imuAddress = 0;
  float imuRoll = 0.0f;
  float imuPitch = 0.0f;
  float imuYaw = 0.0f;
  float imuTemperature = 0.0f;
  float imuAccelX = 0.0f;
  float imuAccelY = 0.0f;
  float imuAccelZ = 0.0f;
  float imuGyroX = 0.0f;
  float imuGyroY = 0.0f;
  float imuGyroZ = 0.0f;
  float imuGyroBiasX = 0.0f;
  float imuGyroBiasY = 0.0f;
  float imuGyroBiasZ = 0.0f;
  unsigned long lastImuReadAt = 0;
  int servoAngles[SERVO_COUNT] = {
    SERVO_CENTER_ANGLE,
    SERVO_CENTER_ANGLE,
    SERVO_CENTER_ANGLE,
    SERVO_CENTER_ANGLE,
    SERVO_CENTER_ANGLE,
    SERVO_CENTER_ANGLE,
    SERVO_CENTER_ANGLE,
    SERVO_CENTER_ANGLE,
    SERVO_CENTER_ANGLE
  };
  int servoZeroOffsets[SERVO_COUNT] = {
    0,
    0,
    0,
    0,
    0,
    0,
    0,
    0,
    0
  };
  uint16_t servoPwmTicks[SERVO_COUNT] = {
    0,
    0,
    0,
    0,
    0,
    0,
    0,
    0,
    0
  };
  bool servoPwmActive[SERVO_COUNT] = {
    false,
    false,
    false,
    false,
    false,
    false,
    false,
    false,
    false
  };
};

RobotState robotState;
GaitState gaitState;
LateralStepState lateralStepState;
ForwardStepState forwardStepState;
OttoGaitState ottoGaitState;
BowlingTacticState bowlingTacticState;
OttoMotionProfile ottoMotionProfiles[OTTO_MOTION_PROFILE_COUNT] = {
  OTTO_DEFAULT_MOTION_PROFILES[0],
  OTTO_DEFAULT_MOTION_PROFILES[1],
  OTTO_DEFAULT_MOTION_PROFILES[2],
  OTTO_DEFAULT_MOTION_PROFILES[3],
  OTTO_DEFAULT_MOTION_PROFILES[4],
  OTTO_DEFAULT_MOTION_PROFILES[5],
  OTTO_DEFAULT_MOTION_PROFILES[6],
  OTTO_DEFAULT_MOTION_PROFILES[7]
};
bool ottoMotionPreferencesReady = false;
VisionAutopilotState visionAutopilotState;
Task1FrontPoleBypassState task1FrontPoleBypassState;
String visionLineBuffer;
BoundaryGuardState boundaryGuardState;
UltrasonicState ultrasonicState;
struct WifiProfile {
  const char* name;
  const char* ssid;
  const char* password;
  const uint8_t* staticIp;
  const uint8_t* gateway;
  const uint8_t* subnet;
  const uint8_t* dnsPrimary;
  const uint8_t* dnsSecondary;
};

const WifiProfile wifiProfiles[] = {
  {
    "cudy-router",
    WIFI_PRIMARY_SSID,
    WIFI_PRIMARY_PASSWORD,
    WIFI_PRIMARY_STATIC_IP,
    WIFI_PRIMARY_GATEWAY,
    WIFI_PRIMARY_SUBNET,
    WIFI_PRIMARY_DNS_PRIMARY,
    WIFI_PRIMARY_DNS_SECONDARY
  },
  {
    "phone-hotspot",
    WIFI_FALLBACK_SSID,
    WIFI_FALLBACK_PASSWORD,
    WIFI_FALLBACK_STATIC_IP,
    WIFI_FALLBACK_GATEWAY,
    WIFI_FALLBACK_SUBNET,
    WIFI_FALLBACK_DNS_PRIMARY,
    WIFI_FALLBACK_DNS_SECONDARY
  }
};

const char* activeWifiProfileName = "none";

void applyServoAngle(uint8_t servoId, int angle);
void applyServoPhysicalAngle(uint8_t servoId, int physicalAngle, bool updateLogicalState = false);
void initPca9685();
void broadcastStatus();
void centerPose();
void centerPhysicalPose();
void stopAllMotion();
void initBoundaryGuard();
bool updateBoundaryGuard(unsigned long now);
bool isBoundaryGuardConfigured();
void restoreServoOutputs();
bool recoverPca9685IfNeeded(unsigned long now, bool force = false);
void stopLateralStep(bool resetPose = true, const String& nextMode = "idle");
void stopForwardStep(bool resetPose = true, const String& nextMode = "idle");
void stopOttoGait(bool resetPose = true, const String& nextMode = "idle");
void startOttoGait(OttoMoveMode mode, const OttoMotionProfile& profile, bool keepBowlingTactic = false);
void cancelBowlingTactic();
void startBowlingTactic(const JsonDocument& doc);
void updateBowlingTactic(unsigned long now);
void loadOttoMotionProfiles();
void saveOttoMotionProfiles();
void saveOttoMotionProfile(const String& profileName, const OttoMotionProfile& profile);
void appendOttoMotionProfilesJson(JsonObject target);
void applyOttoMotionProfileOverride(OttoMotionProfile& profile, JsonVariantConst source);
const OttoMotionProfile& ottoMotionProfileForMode(OttoMoveMode mode);
OttoMotionProfile resolveOttoMotionProfile(OttoMoveMode mode, JsonVariantConst overrideProfile);
float clampFloat(float value, float minValue, float maxValue);
void commandVisionOttoMode(OttoMoveMode mode, unsigned long now);
void updateTask1BodyAutopilot(unsigned long now);
void updateTask1FrontPoleBypass(unsigned long now);

void appendStringArray(JsonArray target, const char* const items[], size_t count) {
  for (size_t index = 0; index < count; index++) {
    target.add(items[index]);
  }
}

void appendServoIdArray(JsonArray target) {
  for (uint8_t index = 0; index < SERVO_COUNT; index++) {
    target.add(index + 1);
  }
}

void appendServoChannelArray(JsonArray target) {
  for (uint8_t index = 0; index < SERVO_COUNT; index++) {
    target.add(PCA9685_CHANNELS[index]);
  }
}

void appendServoInvertedArray(JsonArray target) {
  for (uint8_t index = 0; index < SERVO_COUNT; index++) {
    target.add(SERVO_INVERTED[index]);
  }
}

void appendServoZeroOffsetArray(JsonArray target) {
  for (uint8_t index = 0; index < SERVO_COUNT; index++) {
    target.add(robotState.servoZeroOffsets[index]);
  }
}

bool isConfiguredBoundaryPin(int pin) {
  return pin >= 0;
}

bool isBoundaryGuardConfigured() {
  return BOUNDARY_GUARD_ENABLED &&
         (isConfiguredBoundaryPin(BOUNDARY_LEFT_FRONT_PIN) ||
          isConfiguredBoundaryPin(BOUNDARY_RIGHT_FRONT_PIN) ||
          isConfiguredBoundaryPin(BOUNDARY_LEFT_REAR_PIN) ||
          isConfiguredBoundaryPin(BOUNDARY_RIGHT_REAR_PIN));
}

void configureBoundaryPin(int pin) {
  if (!isConfiguredBoundaryPin(pin)) {
    return;
  }

  pinMode(pin, BOUNDARY_SENSOR_ACTIVE_LOW ? INPUT_PULLUP : INPUT);
}

bool readBoundaryPin(int pin) {
  if (!isConfiguredBoundaryPin(pin)) {
    return false;
  }

  const int value = digitalRead(pin);
  return BOUNDARY_SENSOR_ACTIVE_LOW ? value == LOW : value == HIGH;
}

bool isConfiguredUltrasonicPin(int pin) {
  return pin >= 0;
}

bool isUltrasonicConfigured() {
  return ULTRASONIC_ENABLED &&
         isConfiguredUltrasonicPin(ULTRASONIC_CENTER_TRIG_PIN) &&
         isConfiguredUltrasonicPin(ULTRASONIC_CENTER_ECHO_PIN);
}

void initUltrasonic() {
  ultrasonicState.enabled = isUltrasonicConfigured();
  if (!ultrasonicState.enabled) {
    return;
  }

  pinMode(ULTRASONIC_CENTER_TRIG_PIN, OUTPUT);
  digitalWrite(ULTRASONIC_CENTER_TRIG_PIN, LOW);
  pinMode(ULTRASONIC_CENTER_ECHO_PIN, INPUT);
}

float readUltrasonicCm(int trigPin, int echoPin, bool& valid) {
  valid = false;
  digitalWrite(trigPin, LOW);
  delayMicroseconds(2);
  digitalWrite(trigPin, HIGH);
  delayMicroseconds(10);
  digitalWrite(trigPin, LOW);

  const unsigned long duration = pulseIn(echoPin, HIGH, ULTRASONIC_ECHO_TIMEOUT_US);
  if (duration == 0) {
    return 0.0f;
  }

  valid = true;
  return static_cast<float>(duration) * 0.0343f / 2.0f;
}

void updateUltrasonic(unsigned long now) {
  if (!ultrasonicState.enabled || robotState.otaInProgress) {
    return;
  }

  if (ultrasonicState.lastReadAt != 0 && now - ultrasonicState.lastReadAt < ULTRASONIC_SAMPLE_INTERVAL_MS) {
    return;
  }

  bool valid = false;
  ultrasonicState.centerCm = readUltrasonicCm(ULTRASONIC_CENTER_TRIG_PIN, ULTRASONIC_CENTER_ECHO_PIN, valid);
  ultrasonicState.centerValid = valid;
  ultrasonicState.lastReadAt = now;
}

void initBoundaryGuard() {
  boundaryGuardState.configured = isBoundaryGuardConfigured();
  configureBoundaryPin(BOUNDARY_LEFT_FRONT_PIN);
  configureBoundaryPin(BOUNDARY_RIGHT_FRONT_PIN);
  configureBoundaryPin(BOUNDARY_LEFT_REAR_PIN);
  configureBoundaryPin(BOUNDARY_RIGHT_REAR_PIN);
}

String boundaryTriggerLabel() {
  if (boundaryGuardState.leftFront && boundaryGuardState.rightFront) {
    return "front_both";
  }
  if (boundaryGuardState.leftFront) {
    return "left_front";
  }
  if (boundaryGuardState.rightFront) {
    return "right_front";
  }
  if (boundaryGuardState.leftRear && boundaryGuardState.rightRear) {
    return "rear_both";
  }
  if (boundaryGuardState.leftRear) {
    return "left_rear";
  }
  if (boundaryGuardState.rightRear) {
    return "right_rear";
  }
  return "";
}

bool updateBoundaryGuard(unsigned long now) {
  boundaryGuardState.configured = isBoundaryGuardConfigured();
  if (!boundaryGuardState.configured || robotState.otaInProgress) {
    boundaryGuardState.active = false;
    return false;
  }

  boundaryGuardState.leftFront = readBoundaryPin(BOUNDARY_LEFT_FRONT_PIN);
  boundaryGuardState.rightFront = readBoundaryPin(BOUNDARY_RIGHT_FRONT_PIN);
  boundaryGuardState.leftRear = readBoundaryPin(BOUNDARY_LEFT_REAR_PIN);
  boundaryGuardState.rightRear = readBoundaryPin(BOUNDARY_RIGHT_REAR_PIN);

  const bool triggered =
    boundaryGuardState.leftFront ||
    boundaryGuardState.rightFront ||
    boundaryGuardState.leftRear ||
    boundaryGuardState.rightRear;

  if (!triggered) {
    boundaryGuardState.active = false;
    return false;
  }

  if (boundaryGuardState.active && now - boundaryGuardState.lastTriggeredAt < BOUNDARY_GUARD_COOLDOWN_MS) {
    return true;
  }

  boundaryGuardState.active = true;
  boundaryGuardState.lastTriggeredAt = now;
  boundaryGuardState.lastTrigger = boundaryTriggerLabel();
  stopAllMotion();
  robotState.mode = "boundary_guard";
  robotState.lastCommandAt = now;
  broadcastStatus();
  return true;
}
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
void loop() {
  socketServer.cleanupClients();

  const unsigned long now = millis();
  static unsigned long lastStatusPushAt = 0;
  static unsigned long lastImuUpdateAt = 0;
  static unsigned long lastImuRetryAt = 0;
  static unsigned long lastWifiReconnectAt = 0;

  updateUltrasonic(now);
  handleVisionSerialInput();
  updateVisionAutopilotTimeout(now);
  updateTask1BodyAutopilot(now);
  updateTask1FrontPoleBypass(now);

  if (!robotState.otaInProgress && updateBoundaryGuard(now)) {
    return;
  }

  if (IMU_MPU6050_ENABLED) {
    if (robotState.imuAvailable) {
      if (now - lastImuUpdateAt >= IMU_UPDATE_INTERVAL_MS) {
        updateImu();
        updateGaitTelemetry();
        lastImuUpdateAt = now;
      }
    } else if (now - lastImuRetryAt >= IMU_RETRY_INTERVAL_MS) {
      initMpu6050();
      lastImuRetryAt = now;
      lastImuUpdateAt = now;
    }
  }

  if (!robotState.otaInProgress) {
    recoverPca9685IfNeeded(now);
  }

  updatePenguinGait();
  updateLateralStep();
  updateForwardStep();
  updateBowlingTactic(now);
  updateOttoGait();

  if (WiFi.status() != WL_CONNECTED) {
    robotState.connected = false;
    if (!robotState.otaInProgress && now - lastWifiReconnectAt >= WIFI_RECONNECT_INTERVAL_MS) {
      lastWifiReconnectAt = now;
      Serial.println("Wi-Fi disconnected, attempting configured profiles");
      connectWifi();
    }
  } else {
    if (!robotState.connected) {
      robotState.connected = true;
      Serial.printf("Wi-Fi reconnected: %s\n", WiFi.localIP().toString().c_str());
      broadcastStatus();
    }
    robotState.connected = true;
    lastWifiReconnectAt = now;
  }

  if (now - lastStatusPushAt >= STATUS_PUSH_INTERVAL_MS) {
    robotState.signalStrength = WiFi.status() == WL_CONNECTED ? WiFi.RSSI() : -100;
    robotState.battery = readBatteryVoltage();
    broadcastStatus();
    lastStatusPushAt = now;
  }

  const bool shouldAutoStop =
    robotState.mode != "idle" &&
    robotState.mode != "servo" &&
    robotState.mode != "servo_trim" &&
    robotState.mode != "servo_trim_reset_all" &&
    robotState.mode != "servo_trim_capture_current_pose" &&
    robotState.mode != "penguin_walk" &&
    robotState.mode != "gait_trial" &&
    robotState.mode != "lateral_step" &&
    robotState.mode != "forward_step" &&
    robotState.mode != "forward_step_2" &&
    robotState.mode != "otto_forward" &&
    robotState.mode != "otto_async_forward" &&
    robotState.mode != "otto_backward" &&
    robotState.mode != "otto_async_backward" &&
    robotState.mode != "otto_left" &&
    robotState.mode != "otto_left_fast" &&
    robotState.mode != "otto_right" &&
    robotState.mode != "otto_shift_left" &&
    robotState.mode != "otto_shift_right" &&
    robotState.mode != "otto_bowling_tactic";

  if (!robotState.otaInProgress && shouldAutoStop && now - robotState.lastCommandAt > SAFETY_TIMEOUT_MS) {
    stopAllMotion();
    robotState.mode = "idle";
    broadcastStatus();
  }
}

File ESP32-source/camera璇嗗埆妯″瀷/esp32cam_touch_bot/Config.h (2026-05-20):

#pragma once

#include <Arduino.h>
#include "TargetTypes.h"

// Wi-Fi monitor. The robot keeps running even if this network is unavailable.
constexpr const char* WIFI_SSID = "yyniPhone";
constexpr const char* WIFI_PASSWORD = "yyn20050810";
constexpr int WIFI_STATIC_IP_A = 172;
constexpr int WIFI_STATIC_IP_B = 20;
constexpr int WIFI_STATIC_IP_C = 10;
constexpr int WIFI_STATIC_IP_D = 11;
constexpr int WIFI_GATEWAY_D = 1;
constexpr int WIFI_SUBNET_A = 255;
constexpr int WIFI_SUBNET_B = 255;
constexpr int WIFI_SUBNET_C = 255;
constexpr int WIFI_SUBNET_D = 0;

// AI Thinker ESP32-CAM pin map
constexpr int PWDN_GPIO_NUM = 32;
constexpr int RESET_GPIO_NUM = -1;
constexpr int XCLK_GPIO_NUM = 0;
constexpr int SIOD_GPIO_NUM = 26;
constexpr int SIOC_GPIO_NUM = 27;

constexpr int Y9_GPIO_NUM = 35;
constexpr int Y8_GPIO_NUM = 34;
constexpr int Y7_GPIO_NUM = 39;
constexpr int Y6_GPIO_NUM = 36;
constexpr int Y5_GPIO_NUM = 21;
constexpr int Y4_GPIO_NUM = 19;
constexpr int Y3_GPIO_NUM = 18;
constexpr int Y2_GPIO_NUM = 5;
constexpr int VSYNC_GPIO_NUM = 25;
constexpr int HREF_GPIO_NUM = 23;
constexpr int PCLK_GPIO_NUM = 22;

// Motor pins (replace with your driver wiring)
constexpr int MOTOR_L_IN1 = 12;
constexpr int MOTOR_L_IN2 = 13;
constexpr int MOTOR_R_IN1 = 14;
constexpr int MOTOR_R_IN2 = 15;

// Optional touch switch pin. LOW means touched by default.
constexpr int TOUCH_SWITCH_PIN = 2;

// Camera / vision tuning
constexpr int FRAME_SAMPLE_STEP = 4;      // bigger -> faster, less accurate
constexpr int MIN_COLOR_PIXELS = 120;
constexpr float DETECT_CONFIDENCE_MIN = 0.60f;
constexpr float EXECUTE_CONFIDENCE_MIN = 0.75f;
constexpr int CONFIRM_FRAMES = 3;

// Servoing thresholds
constexpr int CENTER_TOLERANCE_PX = 16;
constexpr uint32_t SEARCH_TURN_MS = 180;
constexpr uint32_t LOST_TIMEOUT_MS = 900;
constexpr uint32_t LOOP_DELAY_MS = 35;

// Example draw result, change this based on the assigned target.
constexpr TargetSpec TARGET = {ColorId::RED, ShapeId::PYRAMID};

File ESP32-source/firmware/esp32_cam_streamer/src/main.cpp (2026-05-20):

#include <Arduino.h>
#include <Update.h>
#include <WebServer.h>
#include <WiFi.h>
#include <esp_camera.h>
#include <img_converters.h>

#include "camera_pins.h"

#if __has_include("secrets.h")
#include "secrets.h"
#else
#define WIFI_PRIMARY_SSID "YOUR_PRIMARY_WIFI_SSID"
#define WIFI_PRIMARY_PASSWORD "YOUR_PRIMARY_WIFI_PASSWORD"
#define WIFI_FALLBACK_SSID "YOUR_FALLBACK_WIFI_SSID"
#define WIFI_FALLBACK_PASSWORD "YOUR_FALLBACK_WIFI_PASSWORD"
#define CAMERA_HOSTNAME "esp32-cam"
#define CAMERA_USE_STATIC_IP false
#define CAMERA_PRIMARY_STATIC_IP_1 192
#define CAMERA_PRIMARY_STATIC_IP_2 168
#define CAMERA_PRIMARY_STATIC_IP_3 10
#define CAMERA_PRIMARY_STATIC_IP_4 11
#define CAMERA_PRIMARY_GATEWAY_1 192
#define CAMERA_PRIMARY_GATEWAY_2 168
#define CAMERA_PRIMARY_GATEWAY_3 10
#define CAMERA_PRIMARY_GATEWAY_4 1
#define CAMERA_PRIMARY_SUBNET_1 255
#define CAMERA_PRIMARY_SUBNET_2 255
#define CAMERA_PRIMARY_SUBNET_3 255
#define CAMERA_PRIMARY_SUBNET_4 0
#define CAMERA_PRIMARY_DNS_PRIMARY_1 192
#define CAMERA_PRIMARY_DNS_PRIMARY_2 168
#define CAMERA_PRIMARY_DNS_PRIMARY_3 10
#define CAMERA_PRIMARY_DNS_PRIMARY_4 1
#define CAMERA_PRIMARY_DNS_SECONDARY_1 8
#define CAMERA_PRIMARY_DNS_SECONDARY_2 8
#define CAMERA_PRIMARY_DNS_SECONDARY_3 8
#define CAMERA_PRIMARY_DNS_SECONDARY_4 8
#define CAMERA_FALLBACK_STATIC_IP_1 172
#define CAMERA_FALLBACK_STATIC_IP_2 20
#define CAMERA_FALLBACK_STATIC_IP_3 10
#define CAMERA_FALLBACK_STATIC_IP_4 11
#define CAMERA_FALLBACK_GATEWAY_1 172
#define CAMERA_FALLBACK_GATEWAY_2 20
#define CAMERA_FALLBACK_GATEWAY_3 10
#define CAMERA_FALLBACK_GATEWAY_4 1
#define CAMERA_FALLBACK_SUBNET_1 255
#define CAMERA_FALLBACK_SUBNET_2 255
#define CAMERA_FALLBACK_SUBNET_3 255
#define CAMERA_FALLBACK_SUBNET_4 240
#define CAMERA_FALLBACK_DNS_PRIMARY_1 172
#define CAMERA_FALLBACK_DNS_PRIMARY_2 20
#define CAMERA_FALLBACK_DNS_PRIMARY_3 10
#define CAMERA_FALLBACK_DNS_PRIMARY_4 1
#define CAMERA_FALLBACK_DNS_SECONDARY_1 8
#define CAMERA_FALLBACK_DNS_SECONDARY_2 8
#define CAMERA_FALLBACK_DNS_SECONDARY_3 8
#define CAMERA_FALLBACK_DNS_SECONDARY_4 8
#endif

namespace {

constexpr uint32_t kBaudRate = 115200;
constexpr uint32_t kWifiTimeoutMs = 10000;
constexpr uint16_t kServerPort = 80;
constexpr uint8_t kJpegQuality = 80;
constexpr const char* kOtaPath = "/update";

WebServer server(kServerPort);
struct WifiProfile {
  const char* name;
  const char* ssid;
  const char* password;
  IPAddress staticIp;
  IPAddress gateway;
  IPAddress subnet;
  IPAddress dnsPrimary;
  IPAddress dnsSecondary;
};

const WifiProfile wifiProfiles[] = {
  {
    "cudy-router",
    WIFI_PRIMARY_SSID,
    WIFI_PRIMARY_PASSWORD,
    IPAddress(CAMERA_PRIMARY_STATIC_IP_1, CAMERA_PRIMARY_STATIC_IP_2, CAMERA_PRIMARY_STATIC_IP_3, CAMERA_PRIMARY_STATIC_IP_4),
    IPAddress(CAMERA_PRIMARY_GATEWAY_1, CAMERA_PRIMARY_GATEWAY_2, CAMERA_PRIMARY_GATEWAY_3, CAMERA_PRIMARY_GATEWAY_4),
    IPAddress(CAMERA_PRIMARY_SUBNET_1, CAMERA_PRIMARY_SUBNET_2, CAMERA_PRIMARY_SUBNET_3, CAMERA_PRIMARY_SUBNET_4),
    IPAddress(CAMERA_PRIMARY_DNS_PRIMARY_1, CAMERA_PRIMARY_DNS_PRIMARY_2, CAMERA_PRIMARY_DNS_PRIMARY_3, CAMERA_PRIMARY_DNS_PRIMARY_4),
    IPAddress(CAMERA_PRIMARY_DNS_SECONDARY_1, CAMERA_PRIMARY_DNS_SECONDARY_2, CAMERA_PRIMARY_DNS_SECONDARY_3, CAMERA_PRIMARY_DNS_SECONDARY_4)
  },
  {
    "phone-hotspot",
    WIFI_FALLBACK_SSID,
    WIFI_FALLBACK_PASSWORD,
    IPAddress(CAMERA_FALLBACK_STATIC_IP_1, CAMERA_FALLBACK_STATIC_IP_2, CAMERA_FALLBACK_STATIC_IP_3, CAMERA_FALLBACK_STATIC_IP_4),
    IPAddress(CAMERA_FALLBACK_GATEWAY_1, CAMERA_FALLBACK_GATEWAY_2, CAMERA_FALLBACK_GATEWAY_3, CAMERA_FALLBACK_GATEWAY_4),
    IPAddress(CAMERA_FALLBACK_SUBNET_1, CAMERA_FALLBACK_SUBNET_2, CAMERA_FALLBACK_SUBNET_3, CAMERA_FALLBACK_SUBNET_4),
    IPAddress(CAMERA_FALLBACK_DNS_PRIMARY_1, CAMERA_FALLBACK_DNS_PRIMARY_2, CAMERA_FALLBACK_DNS_PRIMARY_3, CAMERA_FALLBACK_DNS_PRIMARY_4),
    IPAddress(CAMERA_FALLBACK_DNS_SECONDARY_1, CAMERA_FALLBACK_DNS_SECONDARY_2, CAMERA_FALLBACK_DNS_SECONDARY_3, CAMERA_FALLBACK_DNS_SECONDARY_4)
  }
};
String activeWifiProfileName = "none";

String jsonPair(const char* key, const String& value, bool quoted = true) {
  String pair = "\"";
  pair += key;
  pair += "\":";
  if (quoted) {
    pair += "\"";
    pair += value;
    pair += "\"";
  } else {
    pair += value;
  }
  return pair;
}

bool initCamera() {
  camera_config_t config = {};
  config.ledc_channel = LEDC_CHANNEL_0;
  config.ledc_timer = LEDC_TIMER_0;
  config.pin_d0 = Y2_GPIO_NUM;
  config.pin_d1 = Y3_GPIO_NUM;
  config.pin_d2 = Y4_GPIO_NUM;
  config.pin_d3 = Y5_GPIO_NUM;
  config.pin_d4 = Y6_GPIO_NUM;
  config.pin_d5 = Y7_GPIO_NUM;
  config.pin_d6 = Y8_GPIO_NUM;
  config.pin_d7 = Y9_GPIO_NUM;
  config.pin_xclk = XCLK_GPIO_NUM;
  config.pin_pclk = PCLK_GPIO_NUM;
  config.pin_vsync = VSYNC_GPIO_NUM;
  config.pin_href = HREF_GPIO_NUM;
  config.pin_sccb_sda = SIOD_GPIO_NUM;
  config.pin_sccb_scl = SIOC_GPIO_NUM;
  config.pin_pwdn = PWDN_GPIO_NUM;
  config.pin_reset = RESET_GPIO_NUM;
  config.xclk_freq_hz = 20000000;
  config.pixel_format = PIXFORMAT_RGB565;
  config.frame_size = FRAMESIZE_240X240;
  config.jpeg_quality = 20;
  config.fb_count = psramFound() ? 2 : 1;
  config.grab_mode = CAMERA_GRAB_WHEN_EMPTY;
  config.fb_location = CAMERA_FB_IN_PSRAM;

  const esp_err_t err = esp_camera_init(&config);
  if (err != ESP_OK) {
    Serial.printf("Camera init failed: 0x%x\n", err);
    return false;
  }

  sensor_t* sensor = esp_camera_sensor_get();
  if (sensor != nullptr) {
    sensor->set_vflip(sensor, 1);
    sensor->set_brightness(sensor, 1);
    sensor->set_saturation(sensor, -1);
  }

  return true;
}

bool connectWifiProfile(const WifiProfile& profile) {
  WiFi.disconnect(false, true);
  delay(100);

  if (CAMERA_USE_STATIC_IP && !WiFi.config(
        profile.staticIp,
        profile.gateway,
        profile.subnet,
        profile.dnsPrimary,
        profile.dnsSecondary
      )) {
    Serial.printf("Static IP configuration failed for %s\n", profile.name);
  }

  WiFi.begin(profile.ssid, profile.password);
  Serial.printf("Connecting to WiFi (%s): %s\n", profile.name, profile.ssid);

  const uint32_t startedAt = millis();
  while (WiFi.status() != WL_CONNECTED && millis() - startedAt < kWifiTimeoutMs) {
    delay(300);
    Serial.print('.');
  }

  if (WiFi.status() != WL_CONNECTED) {
    Serial.printf("\nWiFi connect failed for %s\n", profile.name);
    return false;
  }

  activeWifiProfileName = profile.name;
  Serial.println();
  Serial.print("Camera IP: ");
  Serial.println(WiFi.localIP());
  return true;
}

bool connectWifi() {
  WiFi.mode(WIFI_STA);
  WiFi.setSleep(false);
  WiFi.setHostname(CAMERA_HOSTNAME);
  activeWifiProfileName = "none";

  for (const WifiProfile& profile : wifiProfiles) {
    if (connectWifiProfile(profile)) {
      return true;
    }
  }

  Serial.println("WiFi connect failed for all configured profiles");
  return false;
}
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
